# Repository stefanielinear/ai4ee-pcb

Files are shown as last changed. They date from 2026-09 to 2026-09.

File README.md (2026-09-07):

# ai4ee-pcb

[简体中文](README.zh-CN.md)

A collection of PCB projects that are automatically designed and generated by AI.

All projects are designed in **KiCad**. This repository hosts PCB projects produced by an AI agent (LLM toolchain) end to end — from requirements specification and part selection, through schematic entry, layout and routing, design review, to fabrication file export. Each sub-project lives in its own directory and can be opened directly in KiCad; it ships with the design sources, design documentation, and a fabrication package.

## Sub-projects

| Sub-project | Description | Status | Model / tokens |
| --- | --- | --- | --- |
| [ECG12_Portable](ECG12_Portable/README.md) | Portable 12-lead ECG acquisition board (engineering sample): KiCad 10, 45 × 45 mm 4-layer board, 110 purchased components, 14 test points, 6 double-sided fiducials, Rev B | Routed (native ERC / DRC: 0 violations, 0 unconnected), prototype validation pending | GPT-6 High, ~580k tokens |

## License

[Apache License 2.0](LICENSE)

> ⚠️ Each sub-project is an engineering sample and does **not** represent medical-device certification. For projects that interface with the human body (e.g., ECG), safety and compliance must be assessed separately per the documentation in the sub-project.

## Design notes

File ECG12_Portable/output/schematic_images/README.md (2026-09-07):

# 原理图图片

01_System 至 05_Power 为 300 dpi 阅读版 PNG，保留全部电路和页内说明，裁去空白和图框。full_pages/ 为含完整图框和标题栏的原图。index.html 可逐页浏览；schematic_full.pdf 为此次从当前 KiCad 源文件重新导出的完整 PDF。

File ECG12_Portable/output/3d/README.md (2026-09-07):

# Rev B 3D previews

Generated from the saved Rev B PCB using the native KiCad renderer. 110 package models: 107 standard KiCad models and three visual approximations (U2 module, J2 USB-C, U3 generic QFN). Fourteen test pads and six fiducials have no physical package. Model coverage and source hash are in model_coverage.json. Use manufacturer drawings for mechanical approval.

ECG12_Portable2.kicad_pcb in this directory is a render copy; edit the project-root PCB for design work. Models resolve locally through the models directory.

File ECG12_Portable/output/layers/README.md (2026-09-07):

# PCB 各图层截图

打开 index.html 按层浏览。全部启用层均单独导出，包括空的辅助层；网页默认隐藏空层，勾选开关即可显示。所有图片从顶面观察，底层未镜像，便于各层对齐比较。板框是唯一公共叠加层。F.Mask/B.Mask 显示阻焊开窗；F.Paste/B.Paste 显示焊膏开口。未改变设计源文件。

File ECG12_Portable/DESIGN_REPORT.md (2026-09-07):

# ECG12 Portable2 Rev B 设计报告

## 交付状态与边界

工程、完整布线及生产输出均已生成。板框 45 × 45 mm，4 层，130 个封装，其中 110 个是采购器件、14 个是板上测试触点、6 个是双面光学定位点。原生 ERC 为 0 错误、6 警告；原生 DRC 为 0 项、0 未连接、0 原理图/PCB 差异。没有通过关闭规则或排除真实短路来取得这些结果。

该结论表示设计文件通过所执行的电气/几何检查，**不表示医疗认证、临床适用性或样机性能已经验证**。固件、机壳和临床验证不在本次硬件文件交付内。

## Product Specification / Architecture

| 项目 | 实现 |
|---|---|
| 电极 | RA、LA、LL、V1–V6、RL，共 10 电极 |
| 同步通道 | ADS1298，8 通道、24 bit、500 SPS |
| 导联 | CH1=LA−RA；CH2=LL−RA；CH3–8=V1–V6−WCT |
| 推导导联 | III=II−I；aVR=−(I+II)/2；aVL=I−II/2；aVF=II−I/2 |
| 参考 | 内部 2.4 V；PGA=6，标称差分满量程 ±400 mV |
| 输入范围 | 设计包络 ±300 mV 电极差分直流偏置叠加 ±5 mV ECG；还受共模余量约束 |
| 显示带宽 | 0.5–40 Hz 监护视图；保留原始数据。500 SPS 下 sinc 滤波约在 131 Hz 衰减 3 dB，不声称平坦 150 Hz 诊断带宽 |
| 输入阻抗目标 | ≥10 MΩ @10 Hz，须包含保护元件、PCB 污染及线缆实测 |
| CMRR 目标 | RLD 工作时系统 ≥80 dB @50/60 Hz；不是把芯片指标当作系统保证 |
| 蓝牙 | Raytac MDBT42Q-512KV2，nRF52832，集成晶振、匹配和芯片天线 |
| 缓存 | SoC 64 KiB RAM 中分配 32 KiB 采集环形缓冲；无需外部存储器 |
| 供电 | 带保护的 1S 500 mAh 电池；USB-C 5 V 充电；独立模拟/数字 3.0 V LDO |
| 使用模式 | 患者/电极连接时仅允许电池供电；充电和接地调试时断开电极 |

WCT 三个内部缓冲器分别取 CH1N、CH1P、CH2P；对应 WCT1=0x09、WCT2=0xC2。WCT 输出接六个胸导联负输入，C25 为 100 pF C0G。该值按 TI 数据手册第 40–41 页附近的 WCT 说明及 [TI 的澄清](https://e2e.ti.com/support/data-converters-group/data-converters/f/data-converters-forum/841268/ads1298r-wct-capacitor-100pf-or-1000pf)选择。

## Component Selection / 供应与成本

| 位号 | 实际型号 | 选择依据 |
|---|---|---|
| U1 | ADS1298IPAG | 成熟的同步 ECG AFE，内部参考、WCT、RLD 和导联脱落检测；TQFP 便于检验与返修 |
| U2 | MDBT42Q-512KV2 | nRF52832 模块，将晶振、RF 匹配和天线纳入厂家验证的模块结构 |
| U3 | BQ24074RGTR | 线性充电、电源路径、温度检测、输入限流和安全计时 |
| U4/U5 | TPS7A2030PDBVR | 独立 3.0 V 低噪声 LDO，避免外置开关电源干扰 |
| D1–D10、D21–D23 | TPD1E10B06DYAR | 电极连接器与 USB 侧 ESD 保护 |
| D11–D19 | BAV199,215 | 低漏电输入钳位；明确核对 SOT-23 的 1=A1、2=K2、3=公共端 |
| D24 | BAT54H,115 | USB PGOOD 拉低时抑制 AFE 采集；不是隔离器件 |
| J1/J3 | JST BM10B / BM04B-SRSS-TB | 1 mm 有键连接器，明确电极与电池/NTC 引脚顺序 |
| J2 | HRO TYPE-C-31-M-12 | 仅供电的 USB-C 连接；CC1/CC2 独立 Rd，数据与 SBU 不连接 |

采购字段来自原理图，完整清单见 `production/BOM.csv`。2026-09-06 查询的公开页面显示：[ADS1298IPAG](https://www.digikey.com/en/products/detail/texas-instruments/ADS1298IPAG/2360825) 为 Active，页面库存 435，单件参考价 US$58.94；[MDBT42Q-512KV2](https://www.digikey.com/en/products/detail/raytac/MDBT42Q-512KV2/13677592) 页面库存 18、单件 US$4.95，属于厂家 Marketplace 发货。库存和交期是网页快照，订单前需重新确认。

[TPS7A2030PDBVR](https://www.ti.com/product/TPS7A20/part-details/TPS7A2030PDBVR) 为 Active；TI 直销库存显示不可用，但 [授权渠道页面](https://www.digikey.jp/en/products/detail/texas-instruments/TPS7A2030PDBVR/13566871)列有库存。没有为所有被动器件执行实时逐行库存/API 生命周期审计；此项作为采购阶段限制保留。

单板小批量器件预算暂按 US$75–100 规划，不含电池、线束、PCB、填孔盖铜、贴装、运输和税费。这是预算区间，不是完整供应商报价。AFE 是主要成本；本版优先成熟 ECG 性能和制造可复核性，没有采用未经验证的廉价替代 AFE。填孔盖铜会增加制造费用，须由工厂按实际清单报价。

## Power Budget / 八小时续航

| 项目 | 估算平均电池侧电流 |
|---|---:|
| AFE，包括参考/WCT/RLD 预留 | 4.0 mA |
| MCU 处理 | 3.0 mA |
| BLE 收发折算平均值 | 4.0 mA |
| 稳压器、充电器待机预留 | 0.1 mA |
| 状态灯、分压、其他 | 1.0 mA |
| 合计估算 | 12.1 mA |
| 用于续航设计的保守包络 | **20 mA** |

两路 LDO 的电池电流基本等于负载电流加静态电流，不能再用输出电流直接乘电压比重复折算效率。3.7 V 电池到 3.0 V 的理想功率效率约 81%；以上电池侧预算已经包含其线性损耗的电流特征。

八小时所需有效容量为 20×8=160 mAh。以低压停止、老化、温度和容量离散合计只使用额定 70% 计算，最低额定需求为 160/0.70≈229 mAh；选择 500 mAh，估算 500×0.70/20=17.5 h。相对 8 h 约有 2.19 倍时长裕量。**这是计算，不是续航实测**；固件需在约 3.3 V 低电压时停止采集并进入低功耗状态。

外部原型电池可选 [Adafruit 1578](https://www.adafruit.com/product/1578)（500 mAh，29×36×4.75 mm，自带保护），增加贴附于电芯的 Semitec 103AT-2 10 kΩ NTC 和适配线束。量产电池必须保持 1S 4.2 V 充电、保护板、容量和 NTC 特性，重新验证后才能替换。

USB 使用 100 mA 总输入限流模式。R38 改为 8.66 kΩ、1%，其最大值 8.7466 kΩ 低于推荐上限 8.9 kΩ；标称 ISET 编程值为 102.77 mA，实际充电电流受 100 mA 输入限流、系统负载和电源路径调节限制。R39=68.1 kΩ，按 KTMR=48 s/kΩ 得到标称快充安全计时 9.08 h；电阻与计时系数的静态范围约 6.742–11.464 h，动态降流可能改变实际到期时间。ITERM 未连接时，USB100 模式的标称终止比例为 3.3%，即约 3.39 mA。

自动热分析没有识别出可量化耗散的器件，不能据此称为通过。Rev B 另提供可复算的 `analysis/revB/thermal_engineering_model.json`：USB 5.25 V、电芯 3.0 V、100 mA 包络对应 0.225 W，计入通路和静态电流余量后按 U3=0.25 W；U4/U5 在 VSYS=4.5 V、负载分别 6/14 mA 时约 9.045/21.045 mW。U3 的 θJA=44.5 °C/W 来自数据手册测试板，120 °C/W 是未校准的外壳敏感性场景；40 °C 环境对应估算结温 51.1–70.0 °C。U3 暴露焊盘内已布置四颗 0.60/0.30 mm 接地热过孔，全部填孔盖铜。真实温升、NTC 耦合和外壳散热必须实测；不得据此提高充电限流。

## ECG Data Budget / BLE 与缓存

8×500×24=96 kbit/s 原始 ECG。加每帧 3 字节状态，共 13,500 byte/s；建议再加入时间戳/标志，按 32 byte/frame 即 16,000 byte/s 预算。再预留 10% 序号、CRC 和应用协议开销，需求约 140.8 kbit/s。

要求实测应用层有效吞吐 ≥200 kbit/s。250 ms 聚合 4,000 byte，额外预留 10% 应用协议开销后约 4,400 byte；在 25,000 byte/s 下发送约 176 ms，正常连接时最老样本基础等待加发送约 426 ms。与 1 s 目标相差约 574 ms，供连接事件、重传和调度使用。32 KiB RAM 可容纳约 2.048 s 的 32 字节帧；无线失联不能保证 1 s 延迟。

需要在最终 BLE 栈内存配置下检查链接映射、RAM 水位、MTU/DLE 协商及中央设备兼容性。本次交付完成了容量和带宽可行性计算，没有伪称已经运行过整机 BLE 吞吐测试。

## Analog Layout / 输入、参考和 RLD

电极连接器在左侧，AFE 居中偏左，BLE 天线在右上板边，USB/充电在右下。每个感测电极经过连接器侧 TVS、两个 100 kΩ 0.1% 电阻、低漏电钳位与 C0G 电容。保护/滤波不会把主滤波极点压到 ECG 通带内：按总输入电容约 240 pF、总串联电阻 200 kΩ，极点约 3.32 kHz。两个输入路径的电阻热噪声按 150 Hz 理想砖墙积分约 1.0 µVrms，不包含 AFE、线缆和实际数字滤波响应。

RA 同时接两个 ADC 输入，C1=200 pF；其他输入 C2–C9=220 pF，用于名义补偿输入电容差异。器件内部电容、WCT 取样、线缆和寄生有离散，不能据名义 RC 匹配保证 CMRR；必须实测并确定是否需要匹配/调整电容。 Rev B 将 C1–C9 换为同系列 1% C0G：C1 为 KEMET C0402C201F5GACTU，C2–C9 为 C0402C221F5GACTU。仅含理想 RC 与典型 20 pF 输入电容的 50 Hz 容差例子从 57.40 dB 改善到 70.63 dB；该例子排除了电极、线缆及闭环 RLD/WCT，不能当作系统 CMRR 结果。

钳位器件在背面靠近对应输入，关键电阻串联连接在正面锁定布线。RLD 采用 100 kΩ/100 kΩ、100 nF 外部半电源参考，1 MΩ∥1.5 nF 反馈，以及两个 499 kΩ 串联到 RL。RLD_IN 未使用时接 AVDD；导联脱落检测和 RLD 选路要避免重复计入共享 RA。 R24/C27 已靠近 U1 引脚 61/63：RLD_INV 共 4.188 mm、0 过孔。R28–R30 靠近模块输出脚，其中 R29 前 MCU_SCK 仅 2.090 mm、0 过孔。

## PCB / RF Layout / 可制造性

板框 45×45 mm；名义厚度 1.0 mm；外层铜 35 µm，内层铜 18 µm；F.Cu 信号/器件、In1.Cu 完整接地参考、In2.Cu 信号、电源与 B.Cu 信号/器件。具体介质厚度已经写入工程，工厂可提出等厚标准叠层供复核，不能自行改变铜层顺序。

最小线宽/间距 0.15/0.15 mm；普通过孔焊盘/钻孔 0.60/0.30 mm；铜到板边 ≥0.25 mm。电源主路径在可用位置使用较宽走线；模拟/数字 LDO 输出各有连接到真实焊盘的局部电源铜区。In1 不布信号线，实际接地铜为一个连通区域，面积约 1,837.6 mm²，约占板面积 90.7%；顶/底层地铜通过接地过孔连通。

天线外露部分及模块内部规定的凹形禁布区域在所有铜层都有显式规则区，禁止走线、过孔、焊盘和铺铜。模块自带 RF 匹配和天线，主板没有需单独控制 50 Ω 的 RF 馈线。电池、金属机壳和线束不得进入天线净空范围。BLE SoC 使用 LDO 模式、内部校准 LFRC；高频晶振在模块内部。

填孔盖铜要求逐孔记录于 `production/filled_capped_vias.csv`。该表按钻孔与 SMT 焊盘相交的保守几何条件生成，并在 KiCad 过孔属性中标记 filled/capped；部分位置不位于焊盘中心，但仍有吸锡风险。其余过孔双面盖油。所有贴片器件的方向使用 KiCad 原生坐标导出；底层坐标为从顶面观察的装配坐标，工厂按自身设备规则转换角度。针脚 1、USB 外壳、J1/J3 键位、BAV199 极性以及 QFN 暴露焊盘均按网表、封装和数据手册交叉核对。

85 个位号放在丝印，其余保留在完整装配图。新增正反面各三个非共线定位点；USB-C 定位孔中心到下板边按厂家图修正为 5.79 mm。电池与线束通过外部固定结构定位；板上没有安装孔。

## ERC / DRC 与检查依据

| 检查 | 结果/依据 |
|---|---|
| KiCad 原生 ERC | 0 错误，6 警告；最终 JSON 随生产包提供 |
| KiCad 原生 DRC | 0 违规，0 未连接；重新铺铜后运行 |
| 原理图/PCB 一致性 | 原生 schematic parity 0 项 |
| 原理图/PCB 原生端点核对 | 124 个原理图器件（含 14 个测试点）、390 个网表端点，端点网络差异 0；另有 6 个 board-only 定位点 |
| 原理图新增节点 | 六个测试点使用原生符号、导线和全局网络标签，ERC 与原生网表校验通过 |
| SPICE | 已执行自动子电路仿真；输入小电容被误判为去耦的警告在下文处理 |
| KiCad/PCB/跨域/EMC/热分析器 | 均实际运行，原始结果保留；热工具无耗散数据而跳过数值估算 |
| Gerber/Drill | 已实际导出并解析检查；文件非空、铜层/孔数据存在 |
| 原始数据手册检查 | 逐脚核对主 IC 的供电、保留脚、时钟、参考、充电设定和模块外部元件要求 |

6 项 ERC 警告全部保留：U1 引脚 17、18 按 [ADS1298 数据手册](https://www.ti.com/lit/ds/symlink/ads1298.pdf)“未用引脚接 AVDD”的脚注处理，固件必须关闭 PACE 输出；引脚 42、44、45、46 接地，GPIO 必须保持输入。没有把这些双向引脚类型改成被动脚来隐藏提示。

## EMC / 分析器结果的工程复核

EMC 分析器不是医疗 EMC 认证工具，其数值评分不作为放行证据。未删除原始 finding，也未把所有启发式提示当作真实阻断项：

- GP-001 / RP-001 将 USB_PGOOD 按名称当成高速 USB 信号；实际为 10 kΩ 上拉的开漏插拔状态线。这两项的高速风险分类不适用。
- GP-004 的低铺铜比主要来自正面地铜被器件和信号分割；原始 PCB 中 In1 地平面约 90% 覆盖、单一连通区域。不能用正面约 56% 的铺铜比例代替内层参考面。
- In2 与 B.Cu 为相邻信号层是实际叠层折中。主参考面为 In1，顶/底有地铜；SPI 应限制在约 1 MHz 并保留源端 33 Ω。这项残余串扰/辐射风险留待实测。
- AFE_SCK、MCU_SCK 等个别换层点在 1 mm 内放不下接地过孔；已补可放置的回流过孔，其余位置、最近地过孔距离保留在 `return_stitching.json`。部分为同一 In1 参考面的两侧换层，不能等同于跨分割地，但仍应测试 BLE 发射期间的干扰和 EMC。
- J1 没有把系统 GND 作为患者接口引出；RL 是受限流的患者偏置，这是有意的接口定义。
- SPICE 把 220 pF 的 C4–C9 当作电源去耦，故给出高阻抗警告；这些实际是输入 RF 滤波电容，该去耦判据不适用。RLD 的芯片内部放大器没有完整厂商宏模型，因此不能用被动子电路仿真声称 RLD 稳定性已通过。
- 自动热过孔规则按通用高功耗封装建议更多过孔。本版是 100 mA 线性充电，采用实际 EP 接地过孔和局部地铜，并以保守温升计算与样机温升测试控制风险。

## Manufacturing Output / 样机验证

`production/gerber/` 包含 4 个铜层、双面阻焊/丝印/钢网层、板框及 Gerber job；`production/drill/` 包含分离的 PTH/NPTH 钻孔和孔位图；另有 BOM、贴片坐标、裸板电测网表、原理图与装配 PDF、填孔盖铜表和工厂说明。

样机必须验证：短路输入噪声、CMRR、输入阻抗、直流偏置/共模极限、lead-off、RLD 稳定性、50/60 Hz 抑制、天线与外壳/电池耦合、BLE TX 对 ECG 的影响、ESD/EMI、实际吞吐和最大样本年龄、RAM 溢出处理、≥8 h 续航、充电终止/计时与温升。USB 充电期间的信号/干扰测试只用 ECG 模拟器，不能接人体。该板不具备 USB 医疗隔离、除颤或电外科保护，不声称满足任何医疗法规。

## Rev B 电源电容与剩余审查风险

C31/C34–C37 改为 TDK 4.7 µF/16 V/X5R/0603；C32/C33 改为 TDK 22 µF/25 V/X5R/0805。逐料号偏压曲线、工程折算条件和验收下限见整改报告。RLD、CMRR、有效电容及充电温升必须按样机计划验收。最新 EMC 启发式结果及其原生几何交叉检查也在整改报告中，不能沿用旧版数值评分代替本版结论。

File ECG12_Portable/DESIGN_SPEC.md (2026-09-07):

# ECG12 Portable2 — Revision B design specification

Status: routed engineering prototype; native ERC has 0 errors/6 reviewed warnings, DRC has 0 violations/0 unconnected/0 parity differences. System acceptance requires bench verification. Not medically certified.

## Requirements and decisions

- Ten electrodes: RA, LA, LL, V1–V6 and RL. ADS1298IPAG measures I=LA−RA, II=LL−RA and six chest leads relative to its internal Wilson central terminal. Firmware derives III=II−I, aVR=−(I+II)/2, aVL=I−II/2, aVF=II−I/2.
- 500 samples/s/channel, simultaneous 24-bit acquisition; low-power converter mode, internal oscillator. Nominal 0.5–40 Hz monitoring display, with raw samples retained. The converter sinc response is about -3 dB at 131 Hz at 500 SPS; a flat 150 Hz diagnostic bandwidth is not claimed. A 1 kSPS mode requires a revised data/power budget.
- 3.0 V analog supply, 2.4 V internal reference, nominal PGA gain 6: differential ADC full-scale ±400 mV, subject to input common-mode headroom. Electrode DC offset and saturation recovery require prototype verification.
- Input impedance target ≥10 MΩ at 10 Hz; CMRR target ≥80 dB at 50/60 Hz with RLD (system targets, not proven results). Matched input RC filtering, low-leakage clamps, current limiting and internal lead-off detection. Internal RLD amplifier, compensated feedback, two series patient-bias resistors. Component/parasitic capacitance matching must be characterized on prototypes.
- RF module with nRF52832, 64 KiB RAM, 512 KiB flash, integrated high-frequency crystal, matching and chip antenna. Internal low-frequency RC clock with calibration. No external data flash.
- 8×500×24=96 kbit/s raw ECG; including 24-bit status each frame gives 13,500 byte/s. Allocate 32 KiB circular acquisition buffer. Packetize every 250 ms, require ≥200 kbit/s measured application payload throughput. A 32-byte application record plus 10% overhead gives 4,400 bytes per 250 ms batch, draining in 176 ms at that service rate; nominal oldest-sample delivery is 426 ms plus connection/retry delays. ≤1 s is an acceptance target under a specified compatible BLE central; outage cannot guarantee latency.
- 1S protected rechargeable Li-polymer battery, minimum 500 mAh, 10 kΩ NTC coupled to cell. USB-C is 5 V charging only, two independent 5.1 kΩ Rd resistors, data pins unconnected. Charger with power-path and cell temperature monitoring; conservative default USB current limit.
- Independent low-noise analog 3.0 V and digital 3.0 V LDOs. Battery low-voltage stop target 3.3 V; usable-capacity derating accounts for cutoff, temperature and aging.
- Preliminary battery-current budget: AFE 4 mA, MCU 3 mA, BLE 4 mA average, regulators 0.1 mA, miscellaneous 1 mA =12.1 mA. Use 20 mA engineering design envelope; 500 mAh×0.70/20 mA=17.5 h estimated runtime, over 2× eight-hour requirement. Must be measured with final firmware, cell and RF link.
- Board 45×45 mm maximum, four copper layers: front components/signals, continuous inner GND, inner power/slow signals, back signals/GND. 1.0 mm nominal stack, 35 μm outer copper; fabricator must confirm final dielectric stack.
- Initial routing limits: 0.15 mm trace/clearance, 0.6/0.3 mm through vias; power wider where space permits. Inner GND reserved for return continuity. No copper, vias or traces in antenna keepout on any layer.
- Interfaces: keyed ten-electrode connector, keyed battery/NTC connector, USB-C, SWD programming/test pads, status LED and battery voltage measurement.
- Charging is a non-patient-connected mode: no galvanic USB isolation is included. Enclosure/workflow must prevent patient connection while USB or a grounded programmer is attached. Hardware is not defibrillator protected or suitable for electrosurgery. Simulator-only testing precedes any patient use.

## Acceptance evidence required

Editable local KiCad symbols/footprints; native schematic-to-board net correspondence; complete routing; filled planes; native ERC and DRC reports; BOM/positions/Gerber/drill exports; schematic and fabrication/assembly PDFs; explicit remaining prototype tests for noise, CMRR, lead-off, RLD stability, antenna, ESD/EMC, charging thermal behavior and runtime.

## Revision B implementation

Three fiducials per side; 14 test contacts including six new analog/power nodes; USB locating-hole-to-edge datum 5.79 mm; 8.66 kΩ RISET; 9.08 h nominal timer; 3.3% USB100 termination; 1% C0G input capacitors; upgraded MLCCs with documented bias margins; local RLD and source-SPI routing; four filled/capped charger EP vias. See REV_B_OPTIMIZATION_REPORT.md for measurements and remaining acceptance work.

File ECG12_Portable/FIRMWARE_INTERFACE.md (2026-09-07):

# Firmware integration contract — ECG12 Portable2 Rev B

This is a hardware interface/acceptance specification, not tested firmware.

| Function | nRF52832 GPIO / module pin |
|---|---|
| AFE CS, SCK, MOSI | P0.11/25, P0.12/26, P0.13/27 via 33 ohm series resistors |
| AFE MISO, DRDY | P0.14/28, P0.15/29 |
| AFE RESET, PWDN | P0.16/30, P0.17/31 |
| USB PGOOD, charge status | P0.25/2, P0.26/3; active low, external 10k pull-ups |
| Battery ADC | P0.31/8; 1M/1M divider, 10nF filter; Vbat=2×Vadc |
| Status LED | P0.22/38, active-low sink through fitted resistor/LED |
| Reset, SWDCLK, SWDIO | P0.21/35, dedicated pins 36 and 37 |
| UART TX/RX | P0.06/19, P0.07/20 |

TP1..TP8: DVDD, GND, SWDCLK, SWDIO, MCU_RESET, UART_TX, UART_RX, AFE_CLK.

TP9..TP14 (back side): VBAT, VSYS, AVDD, VREF, RLD_REF, RLD_OUT. Use high-impedance, low-capacitance probes on analog nodes.

Rev B charging: USB100 is a 100 mA total input limit. RISET=8.66 kΩ programs 102.77 mA nominal; USB100 default termination is about 3.39 mA (3.3%). RTMR=68.1 kΩ gives a nominal 9.08 h fast-charge safety timer; static factor/resistor range 6.742–11.464 h, with dynamic timer behavior to be verified.

1. Use the module in LDO mode. External DCC network is absent. Configure the calibrated internal low-frequency RC oscillator; the module's shipped factory test firmware must be replaced. Its internal 32 MHz oscillator and DEC4 bypass are already fitted.
2. Configure ADS1298 for low-power 500 SPS, internal clock, 2.4 V internal reference, gain 6 and eight active normal-input channels. Verify readback of all registers. START pin is low: issue SPI START/STOP commands. Read the complete 27-byte status+sample frame per DRDY. Use approximately 1 MHz SPI initially.
3. WCT1=0x09 and WCT2=0xC2 enable RA=CH1N, LA=CH1P, LL=CH2P. CH3–8 negative inputs are physically tied to WCT. Internal augmented-lead switches remain disabled. Derive III/aVR/aVL/aVF digitally.
4. RLD uses external half-supply reference and external compensation. Select limb electrodes without repeatedly counting shared RA. Start with lead-off disabled for noise/CMRR characterization; enable only after verifying currents and thresholds on the simulator.
5. U1 PACE/test pins 17/18 are tied to AVDD; keep their output drivers disabled. GPIO1–4 are tied to GND and must remain inputs. DAISY_IN and RESV1 are grounded.
6. Stop acquisition whenever USB_PGOOD is low. D24 provides a hardware pull-down path to AFE_PWDN; it does not provide galvanic isolation. Use high-impedance MCU behavior compatible with this clamp rather than actively driving PWDN high against it. Disconnect electrodes for USB/debug operations.
7. Reserve 32 KiB for a bounded ring buffer. Budget a 32-byte application record (24 sample bytes, 3 status bytes, timestamp/flags). Flush every 250 ms. Verify BLE stack RAM, stack/heap headroom and linker placement on the actual 64 KiB device.
8. Negotiate suitable MTU/data length; require measured application throughput >=200 kbit/s. Timestamp and sequence every batch, account for CRC/protocol overhead, reject stale data, report sequence gaps. Under the validated connected-link test condition, maximum delivered sample age must stay <=1 s. No such guarantee is possible during disconnection.
9. Observe battery voltage, stop around 3.3 V under load with hysteresis, and enter low power. Test cell recovery, reconnect, brownout and interrupted-transfer behavior.
10. Verify at least 8 hours runtime with full-rate ECG, worst intended BLE use, chosen cell, representative aging/temperature and final enclosure.

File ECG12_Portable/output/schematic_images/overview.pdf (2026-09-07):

# ECG12 Portable2 - Schematic pages

# Five pages | Individual PNG files at 300 dpi | Full drawing sheets also included

# 01 System

# Inputs

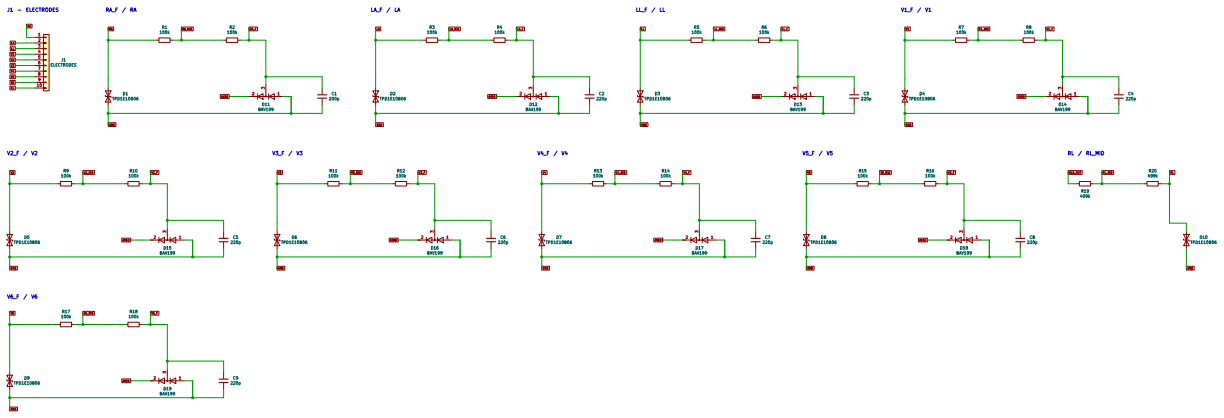
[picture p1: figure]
TPD1E10B06; TPD1E10B06 D7; 3 D13 BAV199; 3 D14 BAV199 D4; J1 ELECTRODES; 3 D11 BAV199 C8; 3 D18 BAV199; 3 D17 BAV199 R16; TPD1E10B06 R9; 3 D15 BAV199 R18; 3 D19 BAV199 R11; 3 D12 BAV199 D6; 3 D16 BAV199 C6; GND; V1_MID; RL_MID; LL_MID; AVDD; RA_MID; RLD_OUT RA_F; LA_MID; V5_MID; V2_MID; V3_MID; RL V6GND; V6_MID; V6_F GND; V4_MID; GND J1 - ELECTRODES; RL / RL_MID

# File: Inputs.kicad_sch

# AFE

# File: AFE.kicad_sch Digital File: Digital.kicad_sch

Power File: Power.kicad_sch 12-lead portable ECG — 10 electrodes, 8 simultaneous 24-bit channels

# 45 x 45 mm, 4 layers; protected 1S cell; USB-C charging; BLE batches <=1 s target

Read DESIGN_SPEC.md and DESIGN_REPORT.md before prototype assembly.

Only connect electrodes when running from battery; USB/programming requires electrode removal.

02 Inputs | D3

ELECTRODE PROTECTION / MATCHED RF FILTERS

RA/LA/LL and V1-V6: TVS -> 2x100k -> low-leakage clamp -> C0G -> AFE. V2_F / V2

All C0G capacitors 50 V. Match total input capacitance during CMRR verification. RL: 2x499k series output limit. No defibrillator or electrosurgical protection. RA_F / RA

03 AFE | C18

22u C25

100p

## #FLG6 PWR_FLAG

R22
100k | C26

100n C15

100n | C17 1u

## IN8N 1

## IN8P 2

## IN7N 3

## IN7P 4

## IN6N 5

## IN6P 6

## IN5N 7

## IN5P 8

## IN4N 9

## IN4P 10

## IN3N 11 IN3P 12

## IN2N 13 IN2P 14

## IN1N 15 IN1P 16

## TESTP_PACE_OUT1 17

# TESTP_PACE_OUT2 18 AVDD 19 AVSS 20

## VREFP 24 VREFN 25

## VCAP4 26

## VCAP1 28

VCAP2 30 | RESV1 31 DGND 33 | DIN 34 PWDN 35 RESET 36 CLK 37

## START 38 CS 39

SCLK 40 DAISY_IN 41 GPIO1 42 DOUT 43 GPIO2 44 GPIO3 45 GPIO4 46 DRDY 47 DVDD 48 | CLKSEL 52 AVSS1 53 AVDD1 54
VCAP3 55 | RLDREF 60 RLDINV 61 RLDIN 62 RLDOUT 63 WCT 64 U1

## ADS1298IPAG

C13
100n R27

10k C11
100n C22

100n

TP11 | TP12 | C24 1u
TP13 | C19 1u
TP14 | R24
1M C21

10u C10
100n | C27

1.5n R23

100k | C20

1u C12
100n R26

10k R21

100 | C14
1u R25
10k | C16
100n C23

100n

RA_F

V5_F

AFE_PWDN

LA_F

AFE_MOSI V3_F

VCAP1

VCAP2

VCAP3

V1_F

AFE_SCK

LL_F | RLD_INV

AVDD

AFE_CLK

# V6_F GND

AFE_DRDY

VCAP1 GND

DVDD

V2_F

V4_F | RLD_OUT | GND

VREF

VCAP4

AVDD

# AFE_MISO AVDD_CP

DVDD

RLD_REF

AFE_RESET | VCAP2 | VCAP3 GND
GND | WCT GND

VREF

AFE_CS

AVDD

RLD_REF DVDD

GND

VCAP4

AFE_CS WCT | AFE_PWDN

RLD_INV

AVDD | VREF
AVDD | AVDD_CP | RLD_OUT RLD_REF
AFE_RESET | RLD_OUT

GND

# Internal bypass nodes

Charge pump supply filter | RLD compensated feedback
WCT1=0x09, WCT2=0xC2: RA=CH1N, LA=CH1P, LL=CH2P. | AFE control defaults

# Patient bias reference

Internal VREF=2.4 V, GAIN=6; 500 SPS monitoring (sinc response is not flat to 150 Hz). CH1=LA-RA, CH2=LL-RA; CH3-8=V1-V6 minus WCT. | Internal 2.4V reference
START pin low: use SPI START/STOP commands. Keep unused GPIO inputs. | Analog supply bypass bank | Digital supply bypass bank
8-CHANNEL SYNCHRONOUS AFE / RLD / WILSON TERMINAL | Wilson central terminal
Synchronous ECG converter | 04 Digital | TP5 MCU_RESET R32

1M

## TP7 UART_RX R28

33 | R34
1k R31

10k

TP3

## SWDCLK GND

## 1 P0.25 2 P0.26 3 P0.27 4

## AIN4/P0.28 5 AIN5/P0.29 6 AIN6/P0.30 7

# AIN7/P0.31 8 DEC4

## 9 DCC 10 VDD 11

## P0.00/XL1 13 P0.01/XL2 14

## AIN0/P0.02 15 AIN1/P0.03 16 AIN2/P0.04 17

AIN3/P0.05 18 P0.06 19 P0.07 20 P0.08 21 NFC1/P0.09 22 NFC2/P0.10 23 P0.11 25 P0.12 26 P0.13 27

## TRACEDATA3/P0.14 28 TRACEDATA2/P0.15 29 TRACEDATA1/P0.16 30 P0.17 31

## TRACEDATA0/P0.18 32 P0.19 33

## TRACECLK/P0.20 34 P0.21/RESET 35

## SWDCLK 36

SWDIO 37 | P0.22 38 P0.24 40 P0.23 41 U2 MDBT42Q-512KV2 | C29

100n R30

33 R29
33 | C30

10n R33
1M

## TP2 GND

## TP1 DVDD

C28
10u

TP8

## AFE_CLK

## D20 GREEN

TP4

## SWDIO

## TP6 UART_TX

## UART_RX

## AFE_SCK

## GND UART_TX

AFE_MOSI MCU_RESET | AFE_CS

## LED_K USB_PGOOD

DVDD | VBAT DVDD

## SWDCLK

## DVDD

## BAT_SENSE GND

## SWDIO

# BAT_SENSE MCU_SCK

# AFE_RESET AFE_DRDY CHG_STAT AFE_MISO

LED_K MCU_RESET | SWDIO
AFE_CLK MCU_MOSI | LED_A GND UART_TX MCU_CS

# SWDCLK UART_RX

# AFE_PWDN BLE module and SPI termination

Maximum 1 s data-age target requires compatible central and bounded radio retries. 32 KiB RAM ring, batch every 250 ms; measured payload target >=200 kbit/s. | Battery voltage monitor | Status LED

# Programming and test contacts

Firmware: LDO mode, calibrated LFRC; no external DCC/DEC4 network. BLE OPEN-CPU MODULE / BUFFERING / TEST

05 Power | R37
CC1 | PowerPath charger and cell temperature

## USB-C CHARGING / POWER PATH / DUAL LOW-NOISE LDO

100 mA USB input limit; 102.77mA nominal ISET programming, limited by input/load. Protected 500 mAh 1S pack with thermally coupled 10k NTC is mandatory. USB PGOOD diode forces AFE power-down. This is an acquisition interlock, not isolation. USB-C 5V input and CC protection | 3V analog low-noise supply

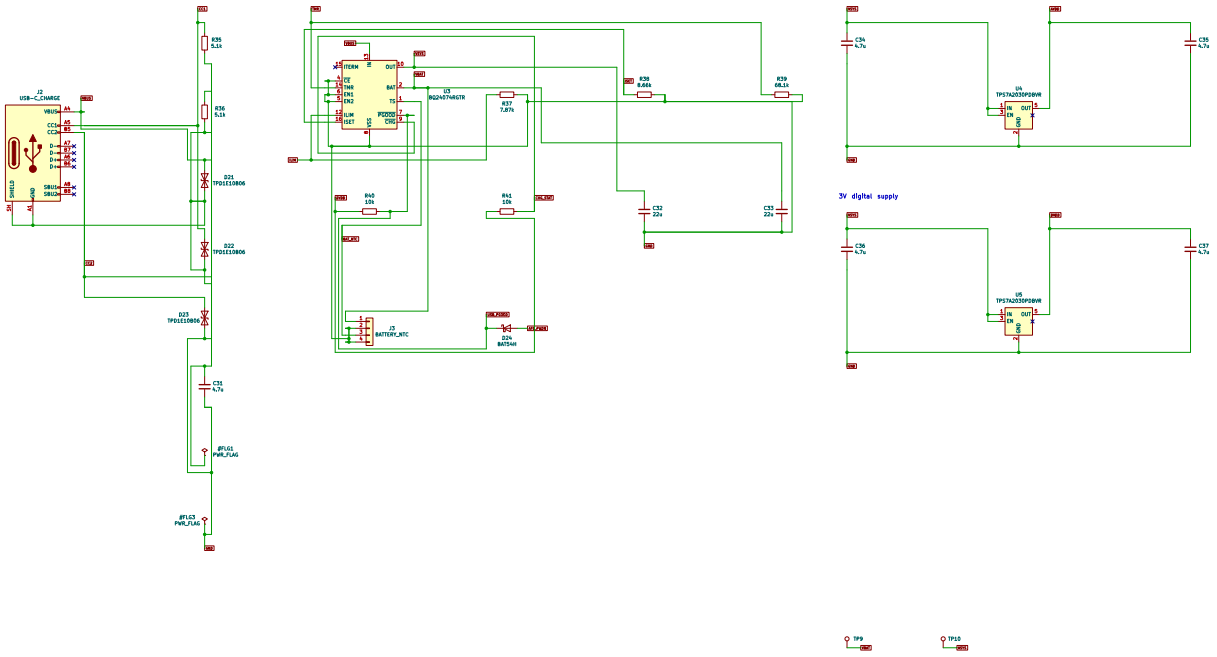
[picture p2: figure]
GND; OUT 5 U4; TPS7A2030PDBVR; TS 1 BAT 2 CE 4; PGOOD 7 VSS; 8 CHG 9 OUT 10; ILIM 12; TMR 14; ITERM 15; ISET 16; U3 BQ24074RGTR; TPD1E10B06; 4.7u GND A1; VBUS; SBU1; SBU2 B8 SHIELD SH; J2 USB-C_CHARGE; OUT 5 U5; J3 BATTERY_NTC; D24 BAT54H; C32 22u #FLG3 PWR_FLAG; C35 4.7u #FLG1 PWR_FLAG; AVDD; DVDD; VBUS DVDD; BAT_NTC; ISET; VSYS; VSYS USB_PGOOD; VSYS CC2; VBAT; TMR; VBAT VBUS; ILIM; CHG_STAT GND; AFE_PWDN; 3V digital supply

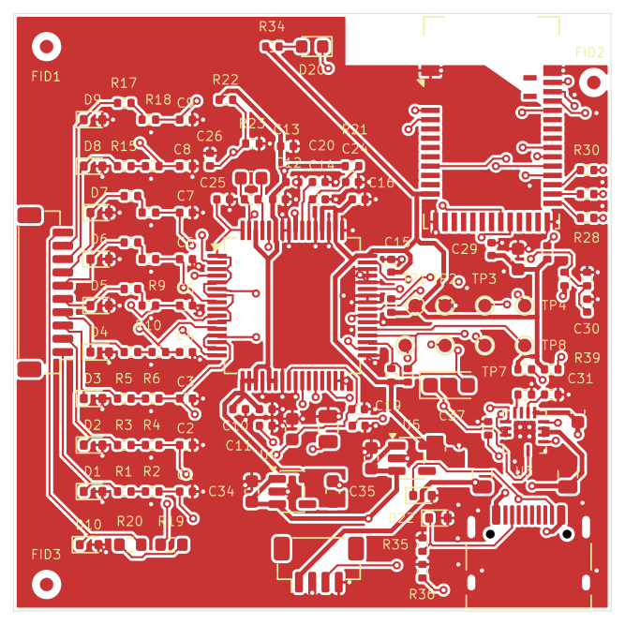
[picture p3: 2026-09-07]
ECG12_Portable/production/drawings/pcb_front.png

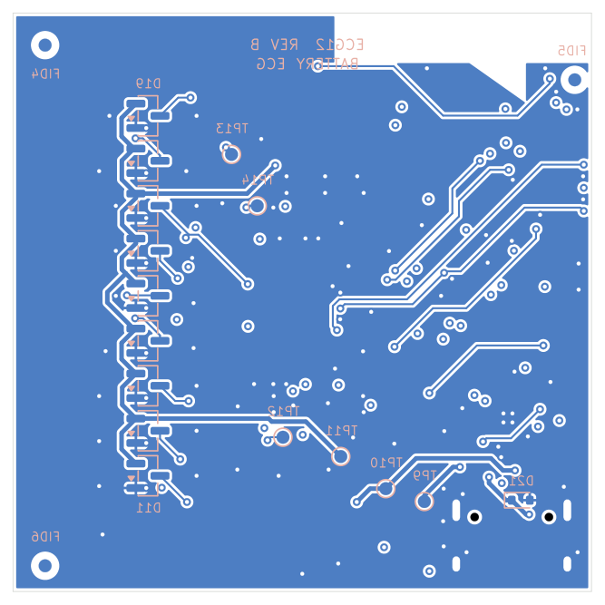
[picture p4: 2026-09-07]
ECG12_Portable/production/drawings/pcb_back.png

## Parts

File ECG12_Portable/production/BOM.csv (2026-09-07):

References | Quantity | Value | Footprint | MPN | Manufacturer | Datasheet | Notes
C1 | 1 | 200p | ECG12:Capacitor_SMD_C_0402_1005Metric | C0402C201F5GACTU | KEMET | https://search.kemet.com/component-documentation/download/specsheet/C0402C201F5GACTU | Rev B: C0G, 1%, 50V; same KEMET family. Nominal RA loading compensation retained; system CMRR requires measurement.
C2-C9 | 8 | 220p | ECG12:Capacitor_SMD_C_0402_1005Metric | C0402C221F5GACTU | KEMET | https://search.kemet.com/component-documentation/download/specsheet/C0402C221F5GACTU | Rev B: C0G, 1%, 50V; same KEMET family. Nominal RA loading compensation retained; system CMRR requires measurement.
C10-C13,C15,C16,C22,C23,C26,C29 | 10 | 100n | ECG12:Capacitor_SMD_C_0402_1005Metric | GRM155R71C104KA88D | Murata | https://www.murata.com/en-us/products/capacitor/ceramiccapacitor
C14,C17,C19,C24 | 4 | 1u | ECG12:Capacitor_SMD_C_0402_1005Metric | GRM155R61A105KE15D | Murata | https://www.murata.com/en-us/products/capacitor/ceramiccapacitor
C18 | 1 | 22u | ECG12:Capacitor_SMD_C_0805_2012Metric | GRM21BR60J226ME39L | Murata | https://www.murata.com/en-us/products/capacitor/ceramiccapacitor
C20 | 1 | 1u | ECG12:Capacitor_SMD_C_0402_1005Metric | GRM155R61A105KE15D | Murata | https://www.murata.com/en-us/products/capacitor/ceramiccapacitor | Local AFE bypass; VCAP3 rated 10 V for boosted internal node.
C21,C28 | 2 | 10u | ECG12:Capacitor_SMD_C_0603_1608Metric | GRM188R60J106ME47D | Murata | https://www.murata.com/en-us/products/capacitor/ceramiccapacitor
C25 | 1 | 100p | ECG12:Capacitor_SMD_C_0402_1005Metric | GRM1555C1H101JA01D | Murata | https://www.murata.com/en-us/products/capacitor/ceramiccapacitor
C27 | 1 | 1.5n | ECG12:Capacitor_SMD_C_0603_1608Metric | GRM1885C1H152JA01D | Murata | https://www.murata.com/en-us/products/capacitor/ceramiccapacitor | Rev B local RLD compensation parallel to R24. Validate cable/electrode loop stability.
C30 | 1 | 10n | ECG12:Capacitor_SMD_C_0402_1005Metric | GRM155R71C103KA01D | Murata | https://www.murata.com/en-us/products/capacitor/ceramiccapacitor
C31,C34-C37 | 5 | 4.7u | ECG12:Capacitor_SMD_C_0603_1608Metric | C1608X5R1C475K080AC | TDK | https://product.tdk.com/system/files/dam/doc/product/capacitor/ceramic/mlcc/charasheet/c1608x5r1c475k080ac.pdf | Rev B: 4.7uF16V X5R0603; effective-capacitance characterization included in datasheets/revB; verify lot/DC bias margin.
C32,C33 | 2 | 22u | ECG12:Capacitor_SMD_C_0805_2012Metric | C2012X5R1E226M125AC | TDK | https://product.tdk.cn/system/files/dam/doc/product/capacitor/ceramic/mlcc/charasheet/c2012x5r1e226m125ac_20190710.pdf | Rev B: 22uF25V X5R0805; 50% bias retention x80% tolerance x85% temperature x80% aging gives 5.984uF. Typical curve only; lot acceptance >=4.7uF effective at operating bias required.
D1-D9 | 9 | TPD1E10B06 | ECG12:Diode_SMD_D_SOD-523 | TPD1E10B06DYAR | Texas Instruments | https://www.ti.com/lit/ds/symlink/tpd1e10b06.pdf | Connector-side ESD. No defibrillator protection.
D10,D21-D23 | 4 | TPD1E10B06 | ECG12:Diode_SMD_D_SOD-523 | TPD1E10B06DYAR | Texas Instruments | https://www.ti.com/lit/ds/symlink/tpd1e10b06.pdf
D11-D19 | 9 | BAV199 | ECG12:Package_TO_SOT_SMD_SOT-23 | BAV199,215 | Nexperia | https://assets.nexperia.com/documents/data-sheet/BAV199.pdf | Pin 1 A1=GND; pin 2 K2=AVDD; pin 3 junction=input.
D20 | 1 | GREEN | ECG12:LED_SMD_LED_0603_1608Metric | LTST-C190KGKT | Lite-On | https://optoelectronics.liteon.com/upload/download/DS22-2000-221/LTST-C190KGKT.pdf
D24 | 1 | BAT54H | ECG12:Diode_SMD_D_SOD-123F | BAT54H,115 | Nexperia | https://assets.nexperia.com/documents/data-sheet/BAT54H.pdf | USB PGOOD low inhibits acquisition. This is NOT galvanic isolation.
J1 | 1 | ELECTRODES | ECG12:Connector_JST_JST_SH_BM10B-SRSS-TB_1x10-1MP_P1.00mm_Vertical | BM10B-SRSS-TB(LF)(SN) | JST | https://www.jst-mfg.com/product/pdf/eng/eSH.pdf | 1 RA; 2 LA; 3 LL; 4-9 V1-V6; 10 RL. Keyed external patient cable.
J2 | 1 | USB-C_CHARGE | ECG12:Connector_USB_USB_C_Receptacle_HRO_TYPE-C-31-M-12 | TYPE-C-31-M-12 | HRO | https://datasheet.lcsc.com/datasheet/pdf/9e56b777c022540fcce7c7f67825f55e.pdf?productCode=C165948 | Rev B: locating-hole center to bottom PCB edge=5.79mm per manufacturer drawing. Charge only; independent CC Rd. Verify cable/enclosure mating on prototype.
J3 | 1 | BATTERY_NTC | ECG12:Connector_JST_JST_SH_BM04B-SRSS-TB_1x04-1MP_P1.00mm_Vertical | BM04B-SRSS-TB(LF)(SN) | JST | https://www.jst-mfg.com/product/pdf/eng/eSH.pdf | Protected 1S 500mAh cell; 10k 103AT NTC cell coupled. Pin1 +, pin2 -, pin3 NTC, pin4 NTC return.
R1,R3,R5,R7,R9,R11,R13,R15,R17 | 9 | 100k | ECG12:Resistor_SMD_R_0402_1005Metric | RT0402BRD07100KL | Yageo | https://www.yageo.com/upload/media/product/productsearch/datasheet/rchip/pyu-rc-group-51.pdf | 0.1%, 25 ppm/K; electrode current limit stage 1
R2,R4,R6,R8,R10,R12,R14,R16,R18 | 9 | 100k | ECG12:Resistor_SMD_R_0402_1005Metric | RT0402BRD07100KL | Yageo | https://www.yageo.com/upload/media/product/productsearch/datasheet/rchip/pyu-rc-group-51.pdf | 0.1%, 25 ppm/K; electrode current limit stage 2
R19 | 1 | 499k | ECG12:Resistor_SMD_R_0603_1608Metric | RC0603FR-07499KL | Yageo | https://www.yageo.com/upload/media/product/productsearch/datasheet/rchip/pyu-rc-group-51.pdf | Patient bias current limiting; two independent series resistors.
R20 | 1 | 499k | ECG12:Resistor_SMD_R_0603_1608Metric | RC0603FR-07499KL | Yageo | https://www.yageo.com/upload/media/product/productsearch/datasheet/rchip/pyu-rc-group-51.pdf
R21 | 1 | 100 | ECG12:Resistor_SMD_R_0402_1005Metric | RC0402FR-07100RL | Yageo | https://www.yageo.com/upload/media/product/productsearch/datasheet/rchip/pyu-rc-group-51.pdf
R22,R23 | 2 | 100k | ECG12:Resistor_SMD_R_0402_1005Metric | RC0402FR-07100KL | Yageo | https://www.yageo.com/upload/media/product/productsearch/datasheet/rchip/pyu-rc-group-51.pdf
R24 | 1 | 1M | ECG12:Resistor_SMD_R_0402_1005Metric | RC0402FR-071ML | Yageo | https://www.yageo.com/upload/media/product/productsearch/datasheet/rchip/pyu-rc-group-51.pdf | Rev B local RLD feedback adjacent to U1 pins61/63; keep summing node short.
R25-R27,R31,R40,R41 | 6 | 10k | ECG12:Resistor_SMD_R_0402_1005Metric | RC0402FR-0710KL | Yageo | https://www.yageo.com/upload/media/product/productsearch/datasheet/rchip/pyu-rc-group-51.pdf
R28-R30 | 3 | 33 | ECG12:Resistor_SMD_R_0402_1005Metric | RC0402FR-0733RL | Yageo | https://www.yageo.com/upload/media/product/productsearch/datasheet/rchip/pyu-rc-group-51.pdf | Source termination adjacent to MCU; 1-2 MHz SPI.
R32,R33 | 2 | 1M | ECG12:Resistor_SMD_R_0402_1005Metric | RC0402FR-071ML | Yageo | https://www.yageo.com/upload/media/product/productsearch/datasheet/rchip/pyu-rc-group-51.pdf
R34 | 1 | 1k | ECG12:Resistor_SMD_R_0402_1005Metric | RC0402FR-071KL | Yageo | https://www.yageo.com/upload/media/product/productsearch/datasheet/rchip/pyu-rc-group-51.pdf
R35,R36 | 2 | 5.1k | ECG12:Resistor_SMD_R_0402_1005Metric | RC0402FR-075K1L | Yageo | https://www.yageo.com/upload/media/product/productsearch/datasheet/rchip/pyu-rc-group-51.pdf
R37 | 1 | 7.87k | ECG12:Resistor_SMD_R_0402_1005Metric | RC0402FR-077K87L | Yageo | https://www.yageo.com/upload/media/product/productsearch/datasheet/rchip/pyu-rc-group-51.pdf
R38 | 1 | 8.66k | ECG12:Resistor_SMD_R_0402_1005Metric | RC0402FR-078K66L | Yageo | https://www.yageo.com/upload/media/product/productsearch/datasheet/rchip/pyu-rc-group-51.pdf | Rev B: 8.66k 1%; max 8.7466k below 8.9k. Programmed ICHG typ 102.77mA; USB100 input still limits total current.
R39 | 1 | 68.1k | ECG12:Resistor_SMD_R_0402_1005Metric | RC0402FR-0768K1L | Yageo | https://www.yageo.com/upload/media/product/productsearch/datasheet/rchip/pyu-rc-group-51.pdf | Rev B: 68.1k; nominal fast-charge safety timer 9.08h (KTMR=48s/kohm); static tolerance range 6.742-11.464h.
U1 | 1 | ADS1298IPAG | ECG12:Package_QFP_TQFP-64_10x10mm_P0.5mm | ADS1298IPAG | Texas Instruments | http://www.ti.com/lit/ds/symlink/ads1298.pdf | Gain 6, LP 500 SPS; internal oscillator. START commands via SPI. WCT1=0x09; WCT2=0xC2. Unused GPIO remain inputs.
U2 | 1 | MDBT42Q-512KV2 | ECG12:RF_Module_Raytac_MDBT42Q | MDBT42Q-512KV2 | Raytac | https://www.raytac.com/upload/download_files/38a8a4a0aff945d8484507d60058109b.pdf | LDO mode only; internal LFRC calibrated by BLE stack; DEC4 capacitor internal. Leave DCC/DEC4 externally open. Antenna keepout all copper layers.
U3 | 1 | BQ24074RGTR | ECG12:Package_DFN_QFN_VQFN-16-1EP_3x3mm_P0.5mm_EP1.6x1.6mm | BQ24074RGTR | Texas Instruments | http://www.ti.com/lit/ds/symlink/bq24074.pdf | USB100 mode: 100mA total input limit. ISET typ 102.77mA; ITERM NC in USB100 =3.3% typ, about3.39mA. External10k NTC required. Four EP thermal vias.
U4,U5 | 2 | TPS7A2030PDBVR | ECG12:Package_TO_SOT_SMD_SOT-23-5 | TPS7A2030PDBVR | Texas Instruments | https://www.ti.com/lit/ds/symlink/tps7a20.pdf | 3.0 V fixed low-noise LDO. Pin4 NC.

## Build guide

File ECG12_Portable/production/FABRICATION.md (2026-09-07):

# ECG12 Portable2 Rev B - Fabrication and assembly

Engineering prototype. Native DRC: 0 violations, 0 unconnected, 0 schematic parity differences. Perform bare-board opens/shorts testing with bare_board_test.d356.

- Outline 45.00 × 45.00 mm; nominal finished thickness 1.0 mm; ENIG. Four layers: F.Cu / In1.Cu / In2.Cu / B.Cu. Outer Cu 35 µm, inner Cu 18 µm.
- Nominal stack in mm: mask 0.010 / Cu 0.035 / prepreg 0.110 / Cu 0.018 / core 0.654 / Cu 0.018 / prepreg 0.110 / Cu 0.035 / mask 0.010. Review any factory equivalent before fabrication.
- Minimum track/clearance 0.15/0.15 mm; via land/drill 0.60/0.30 mm; copper-to-edge ≥0.25 mm. No blind or buried vias.
- **28 vias require resin filling, planarization and copper capping.** Use filled_capped_vias.csv and native flags; do not substitute open holes. This includes all four GND thermal vias inside U3's 1.6 × 1.6 mm exposed pad. Other vias are tented on both sides.
- Datum: lower-left board corner, X right/Y up in top view. Gerber, drill, position and fiducial CSV share this datum. Bottom positions remain top-view coordinates; translate rotation to machine convention. Assembly_back.pdf is mirrored for bottom-side viewing.
- BOM.csv has 110 purchased/placed parts: 100 front, 10 back. BOM_ALL.csv additionally contains 14 PCB test contacts. Six board-only optical fiducials and all test contacts are excluded from placement purchase operations. See fiducial_coordinates.csv: three non-collinear marks per side, 1 mm copper, 2 mm mask opening. No solder paste on fiducials or test pads.
- J2 TYPE-C-31-M-12 locating-hole centerline is 5.79 mm from the lower PCB edge. Preserve the manufacturer's hole/slot geometry. Verify the actual connector, plug and enclosure mating before production release. The 3D J2 envelope is illustrative.
- U1 TQFP-64 has no exposed pad. U3 QFN has segmented paste and four filled/capped ground vias. Use supplied front/back paste Gerbers and qualify stencil/reflow for the module, 0402, TQFP, QFN and SOT-23 packages.
- D11–D19 BAV199: pin1 anode/GND, pin2 cathode/AVDD, pin3 junction/signal. D21 is on the back in Rev B. Check USB/JST orientation and all pin1/polarity indicators against fabrication and assembly drawings.
- Retain 0.1% input resistors and **1% C0G C1–C9**. C32/C33 are **22 µF/25 V TDK C2012X5R1E226M125AC**, not the examined 16 V candidate. C31/C34–C37 are 4.7 µF/16 V TDK C1608X5R1C475K080AC. Alternative MLCCs require effective-capacitance validation at bias/temperature.
- R38=8.66 kΩ 1%; R39=68.1 kΩ. USB100 limits total input nominally to 100 mA; 102.77 mA is the nominal current programming value, not a guarantee of actual charging current. Default USB100 termination is about 3.39 mA; nominal timer is 9.08 h.
- No additional copper or metal in the RF keepout on any layer. Keep enclosure, cell and harness clear of the module antenna. Main board has no external RF feedline.
- J3: pin1 VBAT, pin2 GND, pin3 NTC, pin4 NTC return. The protected cell, cell-bonded 10k NTC, patient harness and insulating carrier are external assemblies listed separately. Verify every harness polarity and continuity.
- Never reflow an attached battery or electrode harness. Initial test uses a current-limited supply and ECG simulator. Disconnect electrodes before USB or grounded programming. This board includes no medical USB isolation or defibrillator protection.

Read REV_B_OPTIMIZATION_REPORT.md and DESIGN_REPORT.md for the remaining prototype tests. KiCad 3D package approximations are not controlling mechanical drawings.

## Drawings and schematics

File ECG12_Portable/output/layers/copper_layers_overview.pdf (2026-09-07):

# ECG12 Portable2 - Copper layers

F.Cu | In1.Cu

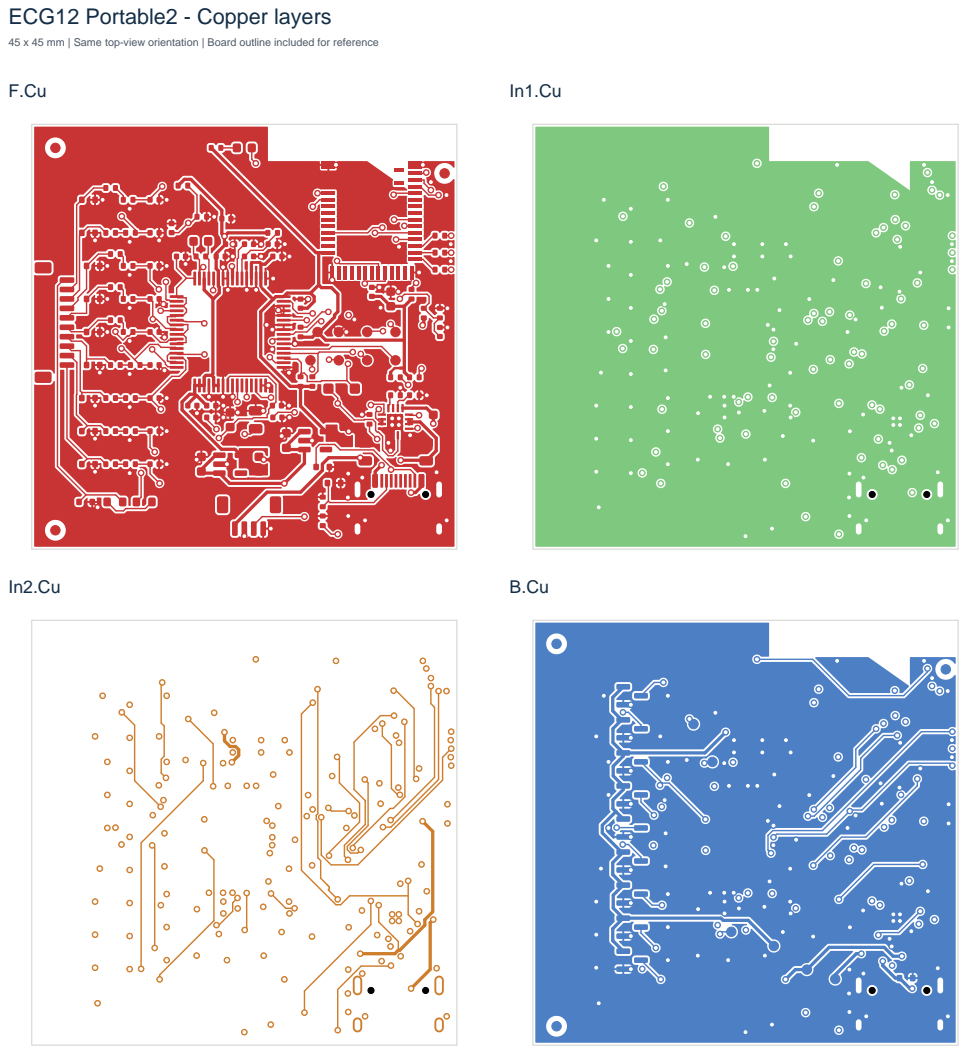
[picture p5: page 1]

45 x 45 mm | Same top-view orientation | Board outline included for reference

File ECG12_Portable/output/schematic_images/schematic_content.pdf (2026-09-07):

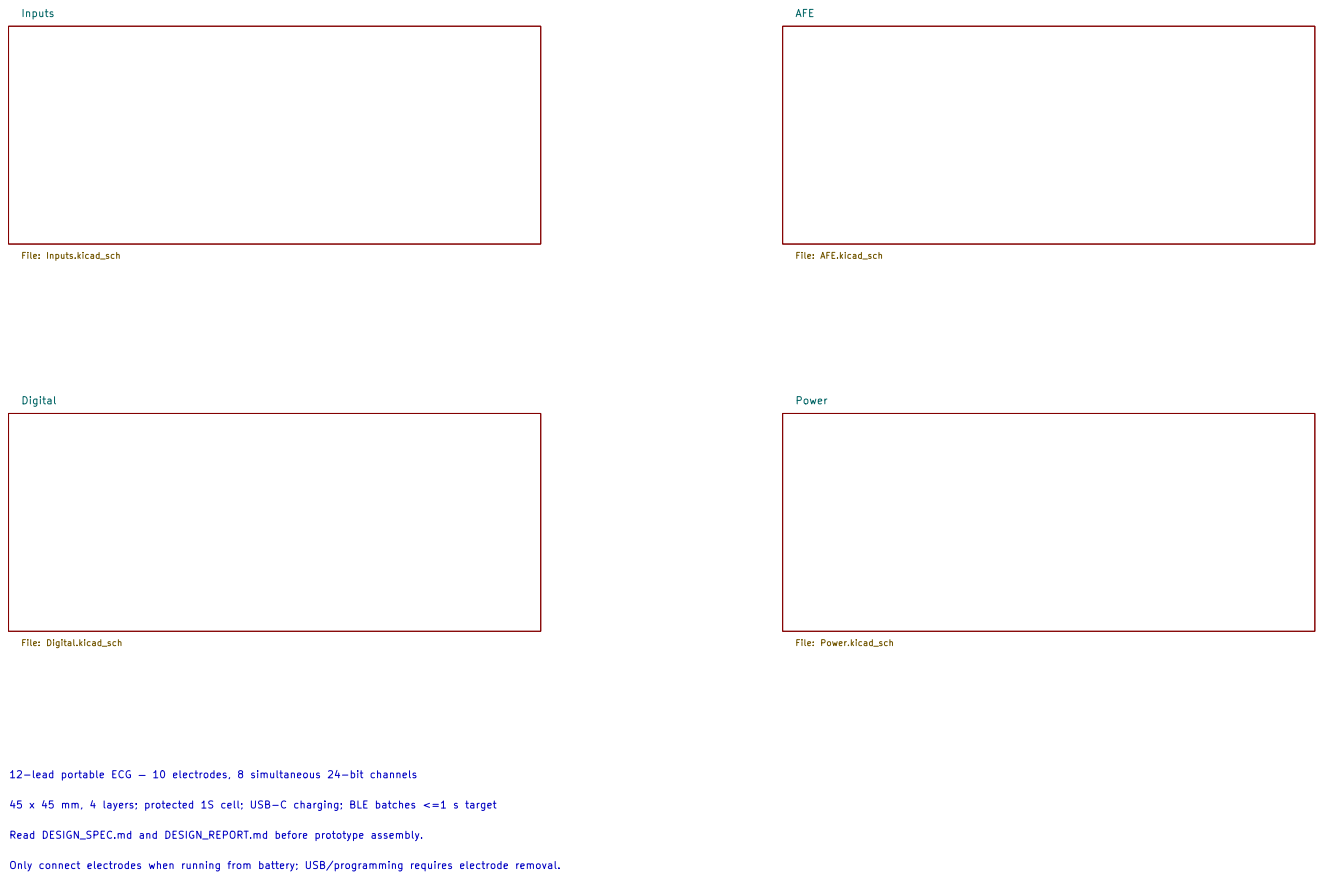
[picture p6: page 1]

File: AFE.kicad_sch Digital File: Digital.kicad_sch

Power File: Power.kicad_sch 12-lead portable ECG — 10 electrodes, 8 simultaneous 24-bit channels

45 x 45 mm, 4 layers; protected 1S cell; USB-C charging; BLE batches <=1 s target

Read DESIGN_SPEC.md and DESIGN_REPORT.md before prototype assembly.

Only connect electrodes when running from battery; USB/programming requires electrode removal.

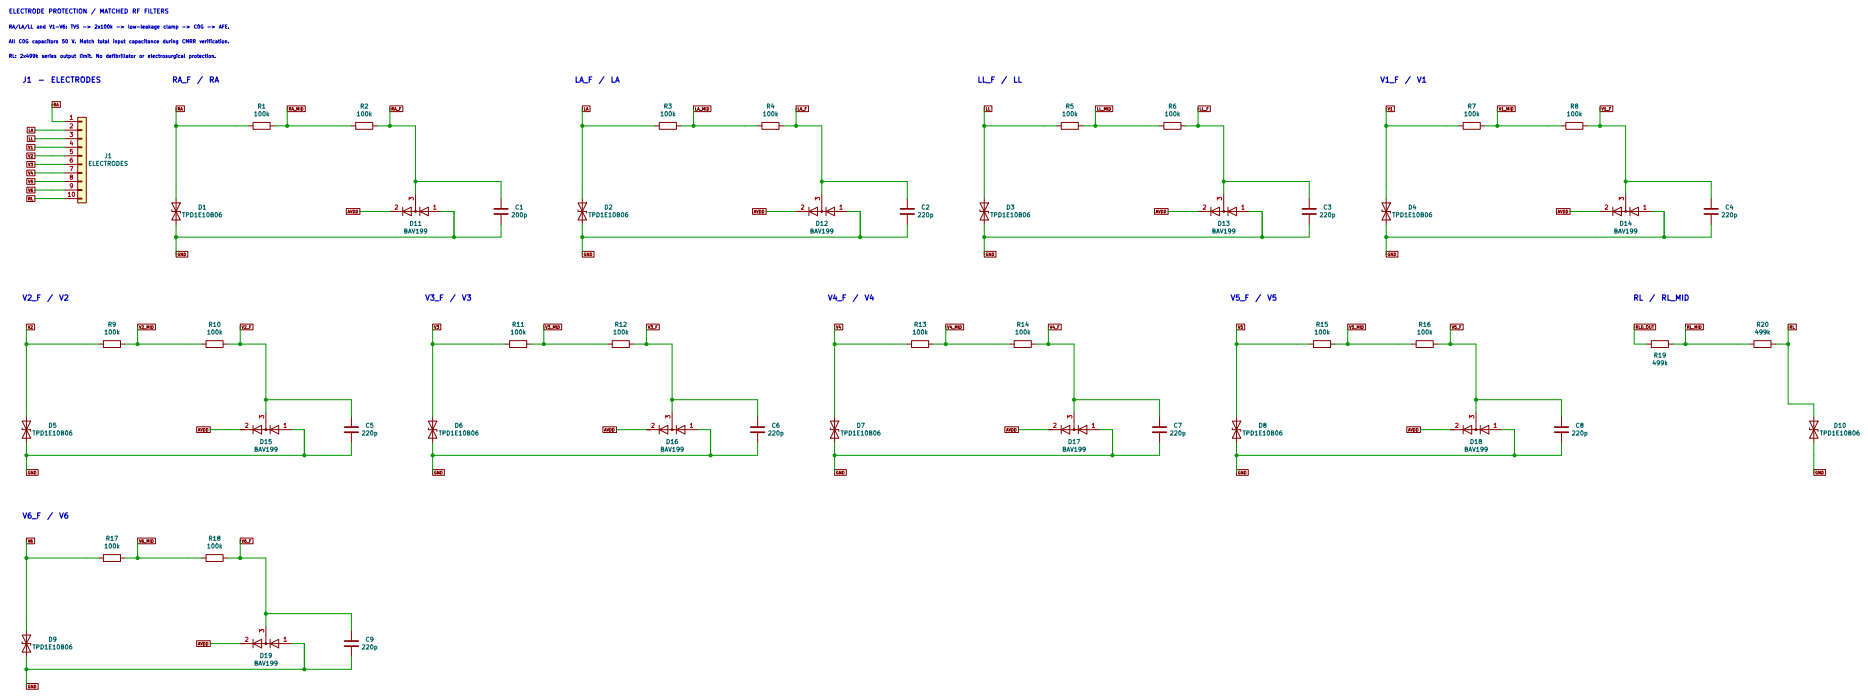
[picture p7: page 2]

ELECTRODE PROTECTION / MATCHED RF FILTERS

RA/LA/LL and V1-V6: TVS -> 2x100k -> low-leakage clamp -> C0G -> AFE. V2_F / V2

All C0G capacitors 50 V. Match total input capacitance during CMRR verification. RL: 2x499k series output limit. No defibrillator or electrosurgical protection. RA_F / RA

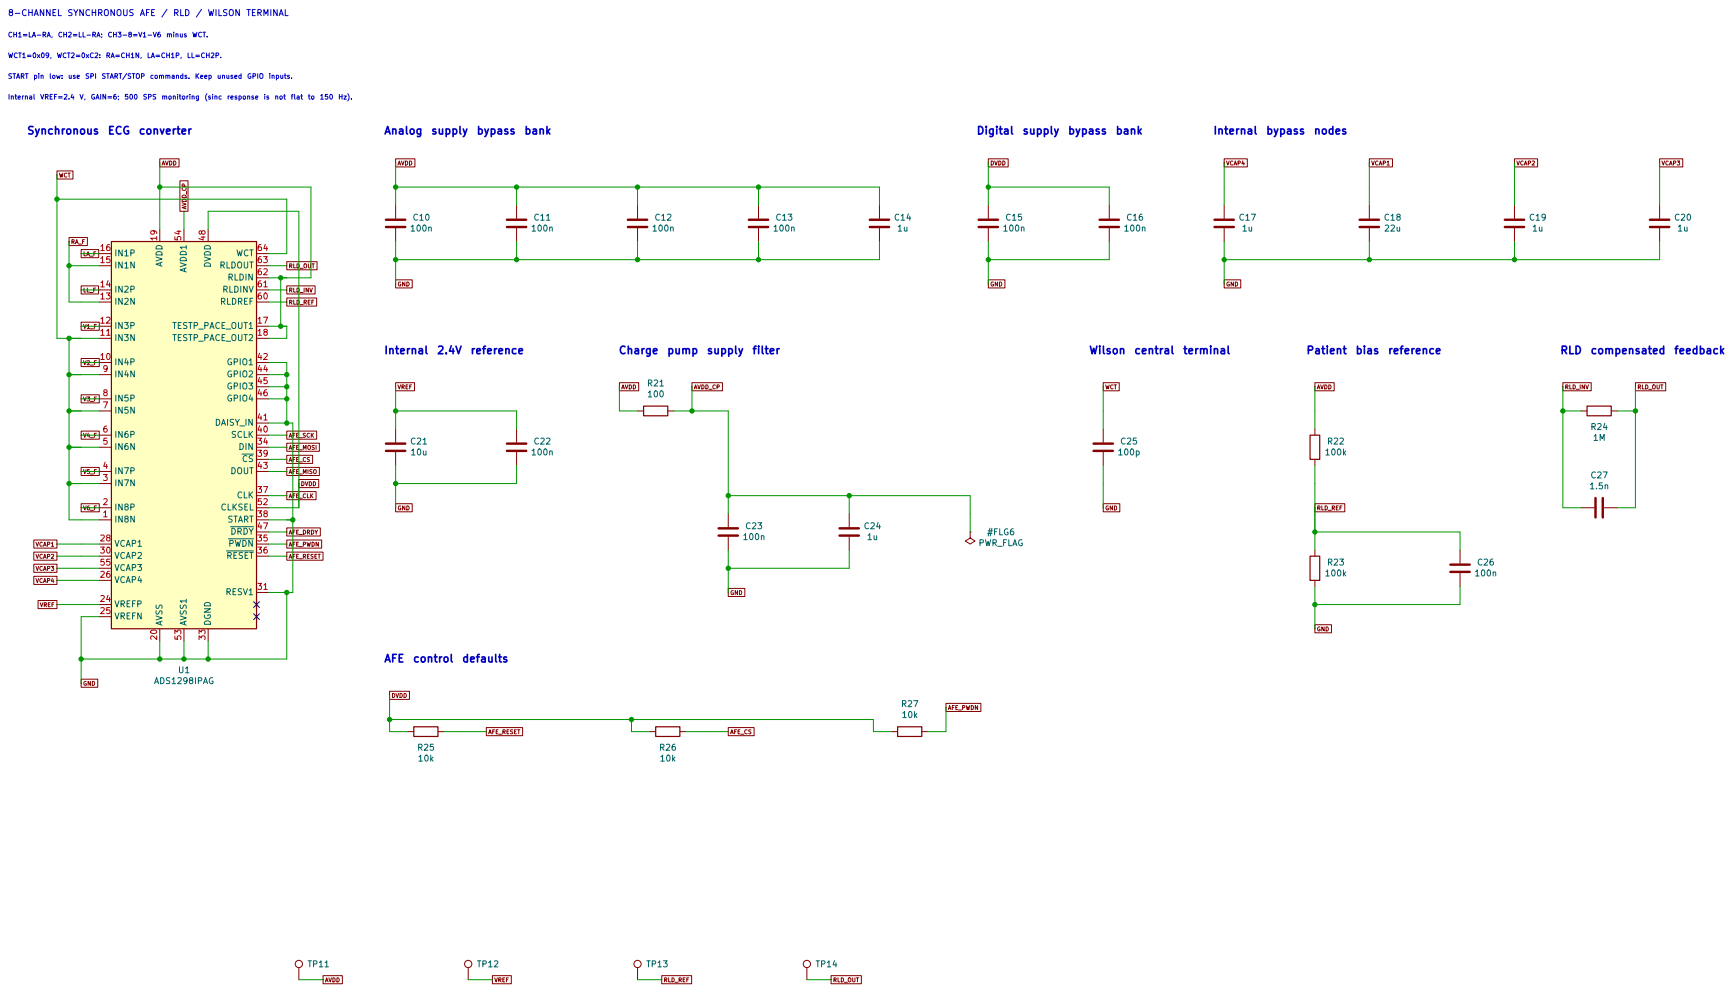
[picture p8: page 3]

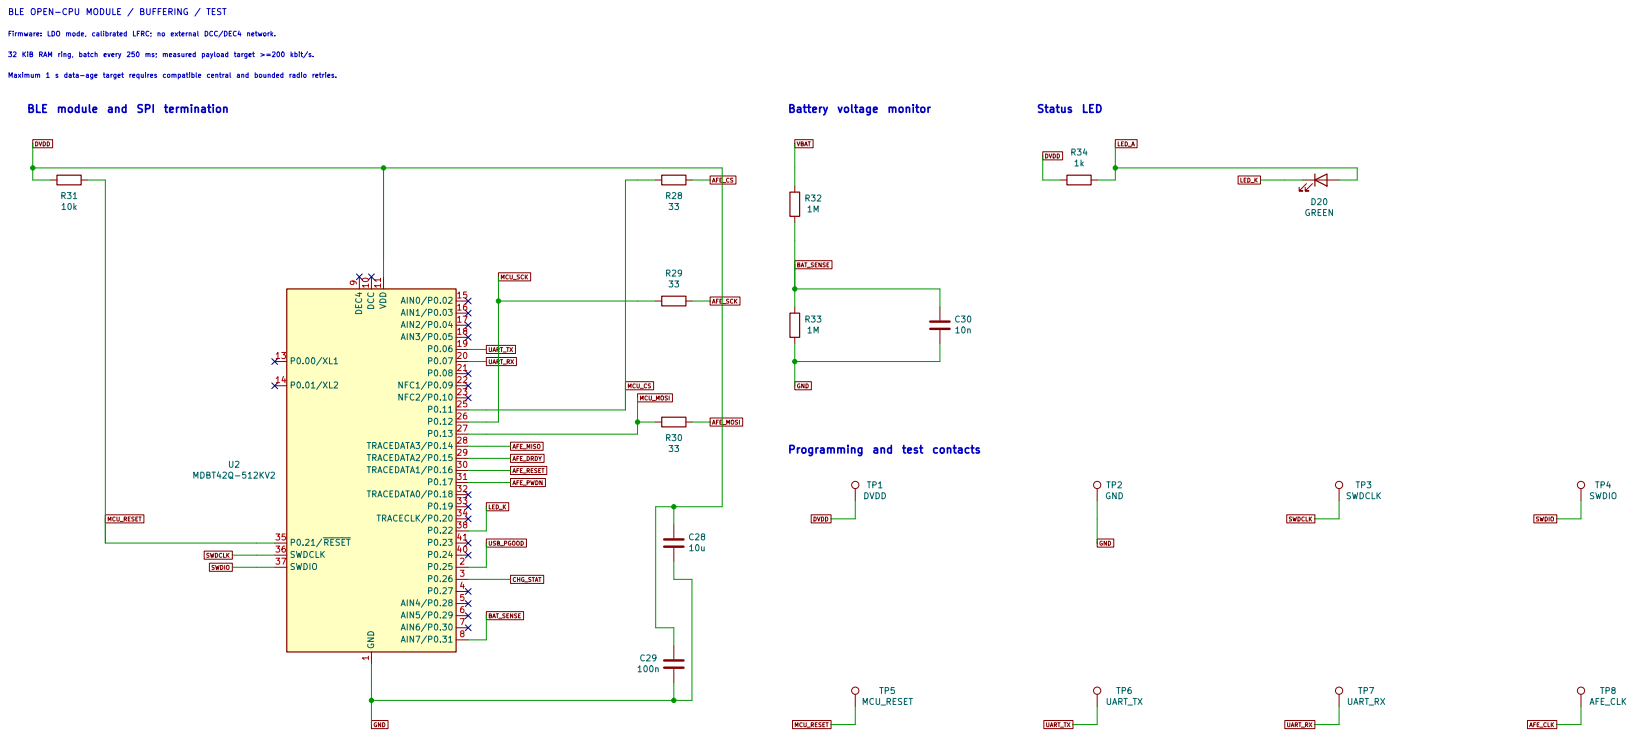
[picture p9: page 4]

Firmware: LDO mode, calibrated LFRC; no external DCC/DEC4 network. BLE OPEN-CPU MODULE / BUFFERING / TEST

AFE_PWDN BLE module and SPI termination

Programming and test contacts

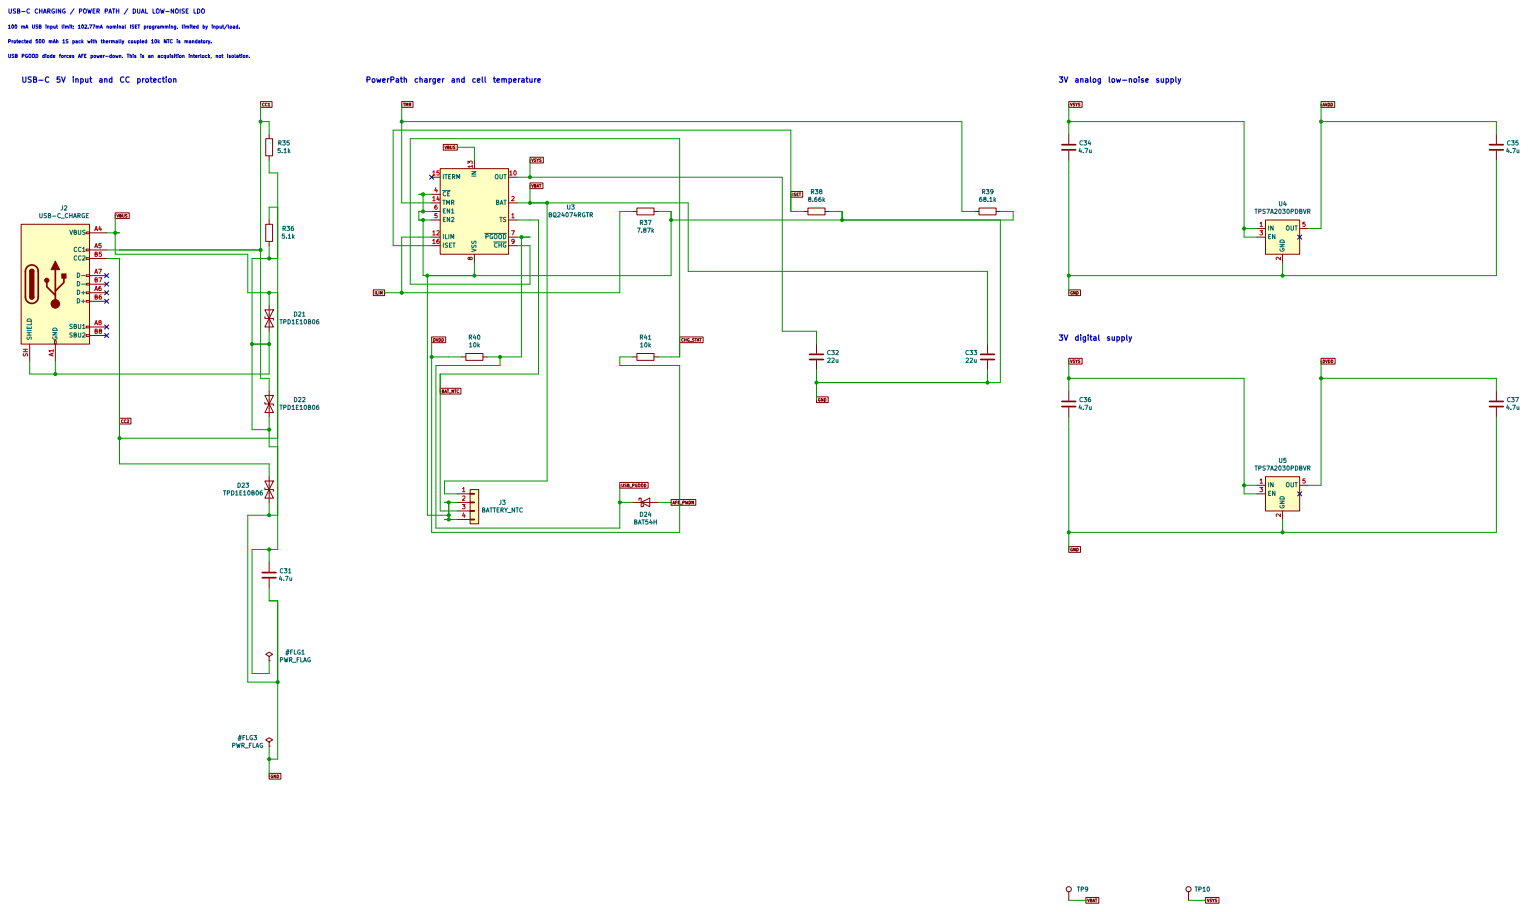
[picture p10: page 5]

USB-C CHARGING / POWER PATH / DUAL LOW-NOISE LDO

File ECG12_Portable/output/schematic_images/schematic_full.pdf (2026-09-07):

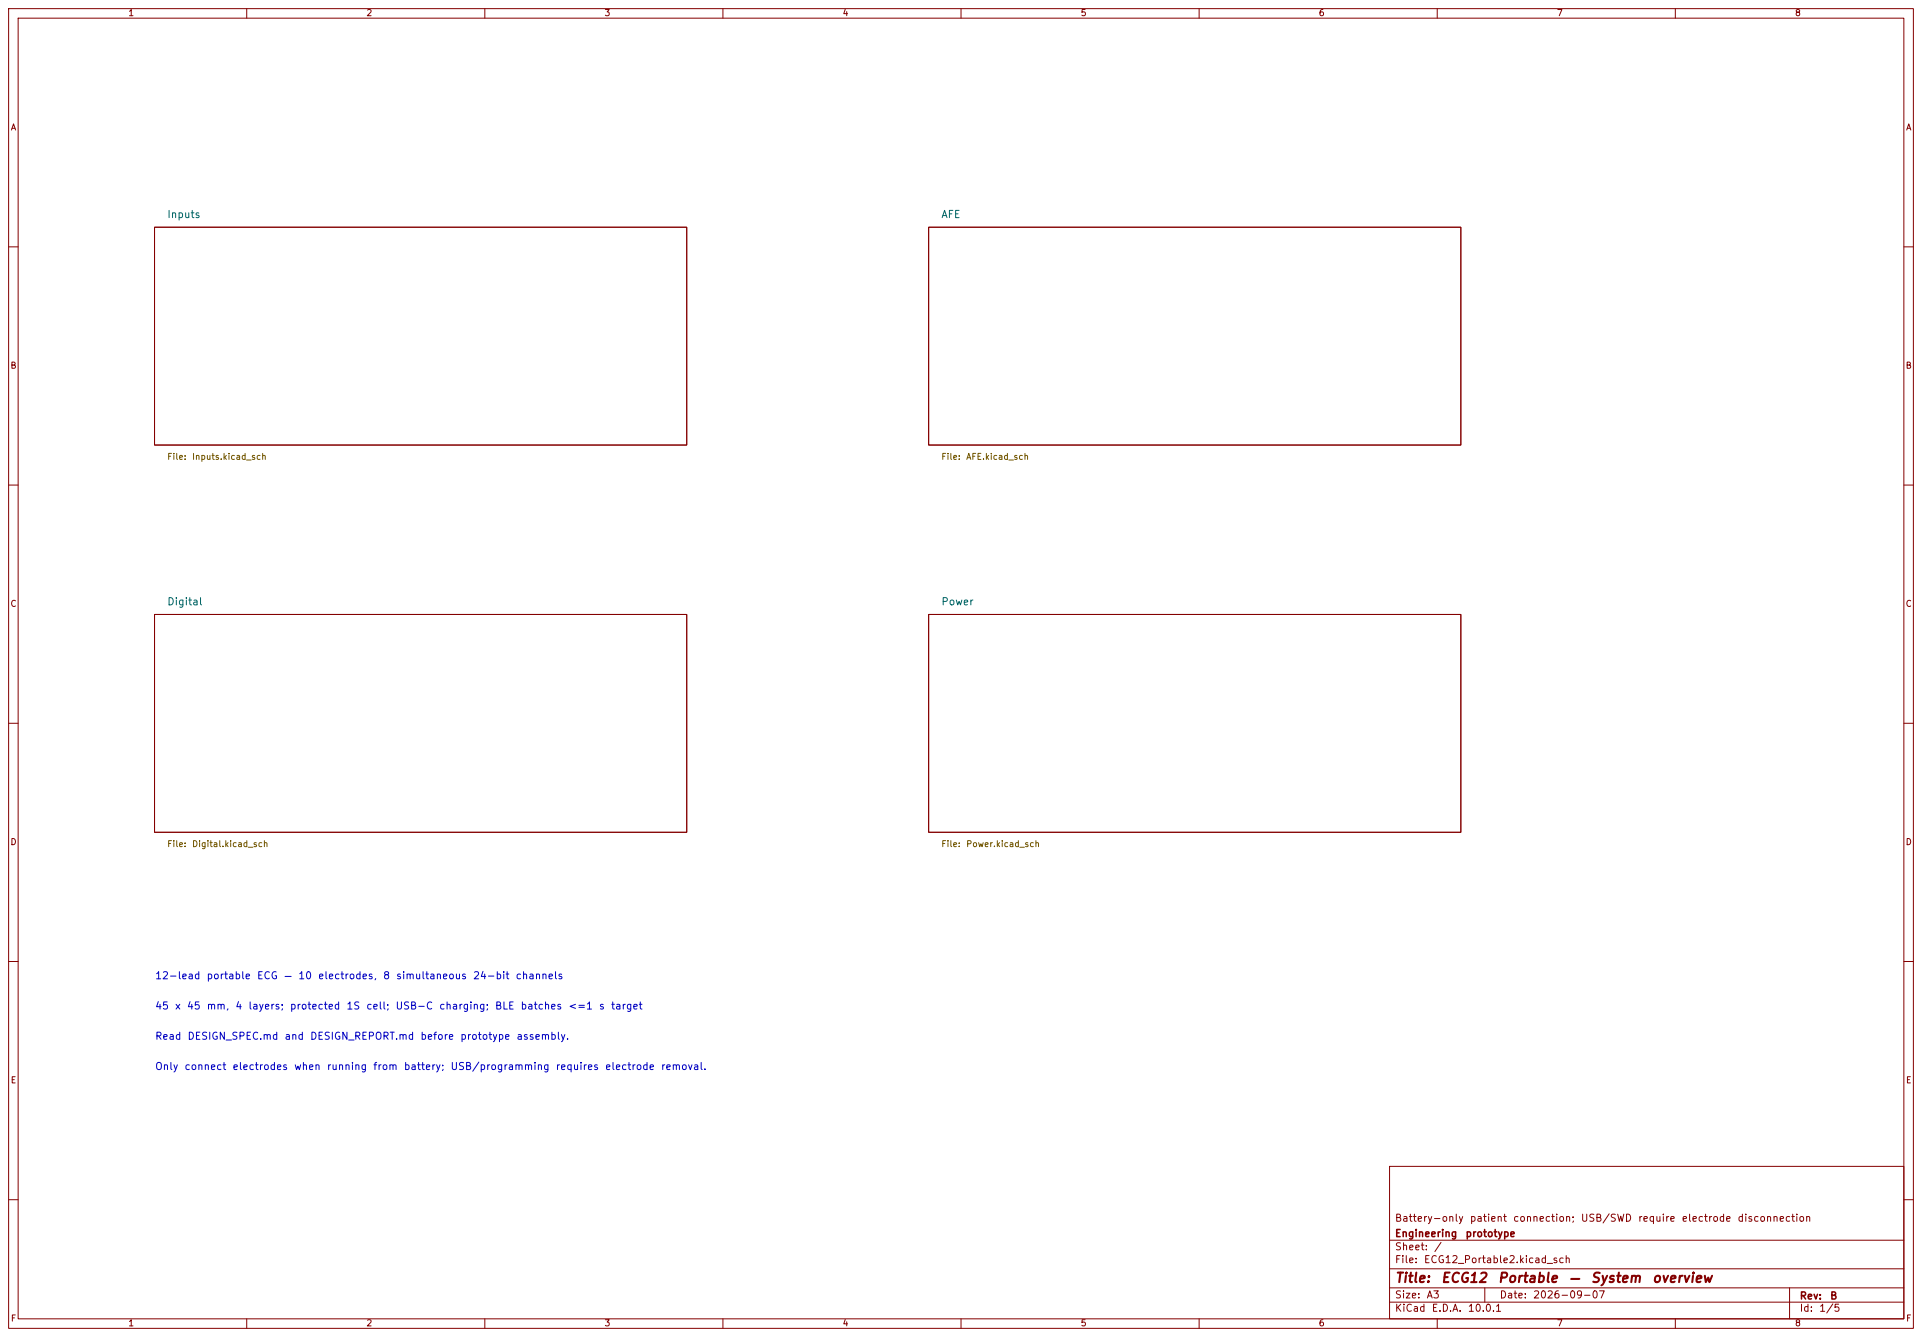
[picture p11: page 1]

File: AFE.kicad_sch Digital File: Digital.kicad_sch

Power File: Power.kicad_sch 12-lead portable ECG — 10 electrodes, 8 simultaneous 24-bit channels

45 x 45 mm, 4 layers; protected 1S cell; USB-C charging; BLE batches <=1 s target

Read DESIGN_SPEC.md and DESIGN_REPORT.md before prototype assembly.

Only connect electrodes when running from battery; USB/programming requires electrode removal.

Battery-only patient connection; USB/SWD require electrode disconnection
Engineering prototype
Sheet: /
File: ECG12_Portable2.kicad_sch
Title: ECG12 Portable — System overview

Size: A3 | Rev: B | F Date: 2026-09-07
KiCad E.D.A. 10.0.1 | Id: 1/5

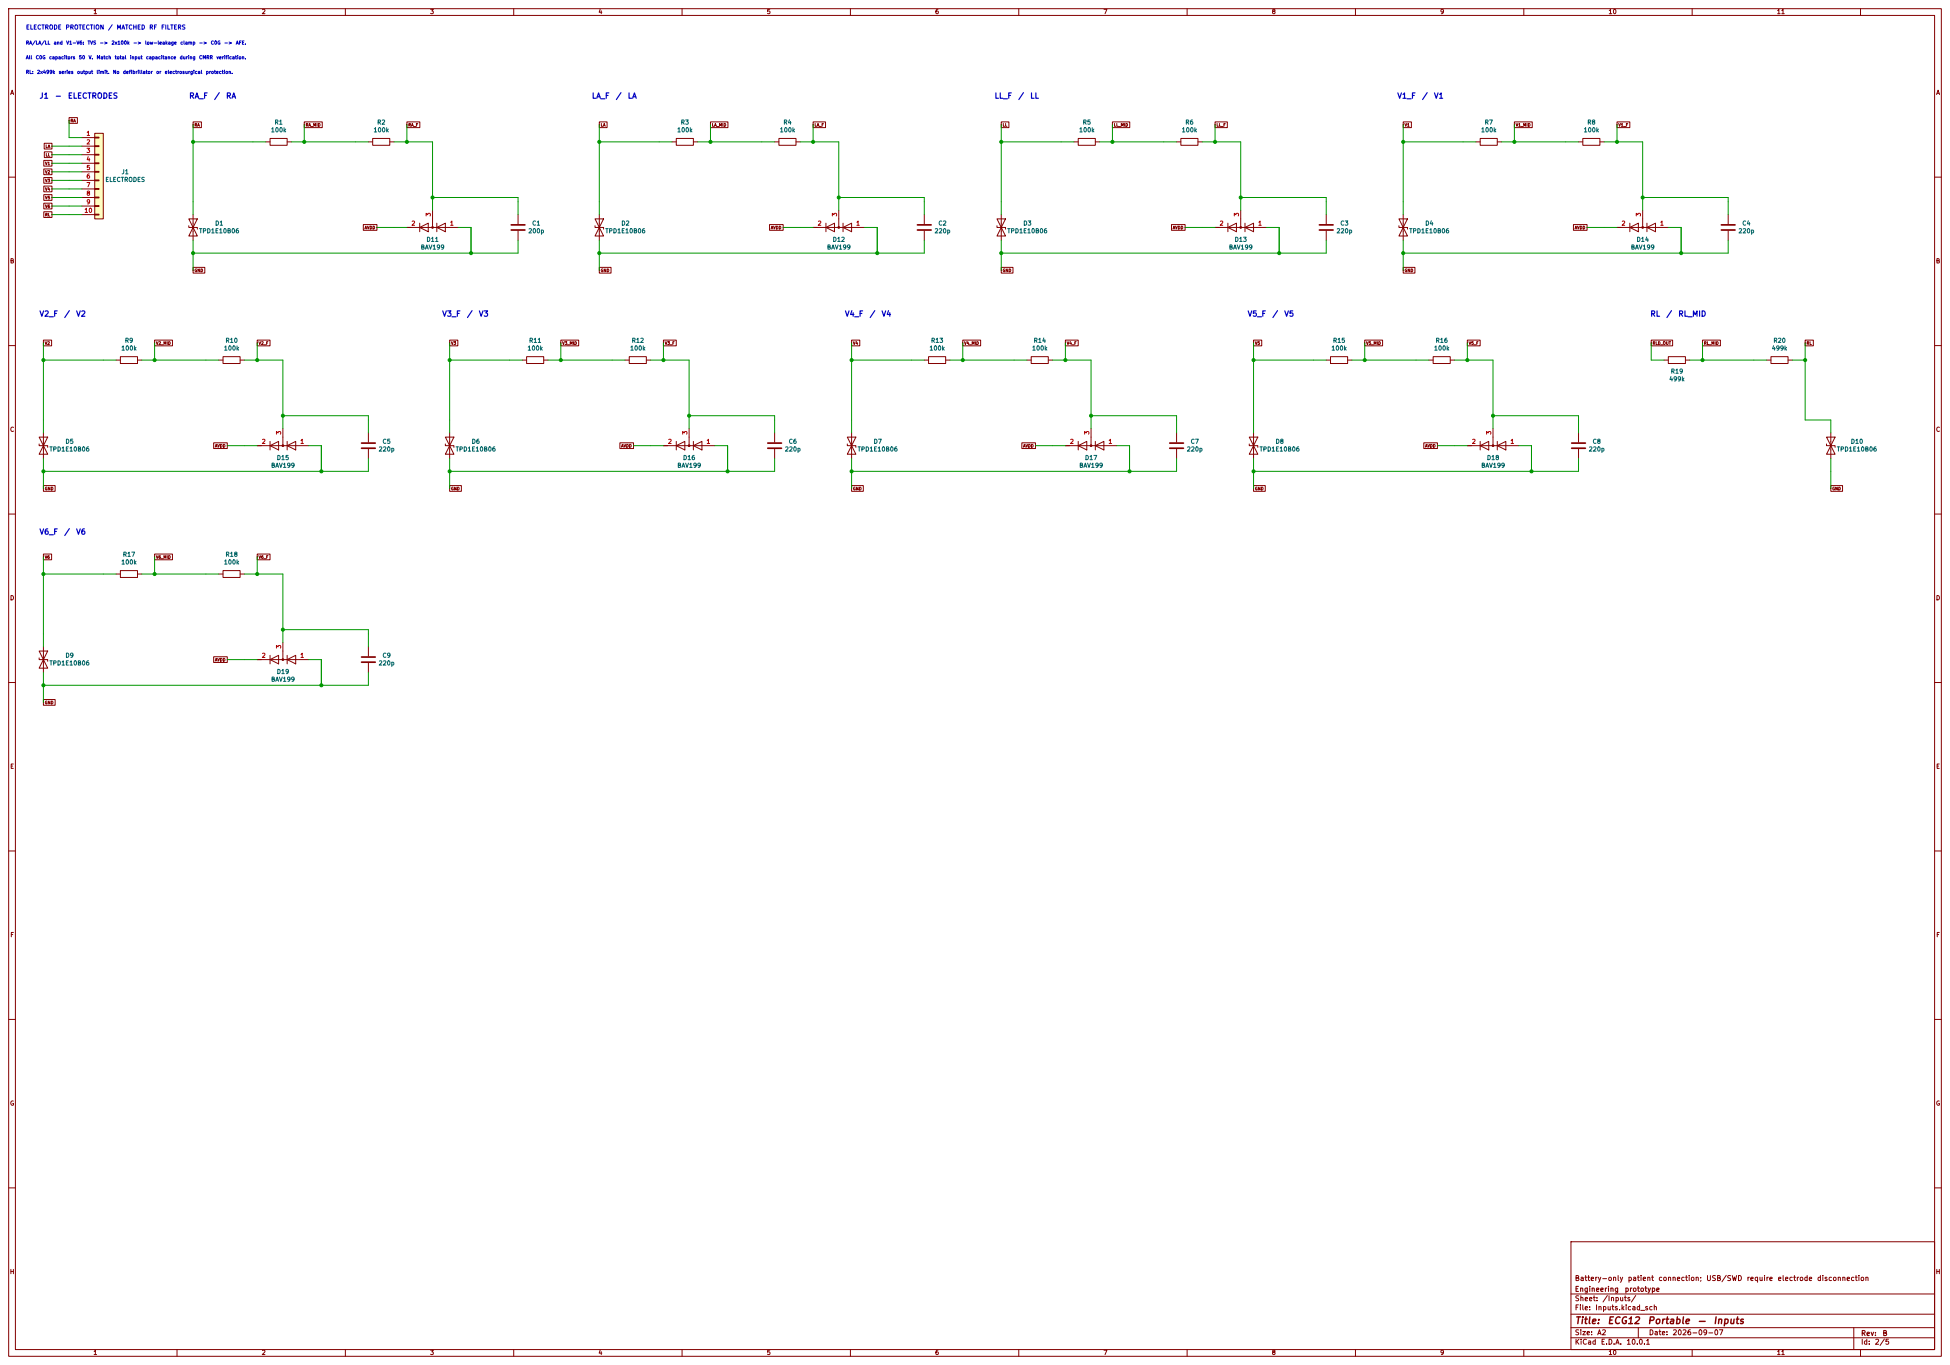
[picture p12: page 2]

ELECTRODE PROTECTION / MATCHED RF FILTERS

RA/LA/LL and V1-V6: TVS -> 2x100k -> low-leakage clamp -> C0G -> AFE. V2_F / V2

All C0G capacitors 50 V. Match total input capacitance during CMRR verification. RL: 2x499k series output limit. No defibrillator or electrosurgical protection. RA_F / RA

Battery-only patient connection; USB/SWD require electrode disconnection
Engineering prototype
Sheet: /Inputs/
File: Inputs.kicad_sch
Title: ECG12 Portable — Inputs

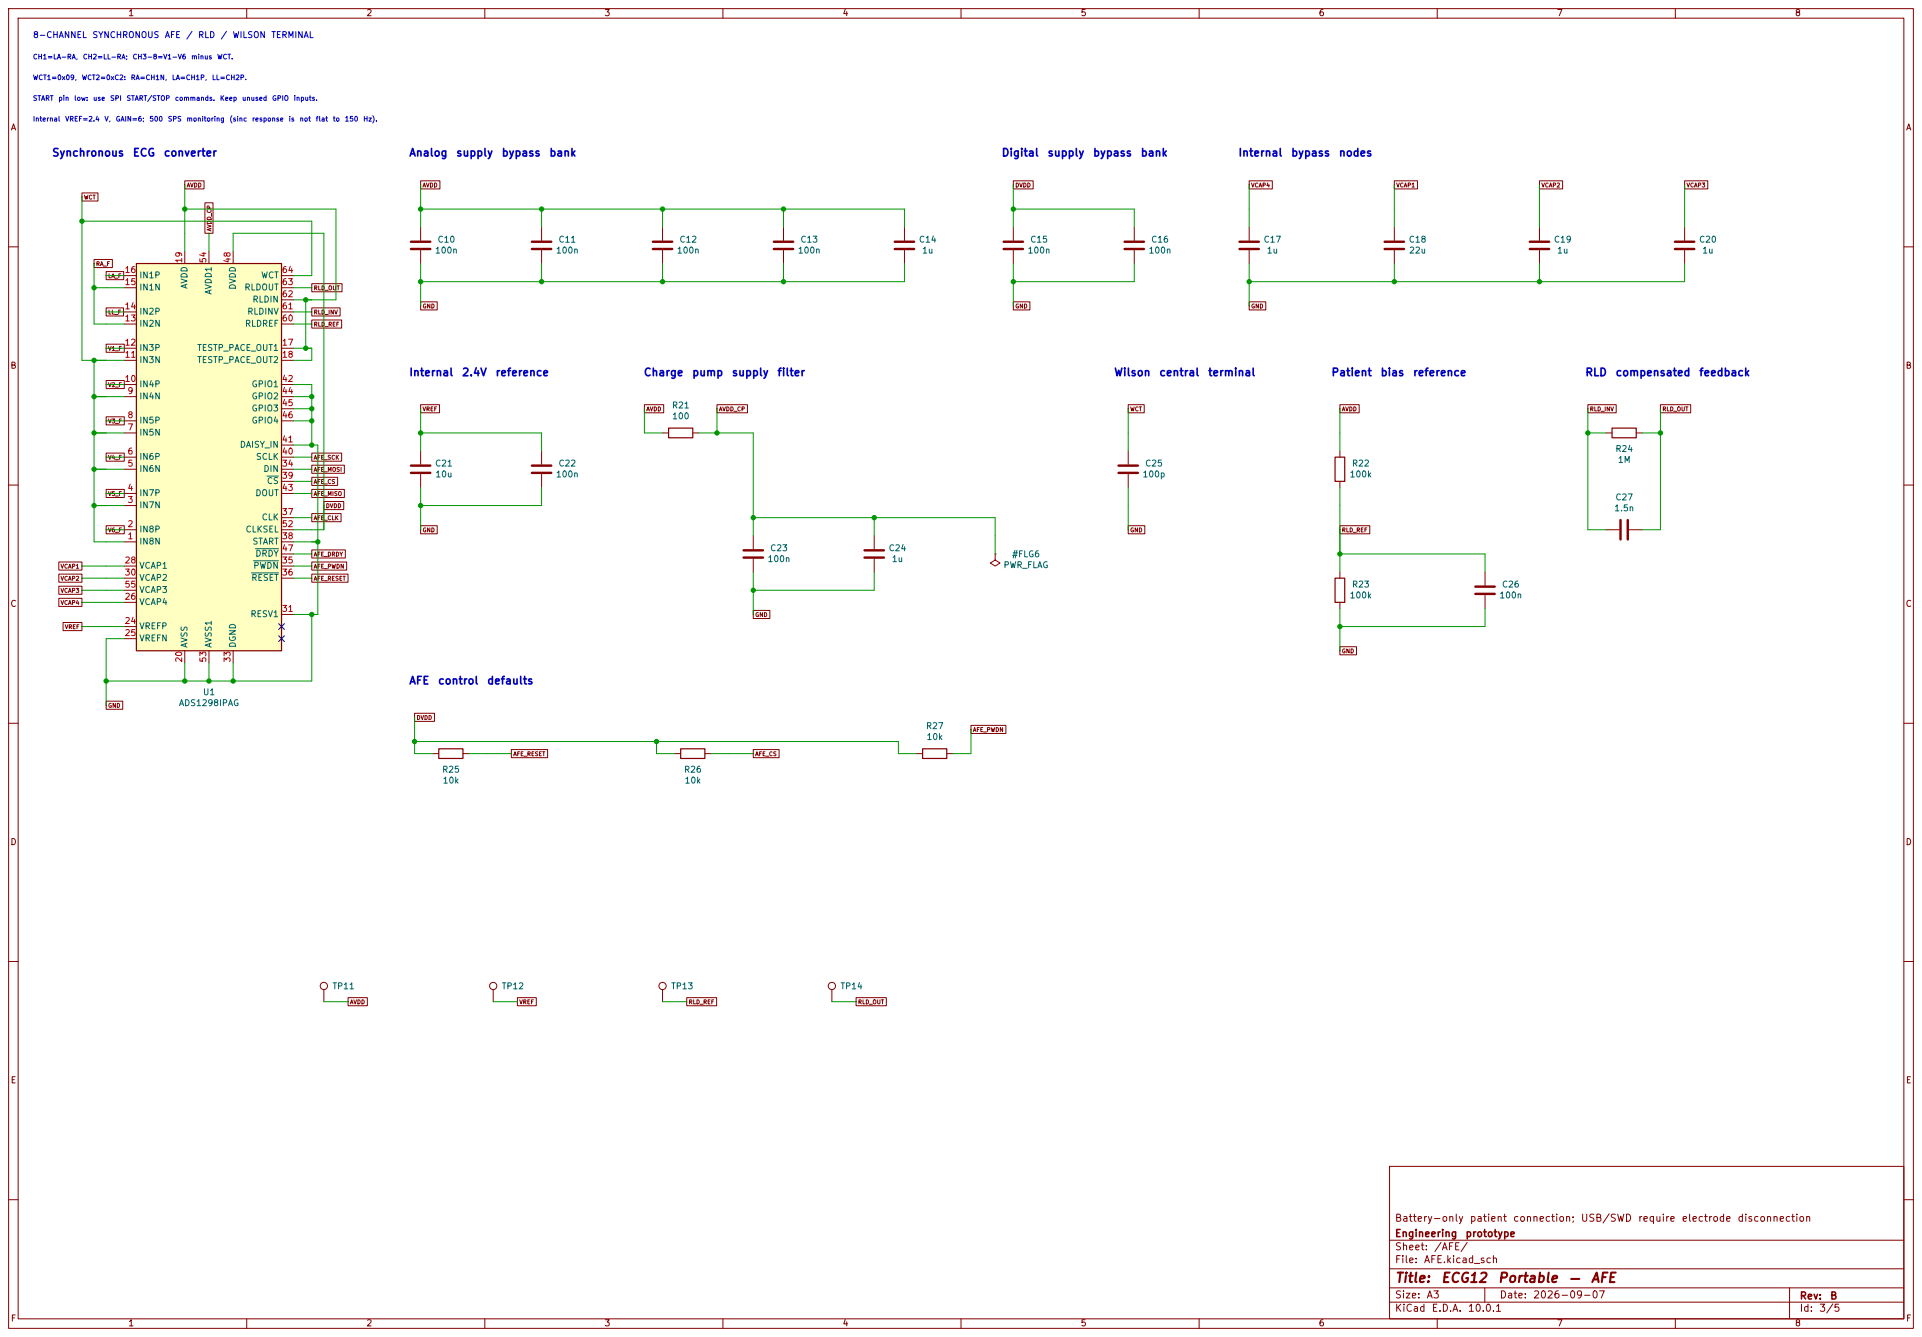
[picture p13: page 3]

Battery-only patient connection; USB/SWD require electrode disconnection
Engineering prototype
Sheet: /AFE/
File: AFE.kicad_sch
Title: ECG12 Portable — AFE

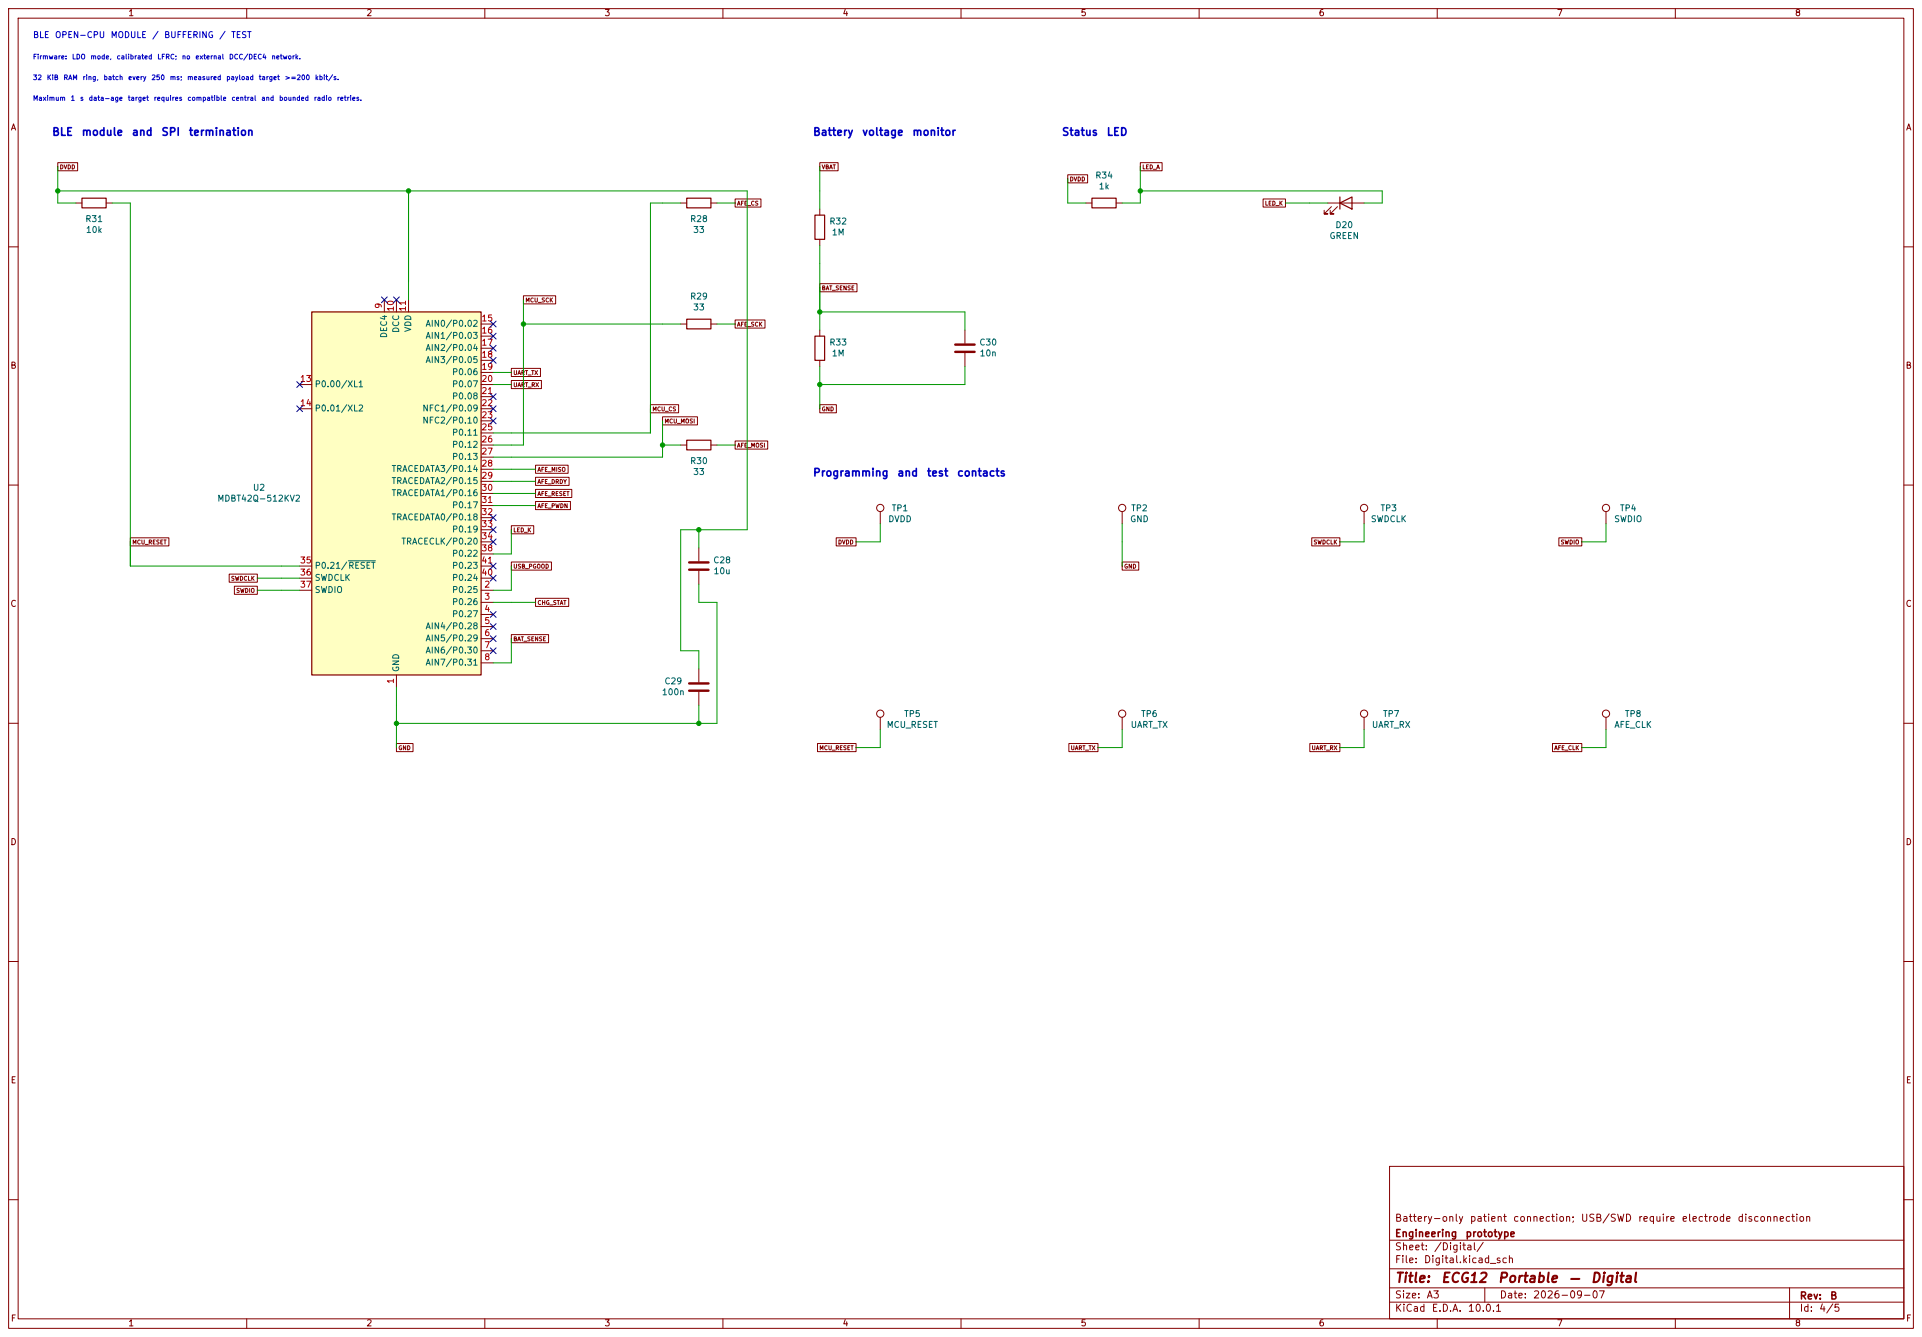
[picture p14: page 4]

Firmware: LDO mode, calibrated LFRC; no external DCC/DEC4 network. BLE OPEN-CPU MODULE / BUFFERING / TEST

AFE_PWDN BLE module and SPI termination

Programming and test contacts

Battery-only patient connection; USB/SWD require electrode disconnection
Engineering prototype
Sheet: /Digital/
File: Digital.kicad_sch
Title: ECG12 Portable — Digital

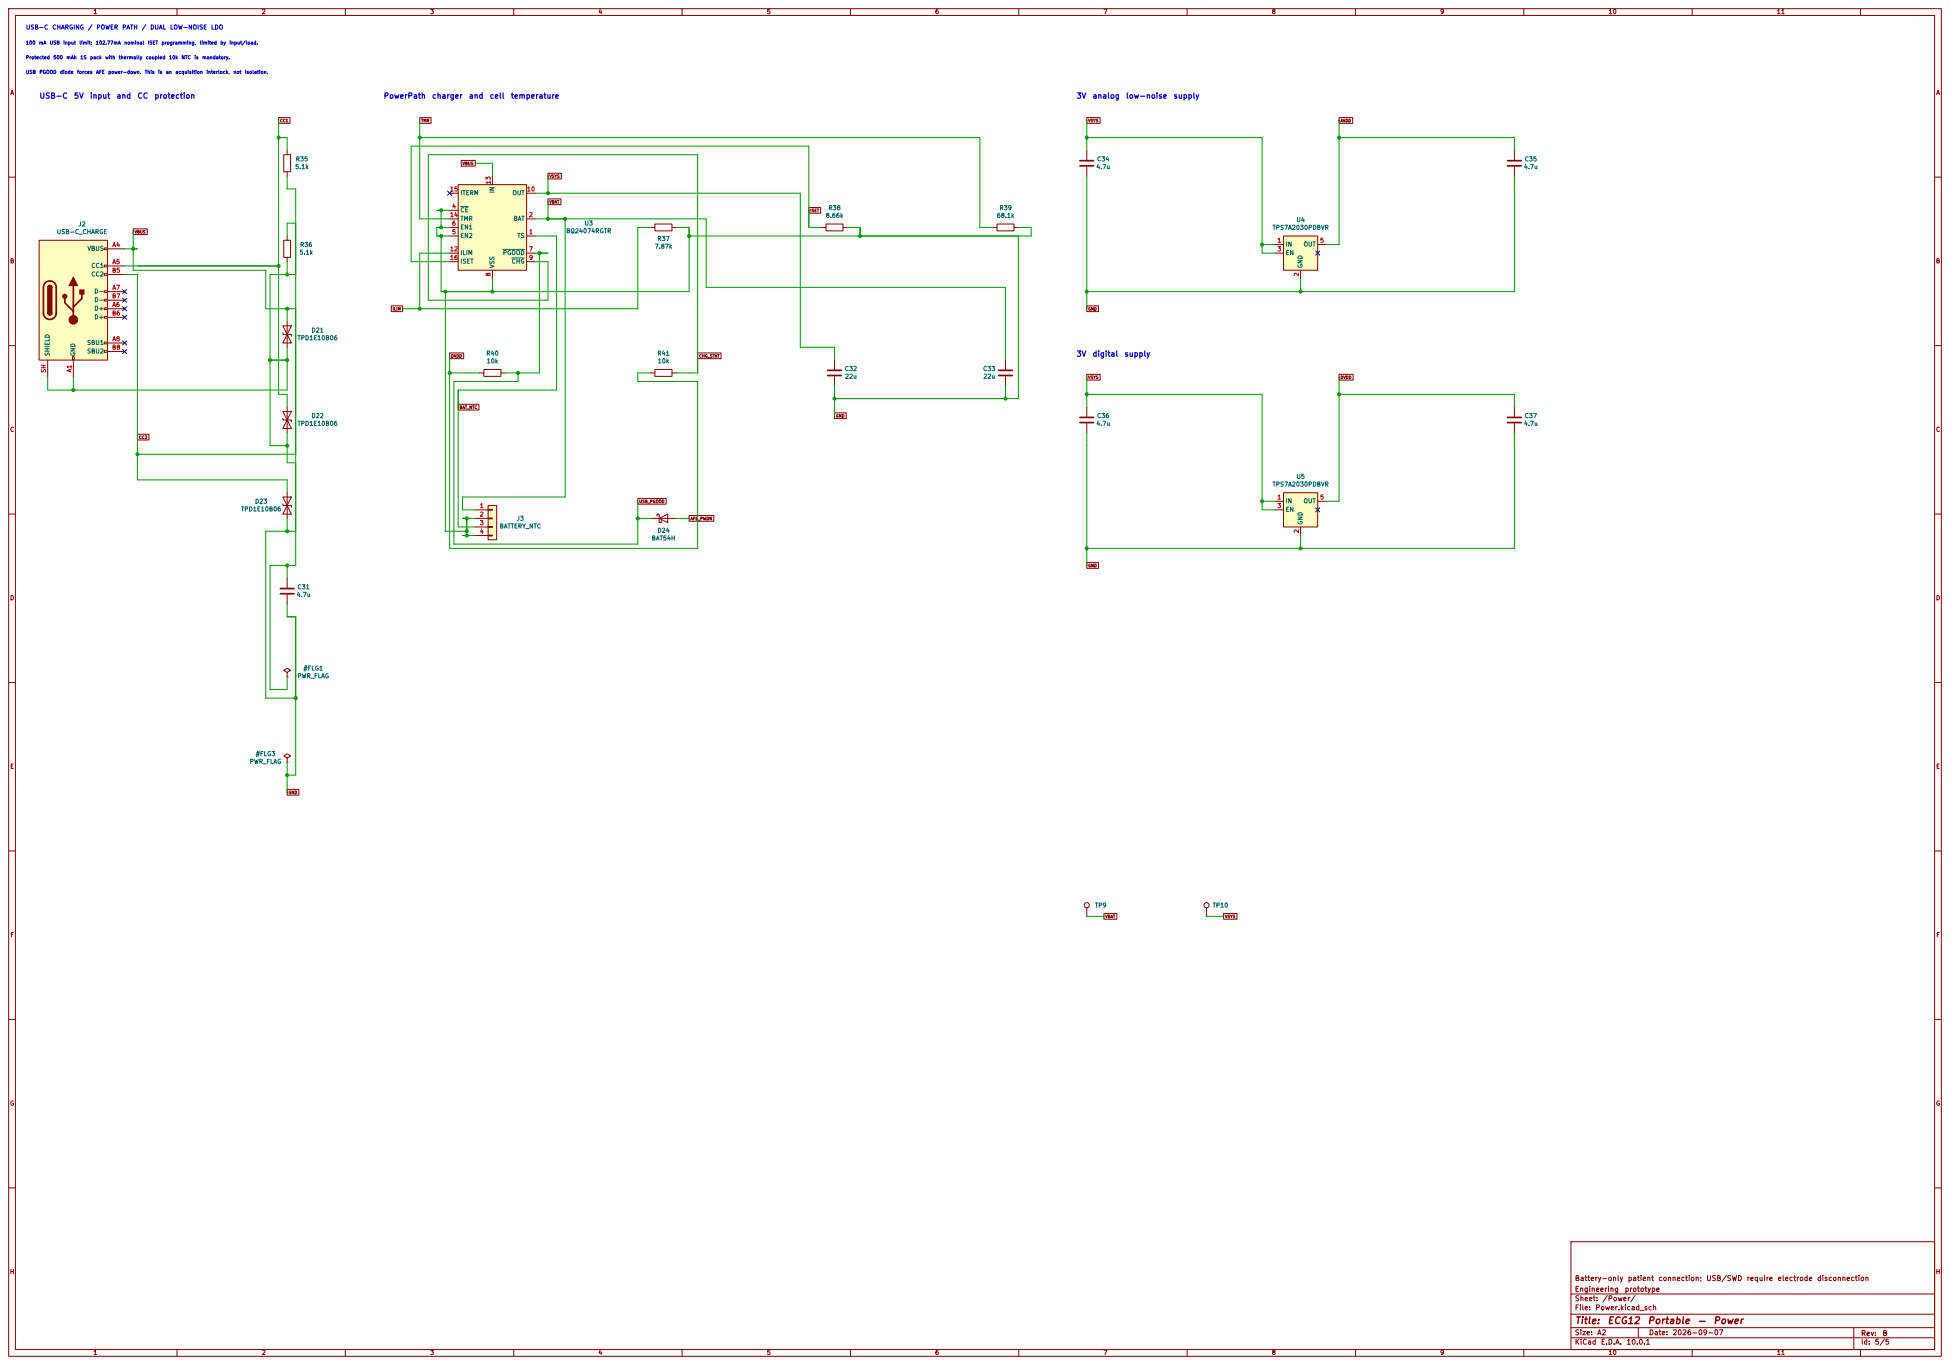
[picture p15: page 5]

USB-C CHARGING / POWER PATH / DUAL LOW-NOISE LDO

Battery-only patient connection; USB/SWD require electrode disconnection
Engineering prototype
Sheet: /Power/
File: Power.kicad_sch
Title: ECG12 Portable — Power

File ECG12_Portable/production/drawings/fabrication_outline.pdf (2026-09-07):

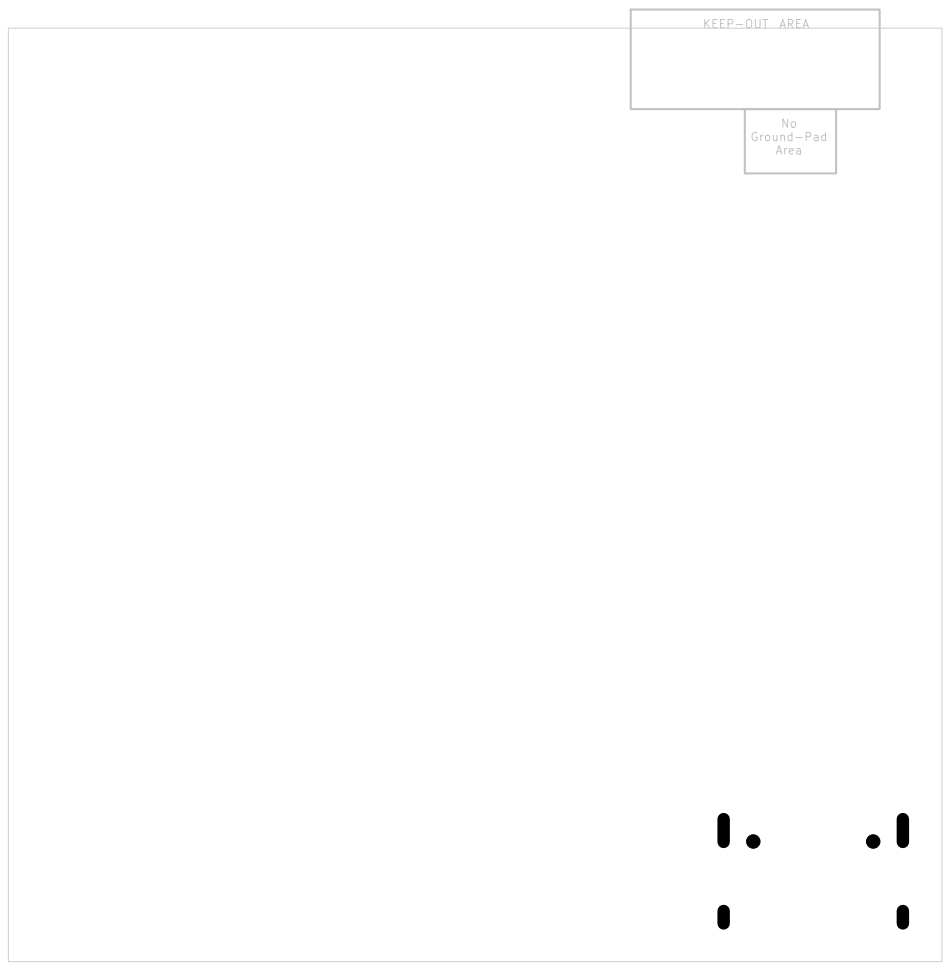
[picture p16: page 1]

Area KEEP-OUT AREA

Size: A4 | Rev: B
KiCad E.D.A. 10.0.1 | Id: 1/1

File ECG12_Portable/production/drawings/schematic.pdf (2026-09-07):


File: AFE.kicad_sch Digital File: Digital.kicad_sch

Power File: Power.kicad_sch 12-lead portable ECG — 10 electrodes, 8 simultaneous 24-bit channels

45 x 45 mm, 4 layers; protected 1S cell; USB-C charging; BLE batches <=1 s target

Read DESIGN_SPEC.md and DESIGN_REPORT.md before prototype assembly.

Only connect electrodes when running from battery; USB/programming requires electrode removal.

Battery-only patient connection; USB/SWD require electrode disconnection
Engineering prototype
Sheet: /
File: ECG12_Portable2.kicad_sch
Title: ECG12 Portable — System overview

Size: A3 | Rev: B | F Date: 2026-09-07
KiCad E.D.A. 10.0.1 | Id: 1/5


ELECTRODE PROTECTION / MATCHED RF FILTERS

RA/LA/LL and V1-V6: TVS -> 2x100k -> low-leakage clamp -> C0G -> AFE. V2_F / V2

All C0G capacitors 50 V. Match total input capacitance during CMRR verification. RL: 2x499k series output limit. No defibrillator or electrosurgical protection. RA_F / RA

Battery-only patient connection; USB/SWD require electrode disconnection
Engineering prototype
Sheet: /Inputs/
File: Inputs.kicad_sch
Title: ECG12 Portable — Inputs


Battery-only patient connection; USB/SWD require electrode disconnection
Engineering prototype
Sheet: /AFE/
File: AFE.kicad_sch
Title: ECG12 Portable — AFE


Firmware: LDO mode, calibrated LFRC; no external DCC/DEC4 network. BLE OPEN-CPU MODULE / BUFFERING / TEST

AFE_PWDN BLE module and SPI termination

Programming and test contacts

Battery-only patient connection; USB/SWD require electrode disconnection
Engineering prototype
Sheet: /Digital/
File: Digital.kicad_sch
Title: ECG12 Portable — Digital


USB-C CHARGING / POWER PATH / DUAL LOW-NOISE LDO

Battery-only patient connection; USB/SWD require electrode disconnection
Engineering prototype
Sheet: /Power/
File: Power.kicad_sch
Title: ECG12 Portable — Power

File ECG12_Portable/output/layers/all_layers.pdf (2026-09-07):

# 01 F.Cu


Top view, unmirrored. Shared Edge.Cuts outline included.

ECG12 Portable2 | 45 x 45 mm | KiCad native layer plot

# 02 In1.Cu


# 03 In2.Cu


# 04 B.Cu


# 05 F.Mask


# 06 B.Mask


# 07 F.Paste


# 08 B.Paste


# 09 F.Silkscreen

## D9D8D3D2D1


Top view, unmirrored. Shared Edge.Cuts outline included. FID1

# 10 B.Silkscreen


Top view, unmirrored. Shared Edge.Cuts outline included. FID4

# 11 F.Fab

## FID1 FIDUCIAL


# 12 B.Fab

FID4 FIDUCIAL FID4 TP14 TP14; FID5 FIDUCIAL FID5; FID6 FIDUCIAL FID6

# 13 F.Courtyard


# 14 B.Courtyard


# 15 Edge.Cuts

# 16 F.Adhesive

Empty layer; only the shared board outline is shown.

# 17 B.Adhesive

Empty layer; only the shared board outline is shown.

# 18 User.Drawings

Top view, unmirrored. Shared Edge.Cuts outline included. | No Ground-Pad

Area KEEP-OUT AREA

# 19 User.Comments

Empty layer; only the shared board outline is shown.

# 20 User.Eco1

Empty layer; only the shared board outline is shown.

# 21 User.Eco2

Empty layer; only the shared board outline is shown.

# 22 Margin

Empty layer; only the shared board outline is shown.

# 23 User.1

Empty layer; only the shared board outline is shown.

# 24 User.2

Empty layer; only the shared board outline is shown.

# 25 User.3

Empty layer; only the shared board outline is shown.

# 26 User.4

Empty layer; only the shared board outline is shown.





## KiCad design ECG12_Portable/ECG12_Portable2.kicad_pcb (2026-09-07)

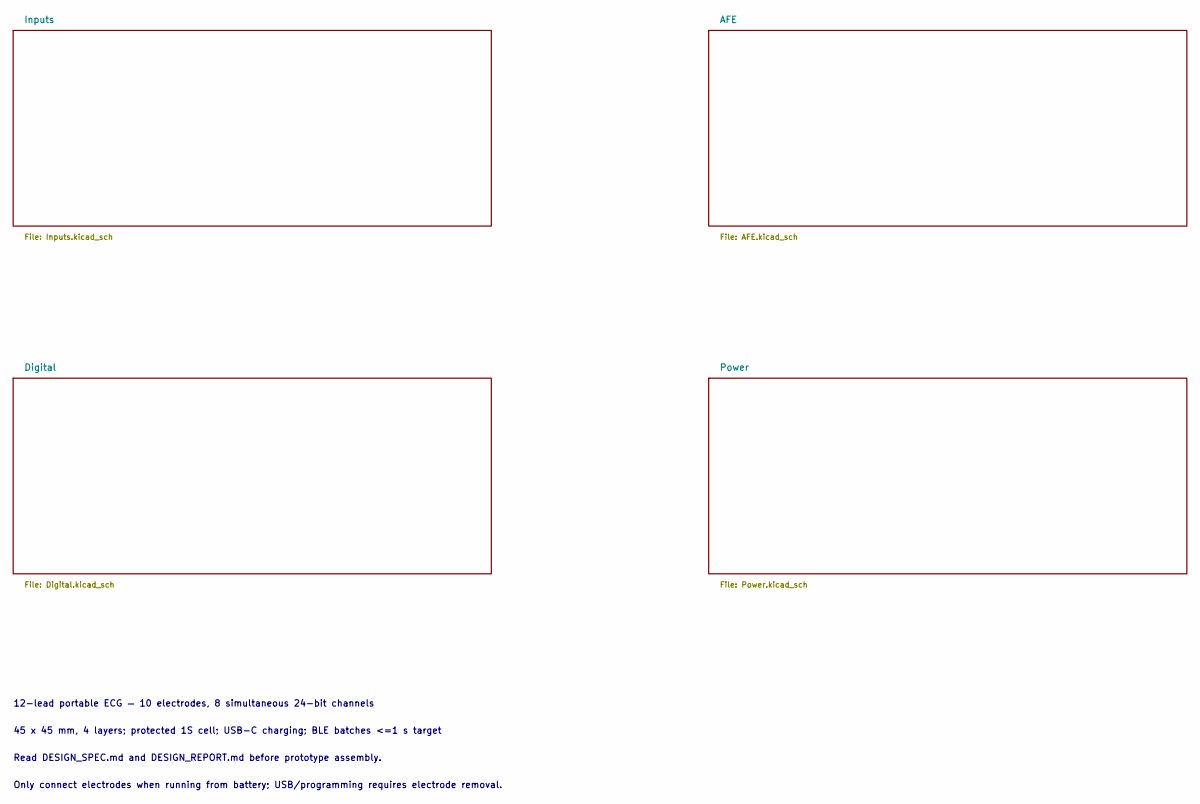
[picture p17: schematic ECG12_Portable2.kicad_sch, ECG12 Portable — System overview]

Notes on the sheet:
12-lead portable ECG — 10 electrodes, 8 simultaneous 24-bit channels
45 x 45 mm, 4 layers; protected 1S cell; USB-C charging; BLE batches <=1 s target
Read DESIGN_SPEC.md and DESIGN_REPORT.md before prototype assembly.
Only connect electrodes when running from battery; USB/programming requires electrode removal.

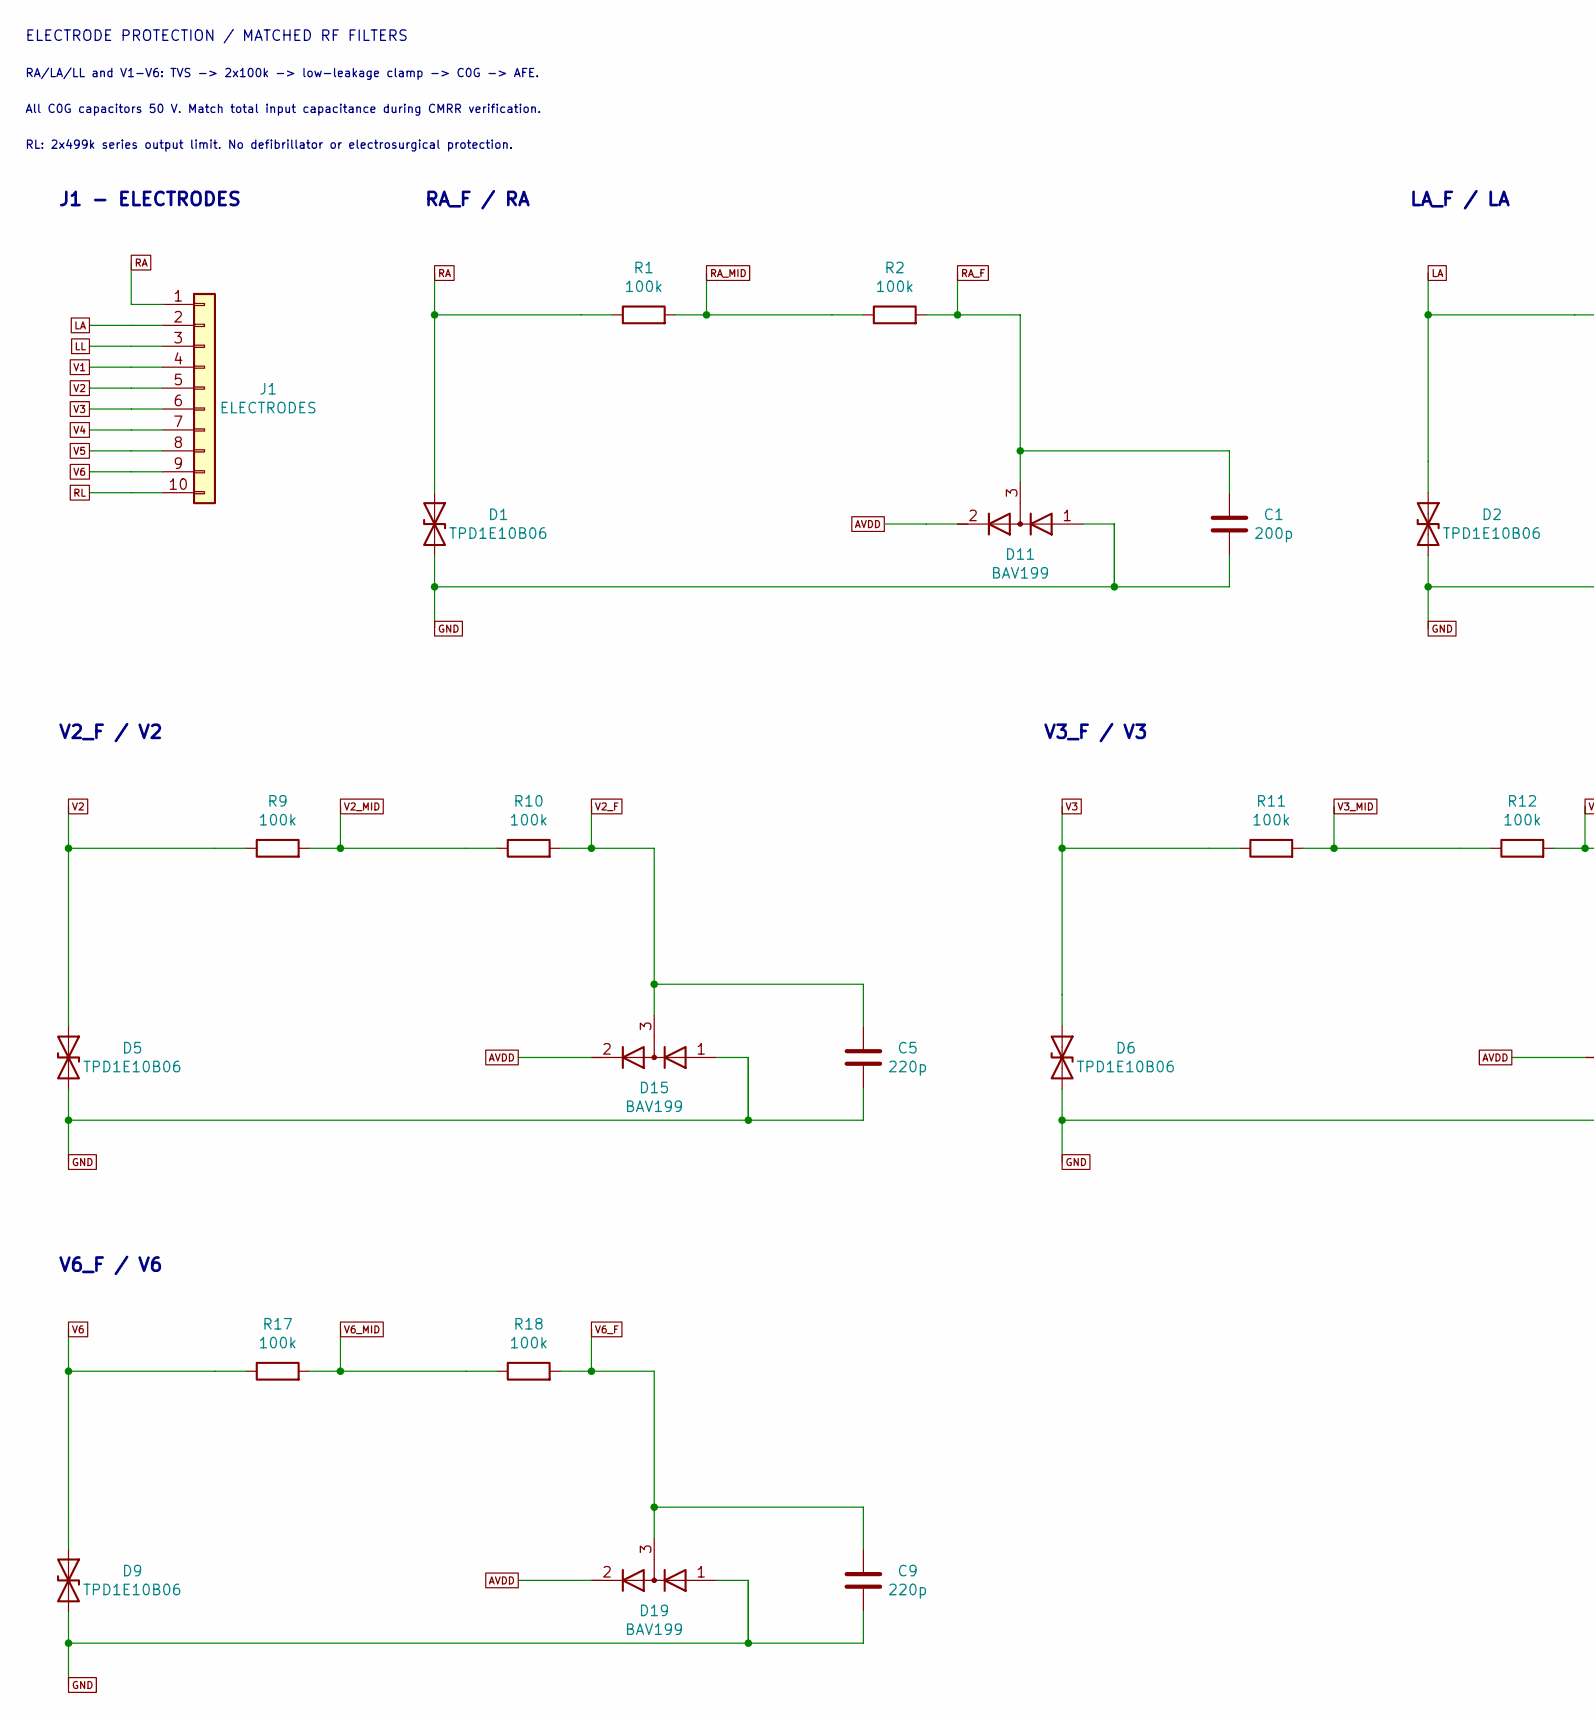
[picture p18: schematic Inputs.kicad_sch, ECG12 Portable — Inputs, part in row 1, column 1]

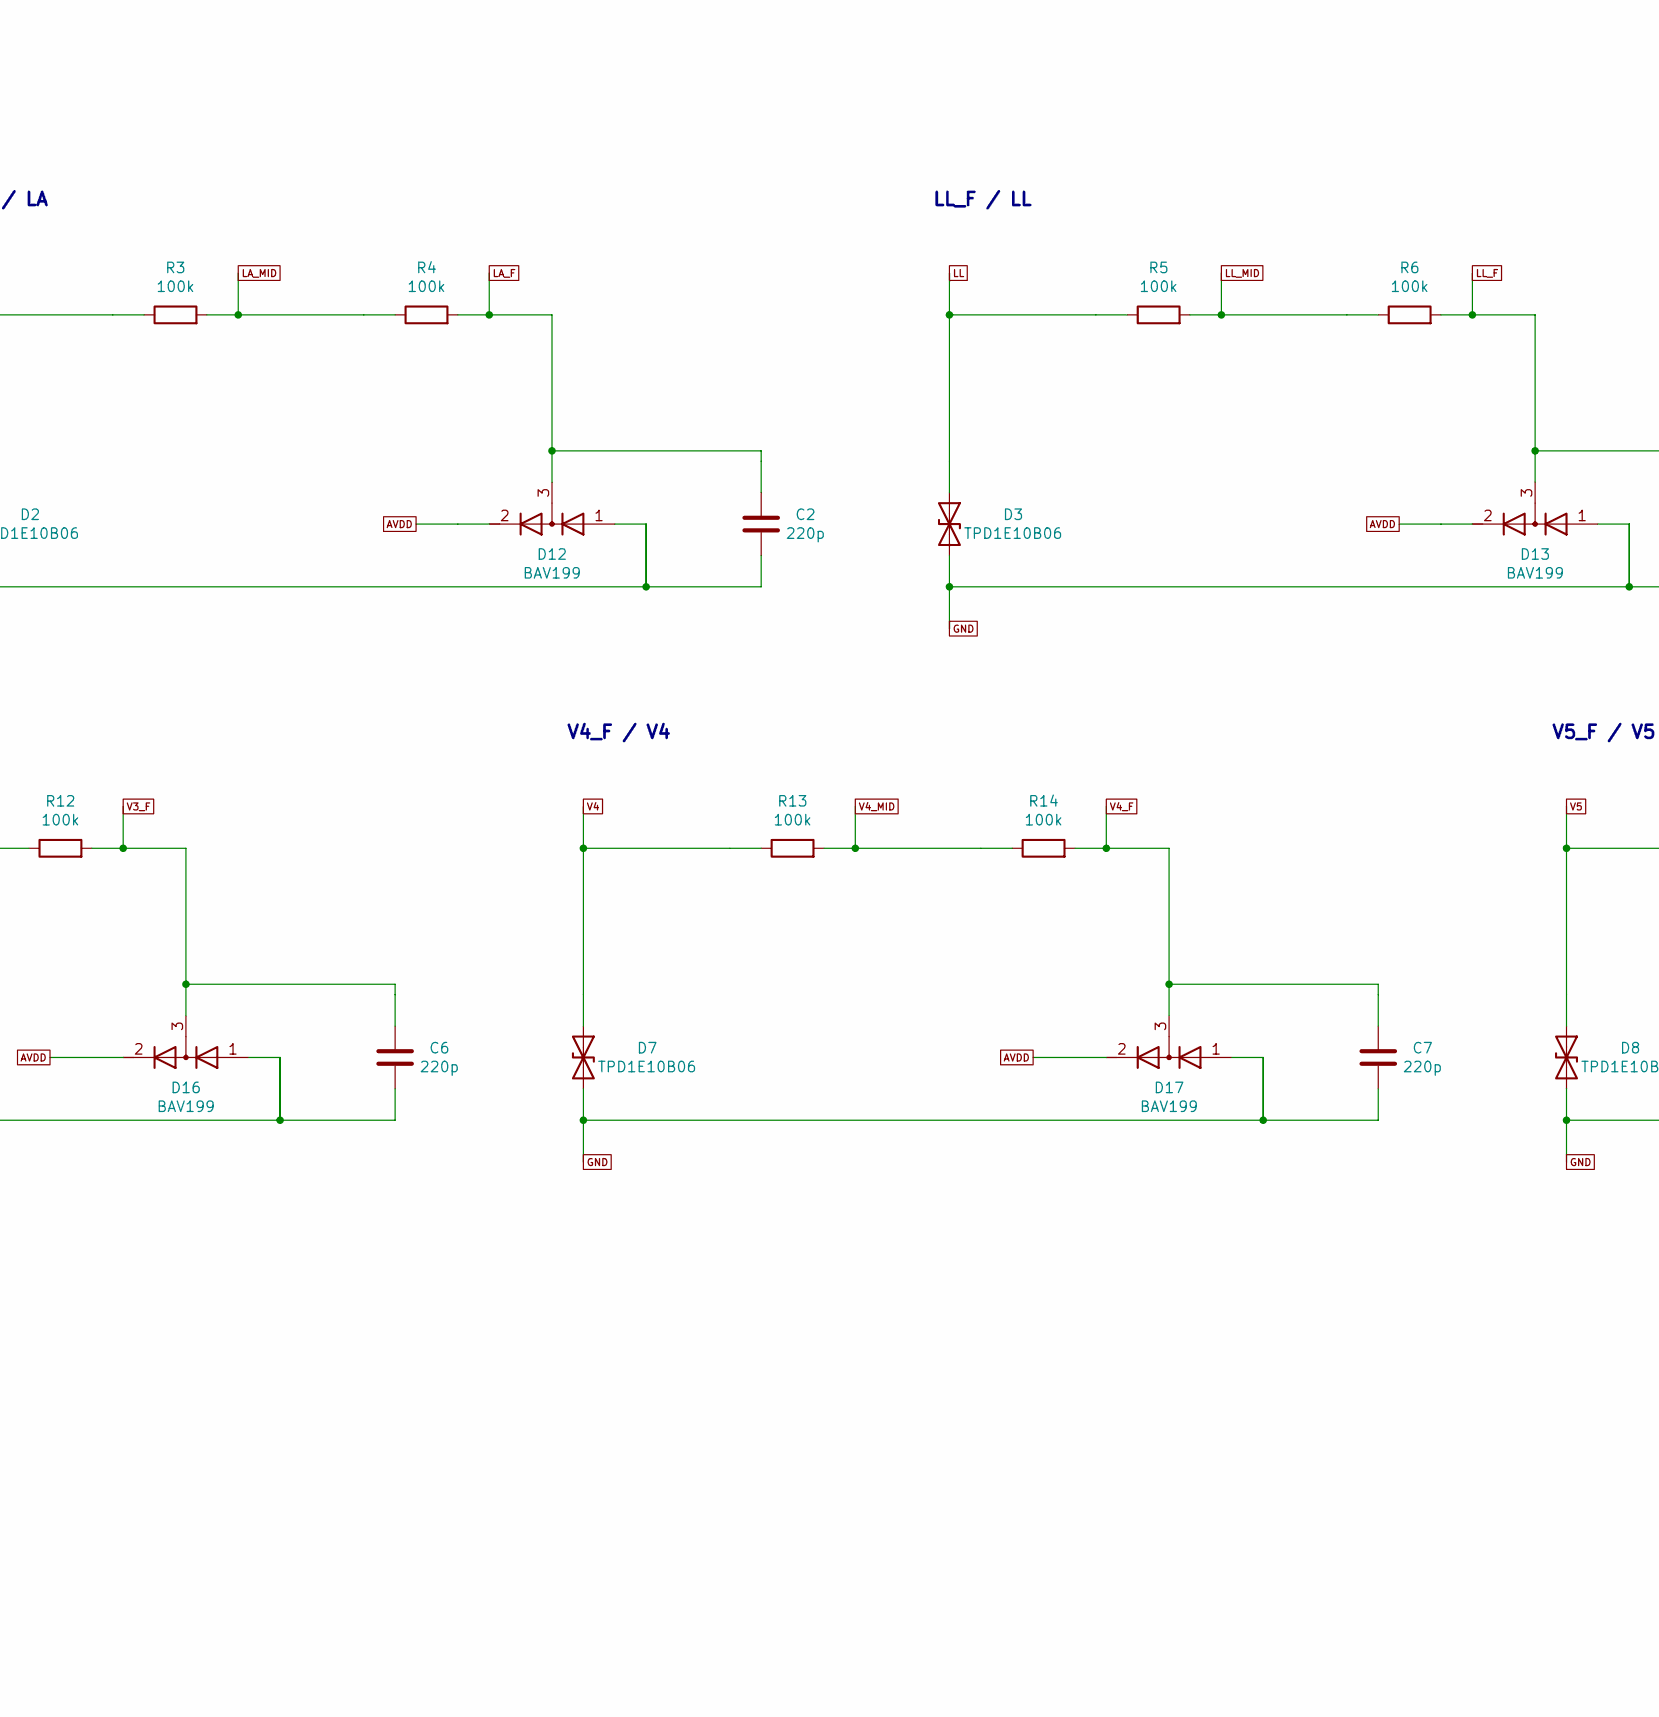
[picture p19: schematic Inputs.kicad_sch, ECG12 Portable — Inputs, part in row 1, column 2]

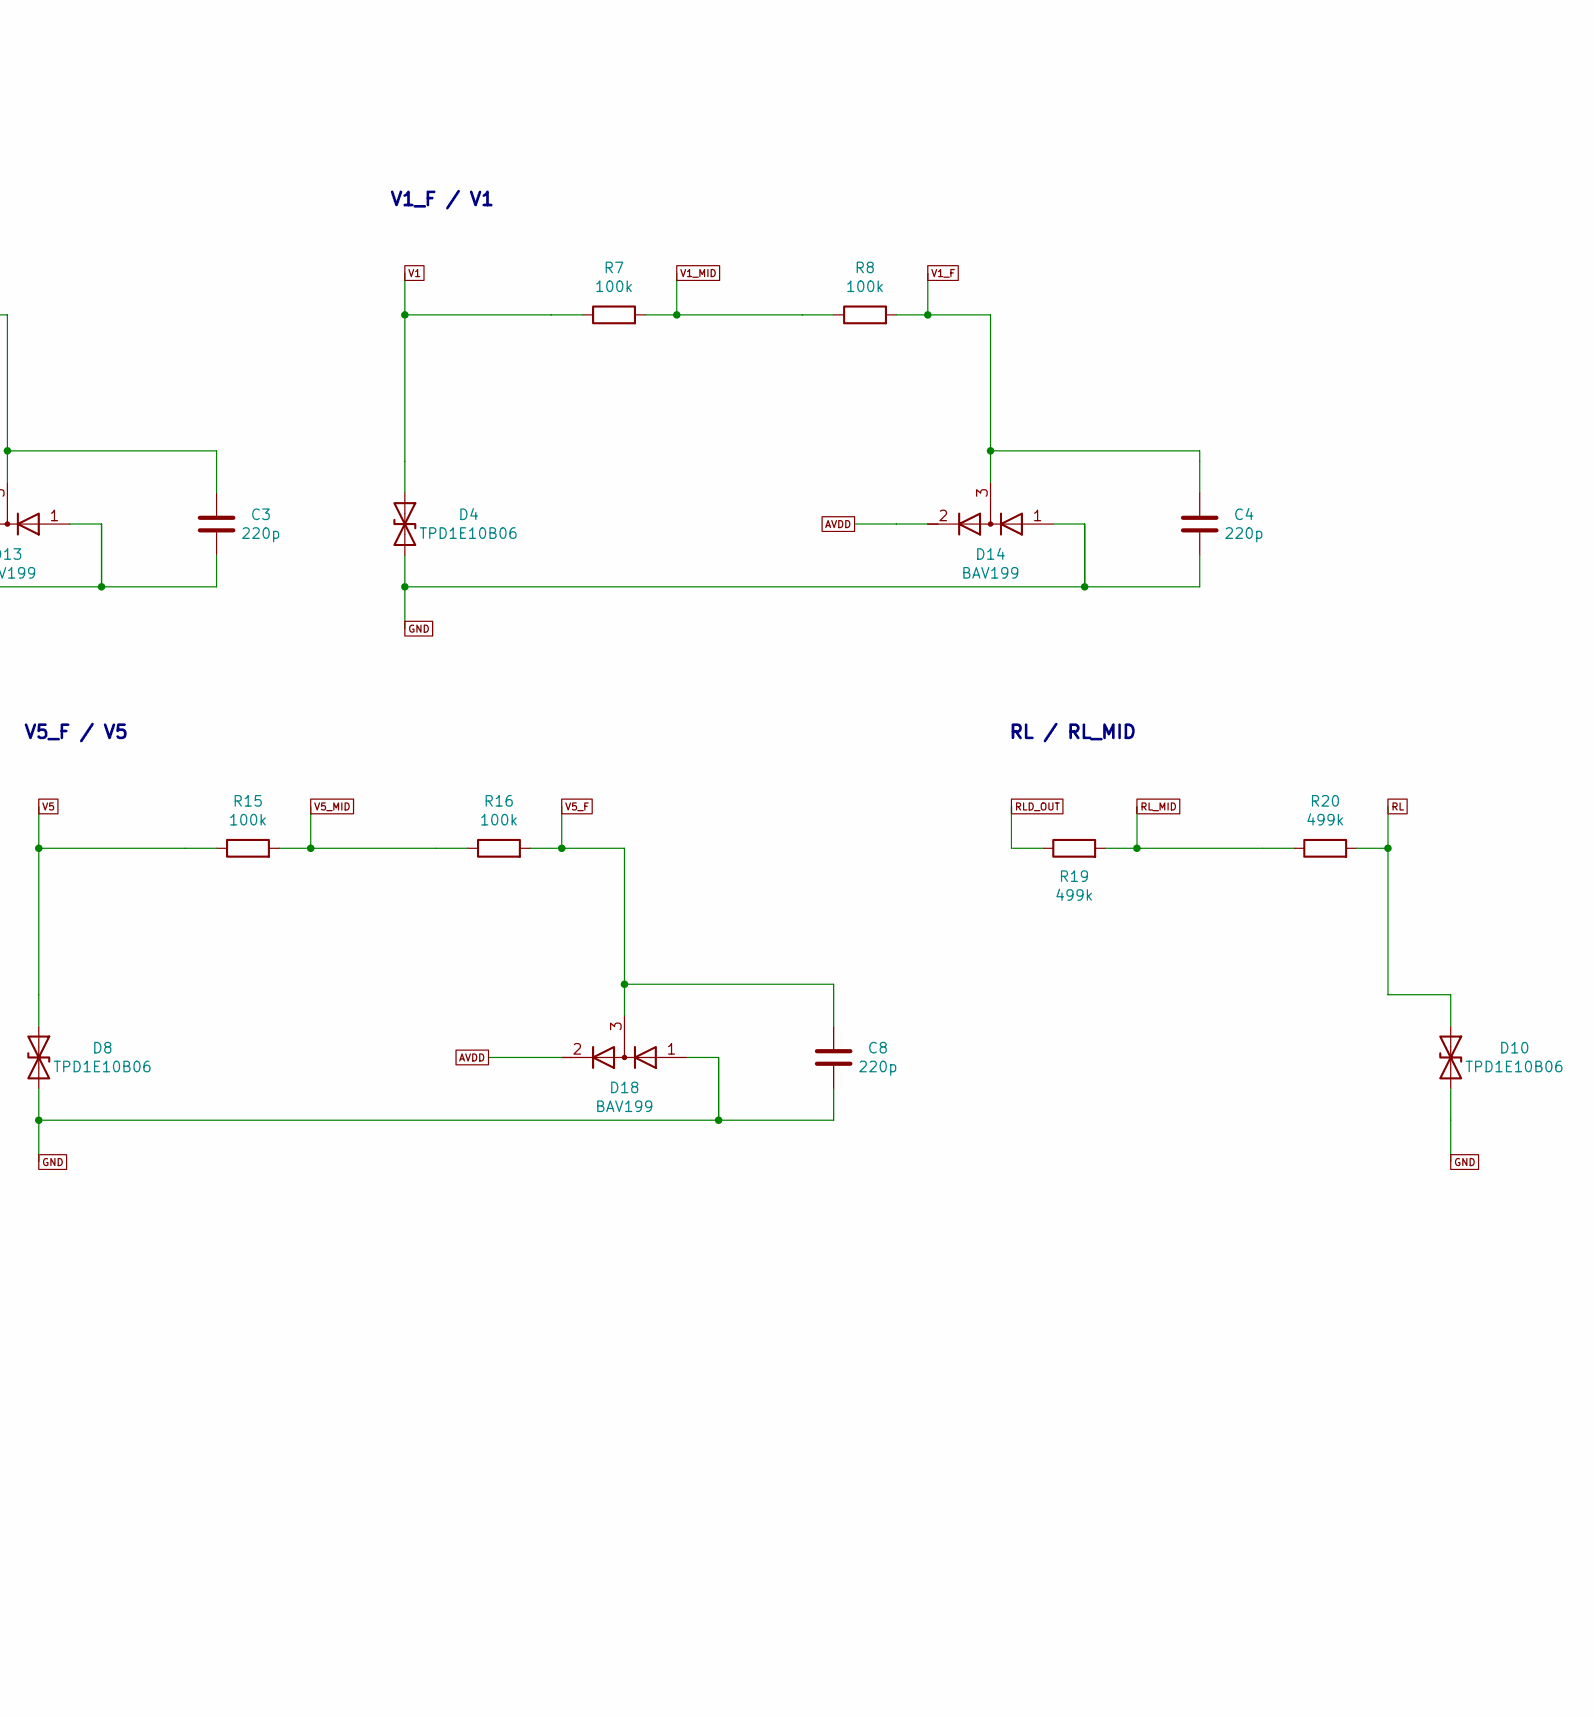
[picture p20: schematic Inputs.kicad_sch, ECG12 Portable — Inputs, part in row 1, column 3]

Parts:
C1: 200p; Capacitor_SMD_C_0402_1005Metric; Tolerance 1%; Voltage 50V; MPN C0402C201F5GACTU
C2, C3, C4, C5, C6, C7, C8, C9: 220p; Capacitor_SMD_C_0402_1005Metric; Tolerance 1%; Voltage 50V; MPN C0402C221F5GACTU
D1, D2, D3, D4, D5, D6, D7, D8, D9, D10: TPD1E10B06; Diode_SMD_D_SOD-523; MPN TPD1E10B06DYAR
D11, D12, D13, D14, D15, D16, D17, D18, D19: BAV199; Package_TO_SOT_SMD_SOT-23; MPN BAV199,215
J1: ELECTRODES; Connector_JST_JST_SH_BM10B-SRSS-TB_1x10-1MP_P1.00mm_Vertical; MPN BM10B-SRSS-TB(LF)(SN)
R1, R2, R3, R4, R5, R6, R7, R8, R9, R10, R11, R12, R13, R14, R15, R16, R17, R18: 100k; Resistor_SMD_R_0402_1005Metric; MPN RT0402BRD07100KL
R19, R20: 499k; Resistor_SMD_R_0603_1608Metric; MPN RC0603FR-07499KL

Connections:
AVDD: D11.2 (K), D12.2 (K), D13.2 (K), D14.2 (K), D15.2 (K), D16.2 (K), D17.2 (K), D18.2 (K), D19.2 (K); also elsewhere on the board
GND: C1.2, C2.2, C3.2, C4.2, C5.2, C6.2, C7.2, C8.2, C9.2, D1.2 (A2), D2.2 (A2), D3.2 (A2), D4.2 (A2), D5.2 (A2), D6.2 (A2), D7.2 (A2), D8.2 (A2), D9.2 (A2), D10.2 (A2), D11.1 (A), D12.1 (A), D13.1 (A), D14.1 (A), D15.1 (A), D16.1 (A), D17.1 (A), D18.1 (A), D19.1 (A); also elsewhere on the board
LA: D2.1 (A1), J1.2, R3.1
LA_F: C2.1, D12.3 (common), R4.2; also elsewhere on the board
LA_MID: R3.2, R4.1
LL: D3.1 (A1), J1.3, R5.1
LL_F: C3.1, D13.3 (common), R6.2; also elsewhere on the board
LL_MID: R5.2, R6.1
RA: D1.1 (A1), J1.1, R1.1
RA_F: C1.1, D11.3 (common), R2.2; also elsewhere on the board
RA_MID: R1.2, R2.1
RL: D10.1 (A1), J1.10, R20.2
RLD_OUT: R19.1; also elsewhere on the board
RL_MID: R19.2, R20.1
V1: D4.1 (A1), J1.4, R7.1
V1_F: C4.1, D14.3 (common), R8.2; also elsewhere on the board
V1_MID: R7.2, R8.1
V2: D5.1 (A1), J1.5, R9.1
V2_F: C5.1, D15.3 (common), R10.2; also elsewhere on the board
V2_MID: R9.2, R10.1
V3: D6.1 (A1), J1.6, R11.1
V3_F: C6.1, D16.3 (common), R12.2; also elsewhere on the board
V3_MID: R11.2, R12.1
V4: D7.1 (A1), J1.7, R13.1
V4_F: C7.1, D17.3 (common), R14.2; also elsewhere on the board
V4_MID: R13.2, R14.1
V5: D8.1 (A1), J1.8, R15.1
V5_F: C8.1, D18.3 (common), R16.2; also elsewhere on the board
V5_MID: R15.2, R16.1
V6: D9.1 (A1), J1.9, R17.1
V6_F: C9.1, D19.3 (common), R18.2; also elsewhere on the board
V6_MID: R17.2, R18.1

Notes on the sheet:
ELECTRODE PROTECTION / MATCHED RF FILTERS
RA/LA/LL and V1-V6: TVS -> 2x100k -> low-leakage clamp -> C0G -> AFE.
All C0G capacitors 50 V. Match total input capacitance during CMRR verification.
RL: 2x499k series output limit. No defibrillator or electrosurgical protection.
J1 - ELECTRODES
RA_F / RA
LA_F / LA
LL_F / LL
V1_F / V1
V2_F / V2
V3_F / V3
V4_F / V4
V5_F / V5
V6_F / V6
RL / RL_MID

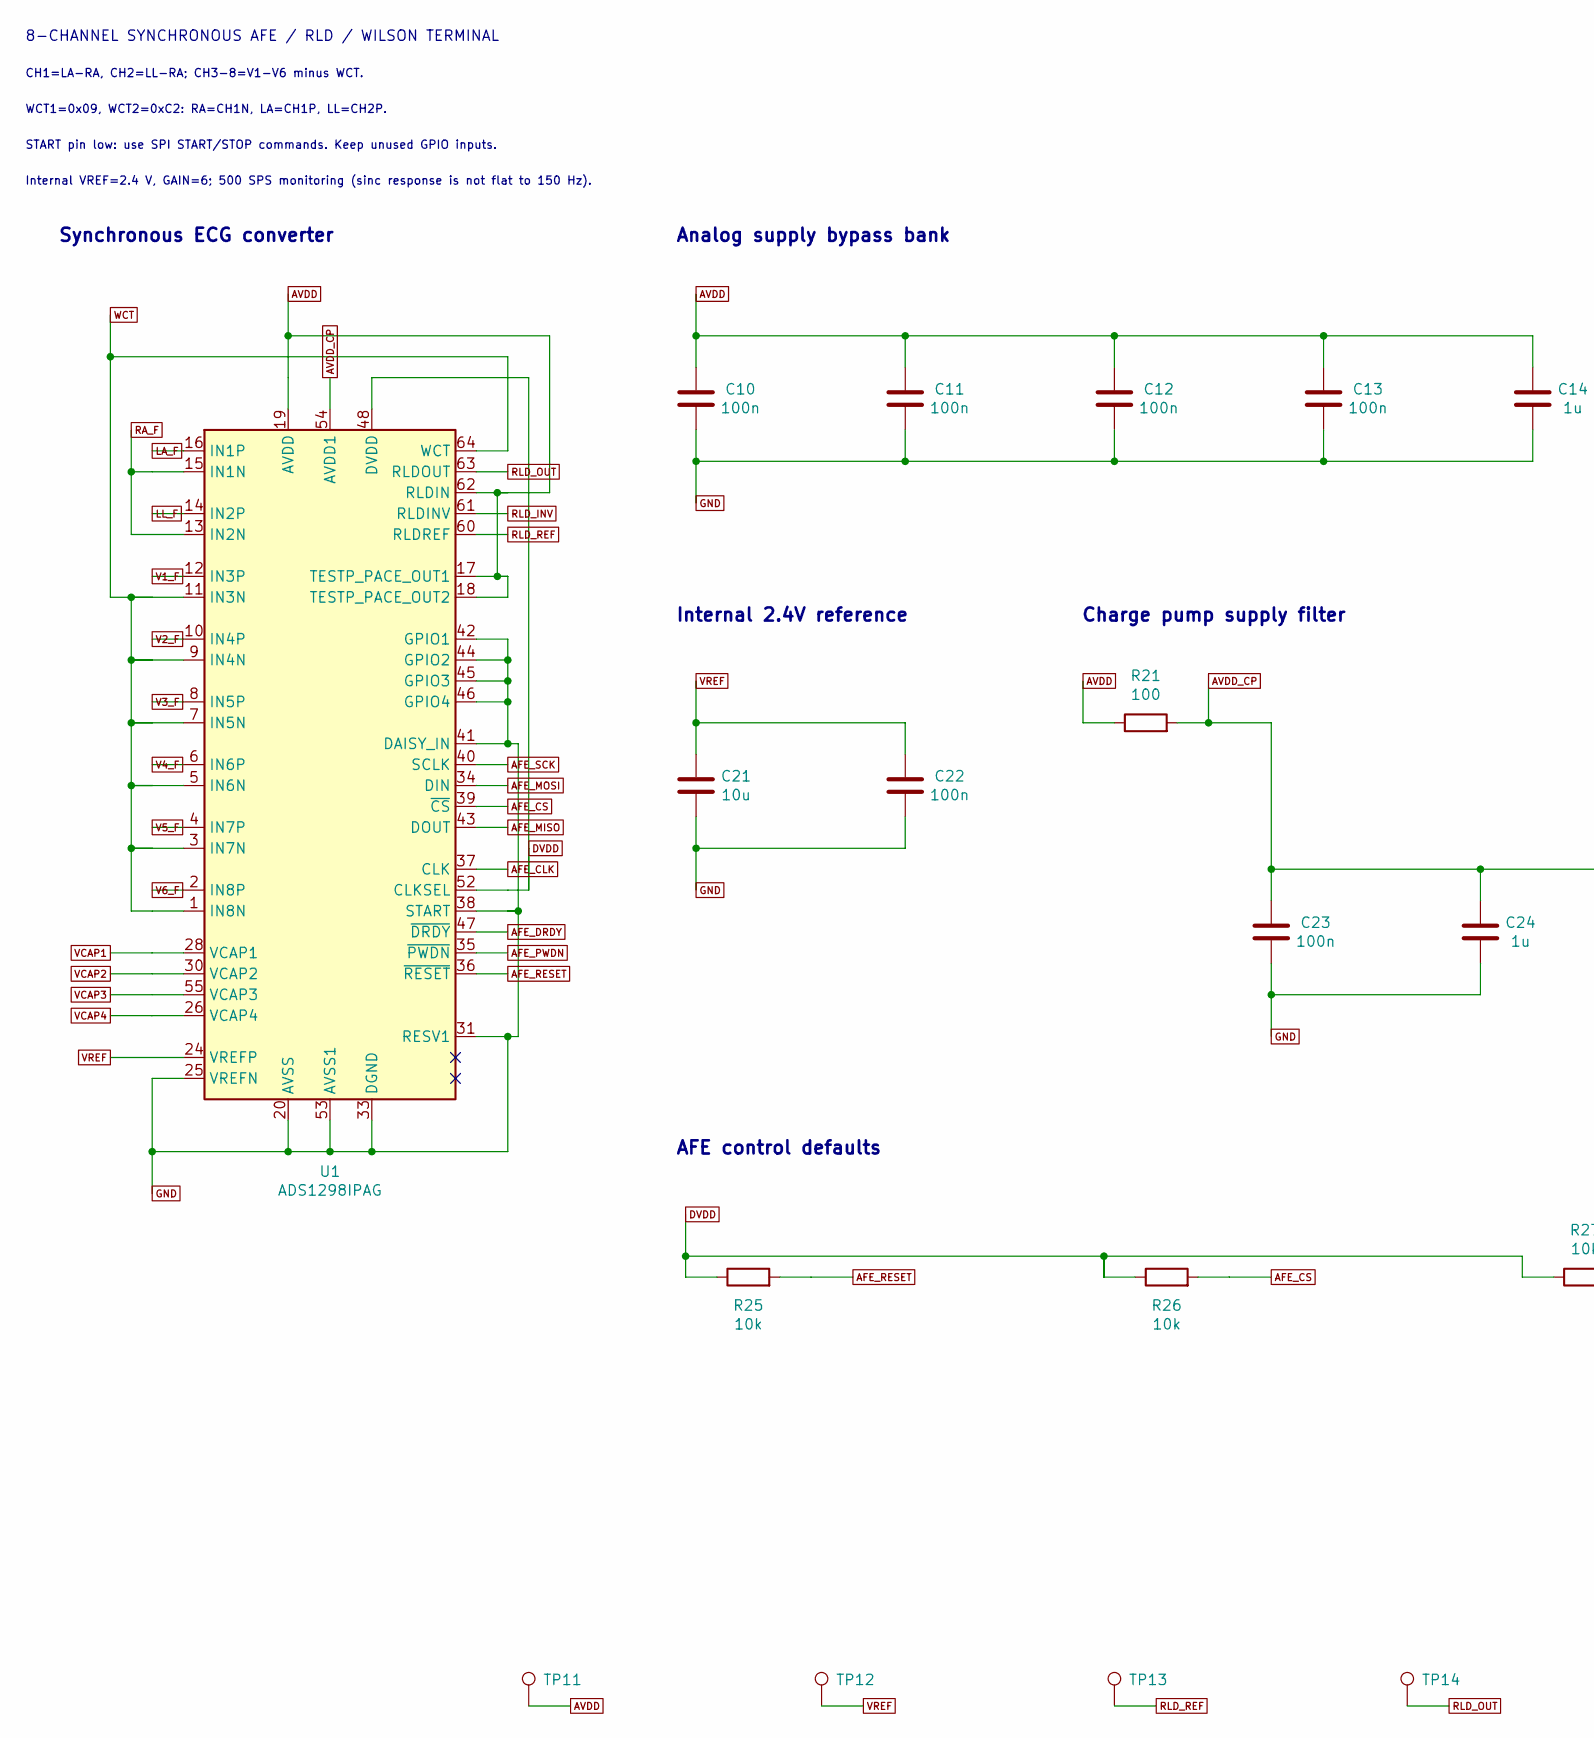
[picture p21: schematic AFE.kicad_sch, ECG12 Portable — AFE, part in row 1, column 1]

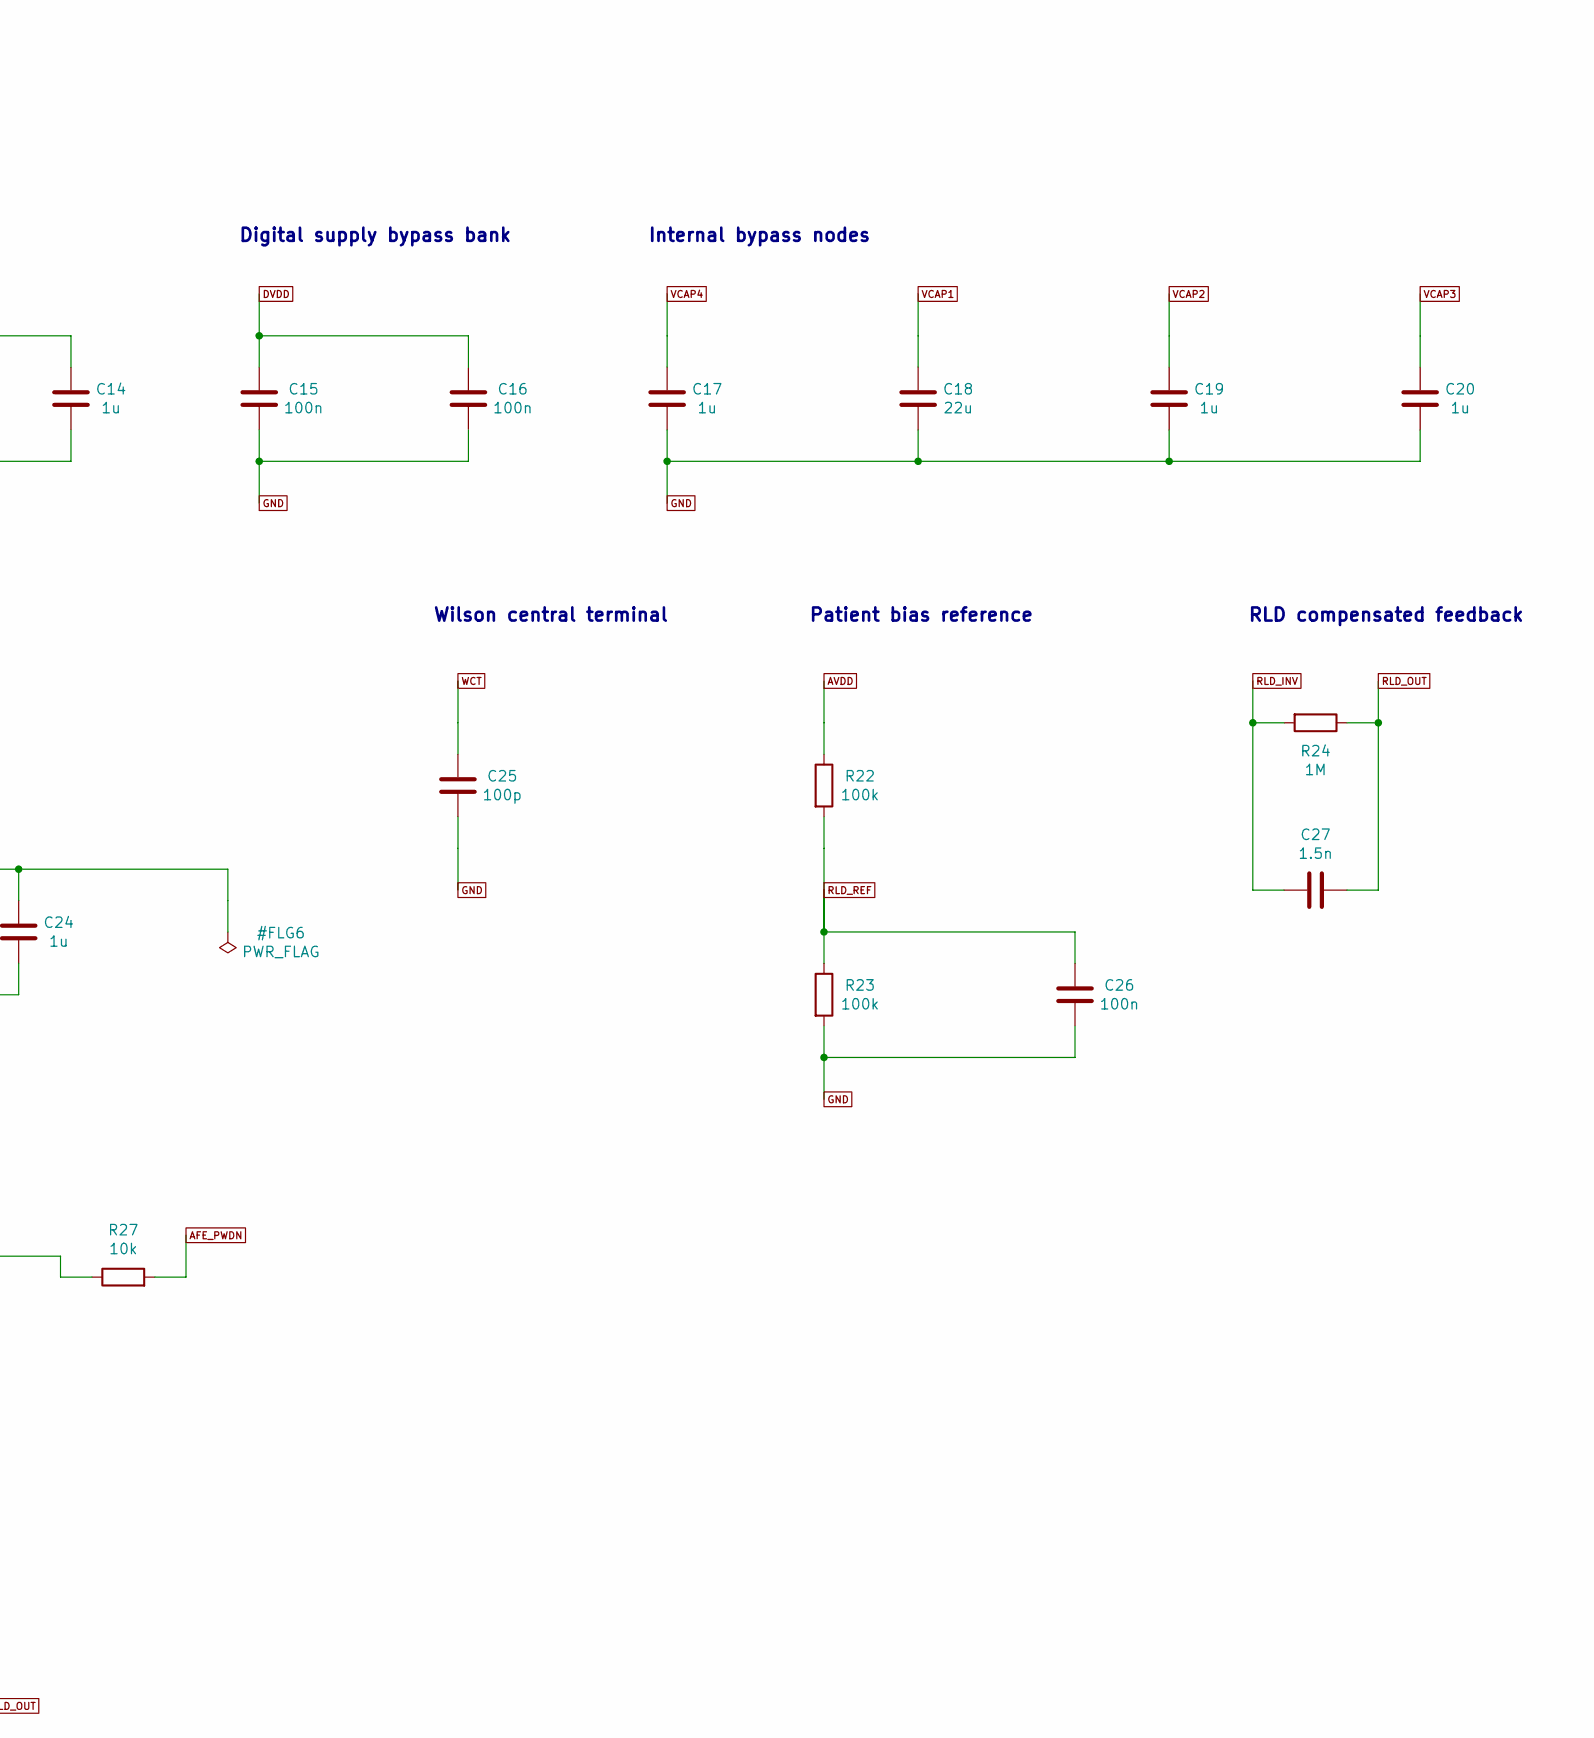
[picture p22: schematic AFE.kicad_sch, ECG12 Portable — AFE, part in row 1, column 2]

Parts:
C10, C11, C12, C13, C15, C16, C22, C23, C26: 100n; Capacitor_SMD_C_0402_1005Metric; MPN GRM155R71C104KA88D
C14, C17, C19, C20, C24: 1u; Capacitor_SMD_C_0402_1005Metric; MPN GRM155R61A105KE15D
C18: 22u; Capacitor_SMD_C_0805_2012Metric; MPN GRM21BR60J226ME39L
C21: 10u; Capacitor_SMD_C_0603_1608Metric; MPN GRM188R60J106ME47D
C25: 100p; Capacitor_SMD_C_0402_1005Metric; MPN GRM1555C1H101JA01D
C27: 1.5n; Capacitor_SMD_C_0603_1608Metric; MPN GRM1885C1H152JA01D
R21: 100; Resistor_SMD_R_0402_1005Metric; MPN RC0402FR-07100RL
R22, R23: 100k; Resistor_SMD_R_0402_1005Metric; MPN RC0402FR-07100KL
R24: 1M; Resistor_SMD_R_0402_1005Metric; MPN RC0402FR-071ML
R25, R26, R27: 10k; Resistor_SMD_R_0402_1005Metric; MPN RC0402FR-0710KL
TP11: AVDD; TestPoint_TestPoint_Pad_D1.0mm; MPN TEST_PAD_1MM
TP12: VREF; TestPoint_TestPoint_Pad_D1.0mm; MPN TEST_PAD_1MM
TP13: RLD_REF; TestPoint_TestPoint_Pad_D1.0mm; MPN TEST_PAD_1MM
TP14: RLD_OUT; TestPoint_TestPoint_Pad_D1.0mm; MPN TEST_PAD_1MM
U1: ADS1298IPAG; Package_QFP_TQFP-64_10x10mm_P0.5mm; MPN ADS1298IPAG

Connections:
AFE_CLK: U1.37 (CLK); also elsewhere on the board
AFE_CS: R26.2, U1.39 (~CS); also elsewhere on the board
AFE_DRDY: U1.47 (~DRDY); also elsewhere on the board
AFE_MISO: U1.43 (DOUT); also elsewhere on the board
AFE_MOSI: U1.34 (DIN); also elsewhere on the board
AFE_PWDN: R27.2, U1.35 (~PWDN); also elsewhere on the board
AFE_RESET: R25.2, U1.36 (~RESET); also elsewhere on the board
AFE_SCK: U1.40 (SCLK); also elsewhere on the board
AVDD: C10.1, C11.1, C12.1, C13.1, C14.1, R21.1, R22.1, TP11.1, U1.17 (TESTP_PACE_OUT1), U1.18 (TESTP_PACE_OUT2), U1.19 (AVDD), U1.21 (AVDD), U1.22 (AVDD), U1.56 (AVDD), U1.59 (AVDD), U1.62 (RLDIN); also elsewhere on the board
AVDD_CP: C23.1, C24.1, R21.2, U1.54 (AVDD1)
DVDD: C15.1, C16.1, R25.1, R26.1, R27.1, U1.48 (DVDD), U1.50 (DVDD), U1.52 (CLKSEL); also elsewhere on the board
GND: C10.2, C11.2, C12.2, C13.2, C14.2, C15.2, C16.2, C17.2, C18.2, C19.2, C20.2, C21.2, C22.2, C23.2, C24.2, C25.2, C26.2, R23.2, U1.20 (AVSS), U1.23 (AVSS), U1.25 (VREFN), U1.31 (RESV1), U1.32 (AVSS), U1.33 (DGND), U1.38 (START), U1.41 (DAISY_IN), U1.42 (GPIO1), U1.44 (GPIO2), U1.45 (GPIO3), U1.46 (GPIO4), U1.49 (DGND), U1.51 (DGND), U1.53 (AVSS1), U1.57 (AVSS), U1.58 (AVSS); also elsewhere on the board
LA_F: U1.16 (IN1P); also elsewhere on the board
LL_F: U1.14 (IN2P); also elsewhere on the board
RA_F: U1.13 (IN2N), U1.15 (IN1N); also elsewhere on the board
RLD_INV: C27.2, R24.2, U1.61 (RLDINV)
RLD_OUT: C27.1, R24.1, TP14.1, U1.63 (RLDOUT); also elsewhere on the board
RLD_REF: C26.1, R22.2, R23.1, TP13.1, U1.60 (RLDREF)
V1_F: U1.12 (IN3P); also elsewhere on the board
V2_F: U1.10 (IN4P); also elsewhere on the board
V3_F: U1.8 (IN5P); also elsewhere on the board
V4_F: U1.6 (IN6P); also elsewhere on the board
V5_F: U1.4 (IN7P); also elsewhere on the board
V6_F: U1.2 (IN8P); also elsewhere on the board
VCAP1: C18.1, U1.28 (VCAP1)
VCAP2: C19.1, U1.30 (VCAP2)
VCAP3: C20.1, U1.55 (VCAP3)
VCAP4: C17.1, U1.26 (VCAP4)
VREF: C21.1, C22.1, TP12.1, U1.24 (VREFP)
WCT: C25.1, U1.1 (IN8N), U1.3 (IN7N), U1.5 (IN6N), U1.7 (IN5N), U1.9 (IN4N), U1.11 (IN3N), U1.64 (WCT)

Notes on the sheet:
8-CHANNEL SYNCHRONOUS AFE / RLD / WILSON TERMINAL
CH1=LA-RA, CH2=LL-RA; CH3-8=V1-V6 minus WCT.
WCT1=0x09, WCT2=0xC2: RA=CH1N, LA=CH1P, LL=CH2P.
START pin low: use SPI START/STOP commands. Keep unused GPIO inputs.
Internal VREF=2.4 V, GAIN=6; 500 SPS monitoring (sinc response is not flat to 150 Hz).
Synchronous ECG converter
Analog supply bypass bank
Digital supply bypass bank
Internal bypass nodes
Internal 2.4V reference
Charge pump supply filter
Wilson central terminal
Patient bias reference
RLD compensated feedback
AFE control defaults

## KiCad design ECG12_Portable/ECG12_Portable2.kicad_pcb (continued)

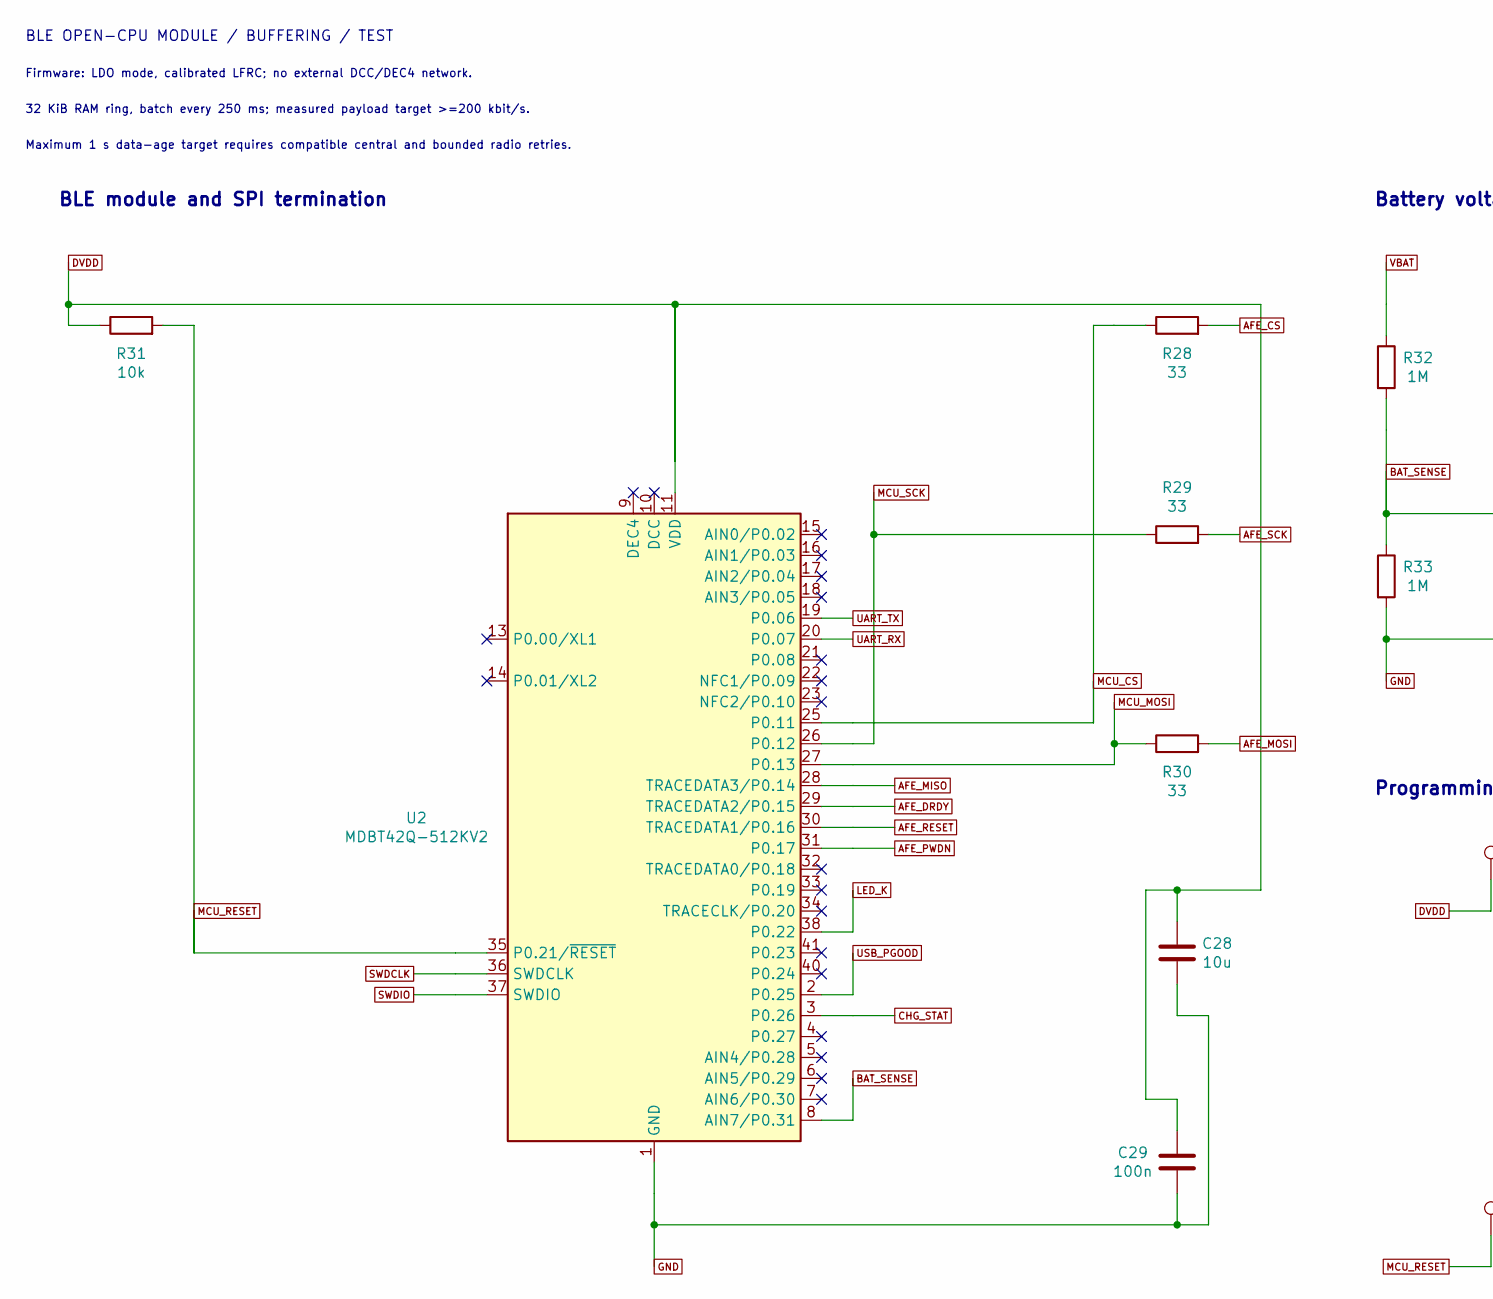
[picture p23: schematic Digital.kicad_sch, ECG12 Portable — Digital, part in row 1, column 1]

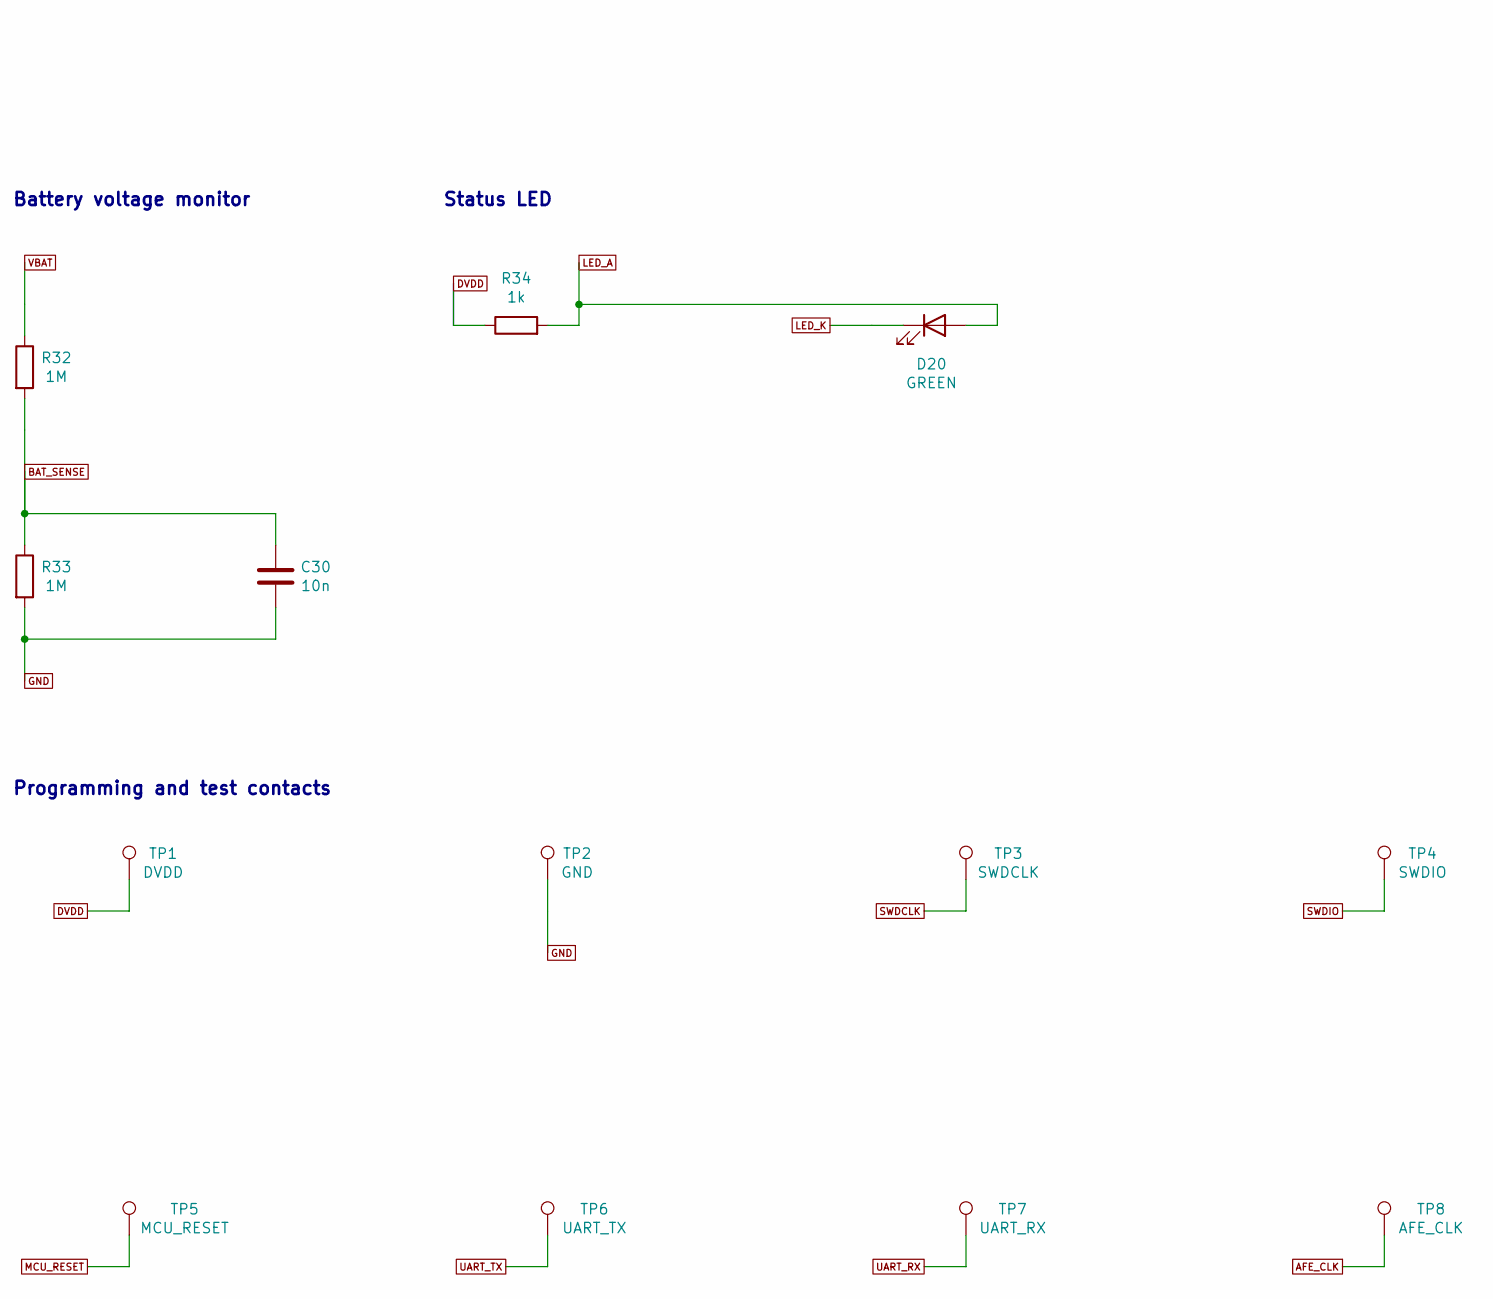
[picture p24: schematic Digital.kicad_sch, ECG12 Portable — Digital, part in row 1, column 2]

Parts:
C28: 10u; Capacitor_SMD_C_0603_1608Metric; MPN GRM188R60J106ME47D
C29: 100n; Capacitor_SMD_C_0402_1005Metric; MPN GRM155R71C104KA88D
C30: 10n; Capacitor_SMD_C_0402_1005Metric; MPN GRM155R71C103KA01D
D20: GREEN; LED_SMD_LED_0603_1608Metric; MPN LTST-C190KGKT
R28, R29, R30: 33; Resistor_SMD_R_0402_1005Metric; MPN RC0402FR-0733RL
R31: 10k; Resistor_SMD_R_0402_1005Metric; MPN RC0402FR-0710KL
R32, R33: 1M; Resistor_SMD_R_0402_1005Metric; MPN RC0402FR-071ML
R34: 1k; Resistor_SMD_R_0402_1005Metric; MPN RC0402FR-071KL
TP1: DVDD; TestPoint_TestPoint_Pad_D1.0mm; MPN TEST_PAD_1MM
TP2: GND; TestPoint_TestPoint_Pad_D1.0mm; MPN TEST_PAD_1MM
TP3: SWDCLK; TestPoint_TestPoint_Pad_D1.0mm; MPN TEST_PAD_1MM
TP4: SWDIO; TestPoint_TestPoint_Pad_D1.0mm; MPN TEST_PAD_1MM
TP5: MCU_RESET; TestPoint_TestPoint_Pad_D1.0mm; MPN TEST_PAD_1MM
TP6: UART_TX; TestPoint_TestPoint_Pad_D1.0mm; MPN TEST_PAD_1MM
TP7: UART_RX; TestPoint_TestPoint_Pad_D1.0mm; MPN TEST_PAD_1MM
TP8: AFE_CLK; TestPoint_TestPoint_Pad_D1.0mm; MPN TEST_PAD_1MM
U2: MDBT42Q-512KV2; RF_Module_Raytac_MDBT42Q; MPN MDBT42Q-512KV2

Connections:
AFE_CLK: TP8.1; also elsewhere on the board
AFE_CS: R28.2; also elsewhere on the board
AFE_DRDY: U2.29 (TRACEDATA2/P0.15); also elsewhere on the board
AFE_MISO: U2.28 (TRACEDATA3/P0.14); also elsewhere on the board
AFE_MOSI: R30.2; also elsewhere on the board
AFE_PWDN: U2.31 (P0.17); also elsewhere on the board
AFE_RESET: U2.30 (TRACEDATA1/P0.16); also elsewhere on the board
AFE_SCK: R29.2; also elsewhere on the board
BAT_SENSE: C30.1, R32.2, R33.1, U2.8 (AIN7/P0.31)
CHG_STAT: U2.3 (P0.26); also elsewhere on the board
DVDD: C28.1, C29.1, R31.1, R34.1, TP1.1, U2.11 (VDD); also elsewhere on the board
GND: C28.2, C29.2, C30.2, R33.2, TP2.1, U2.1 (GND), U2.12 (GND), U2.24 (GND), U2.39 (GND); also elsewhere on the board
LED_A: D20.2 (A), R34.2
LED_K: D20.1 (K), U2.38 (P0.22)
MCU_CS: R28.1, U2.25 (P0.11)
MCU_MOSI: R30.1, U2.27 (P0.13)
MCU_RESET: R31.2, TP5.1, U2.35 (P0.21/~RESET)
MCU_SCK: R29.1, U2.26 (P0.12)
SWDCLK: TP3.1, U2.36 (SWDCLK)
SWDIO: TP4.1, U2.37 (SWDIO)
UART_RX: TP7.1, U2.20 (P0.07)
UART_TX: TP6.1, U2.19 (P0.06)
USB_PGOOD: U2.2 (P0.25); also elsewhere on the board
VBAT: R32.1; also elsewhere on the board

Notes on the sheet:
BLE OPEN-CPU MODULE / BUFFERING / TEST
Firmware: LDO mode, calibrated LFRC; no external DCC/DEC4 network.
32 KiB RAM ring, batch every 250 ms; measured payload target >=200 kbit/s.
Maximum 1 s data-age target requires compatible central and bounded radio retries.
BLE module and SPI termination
Battery voltage monitor
Status LED
Programming and test contacts

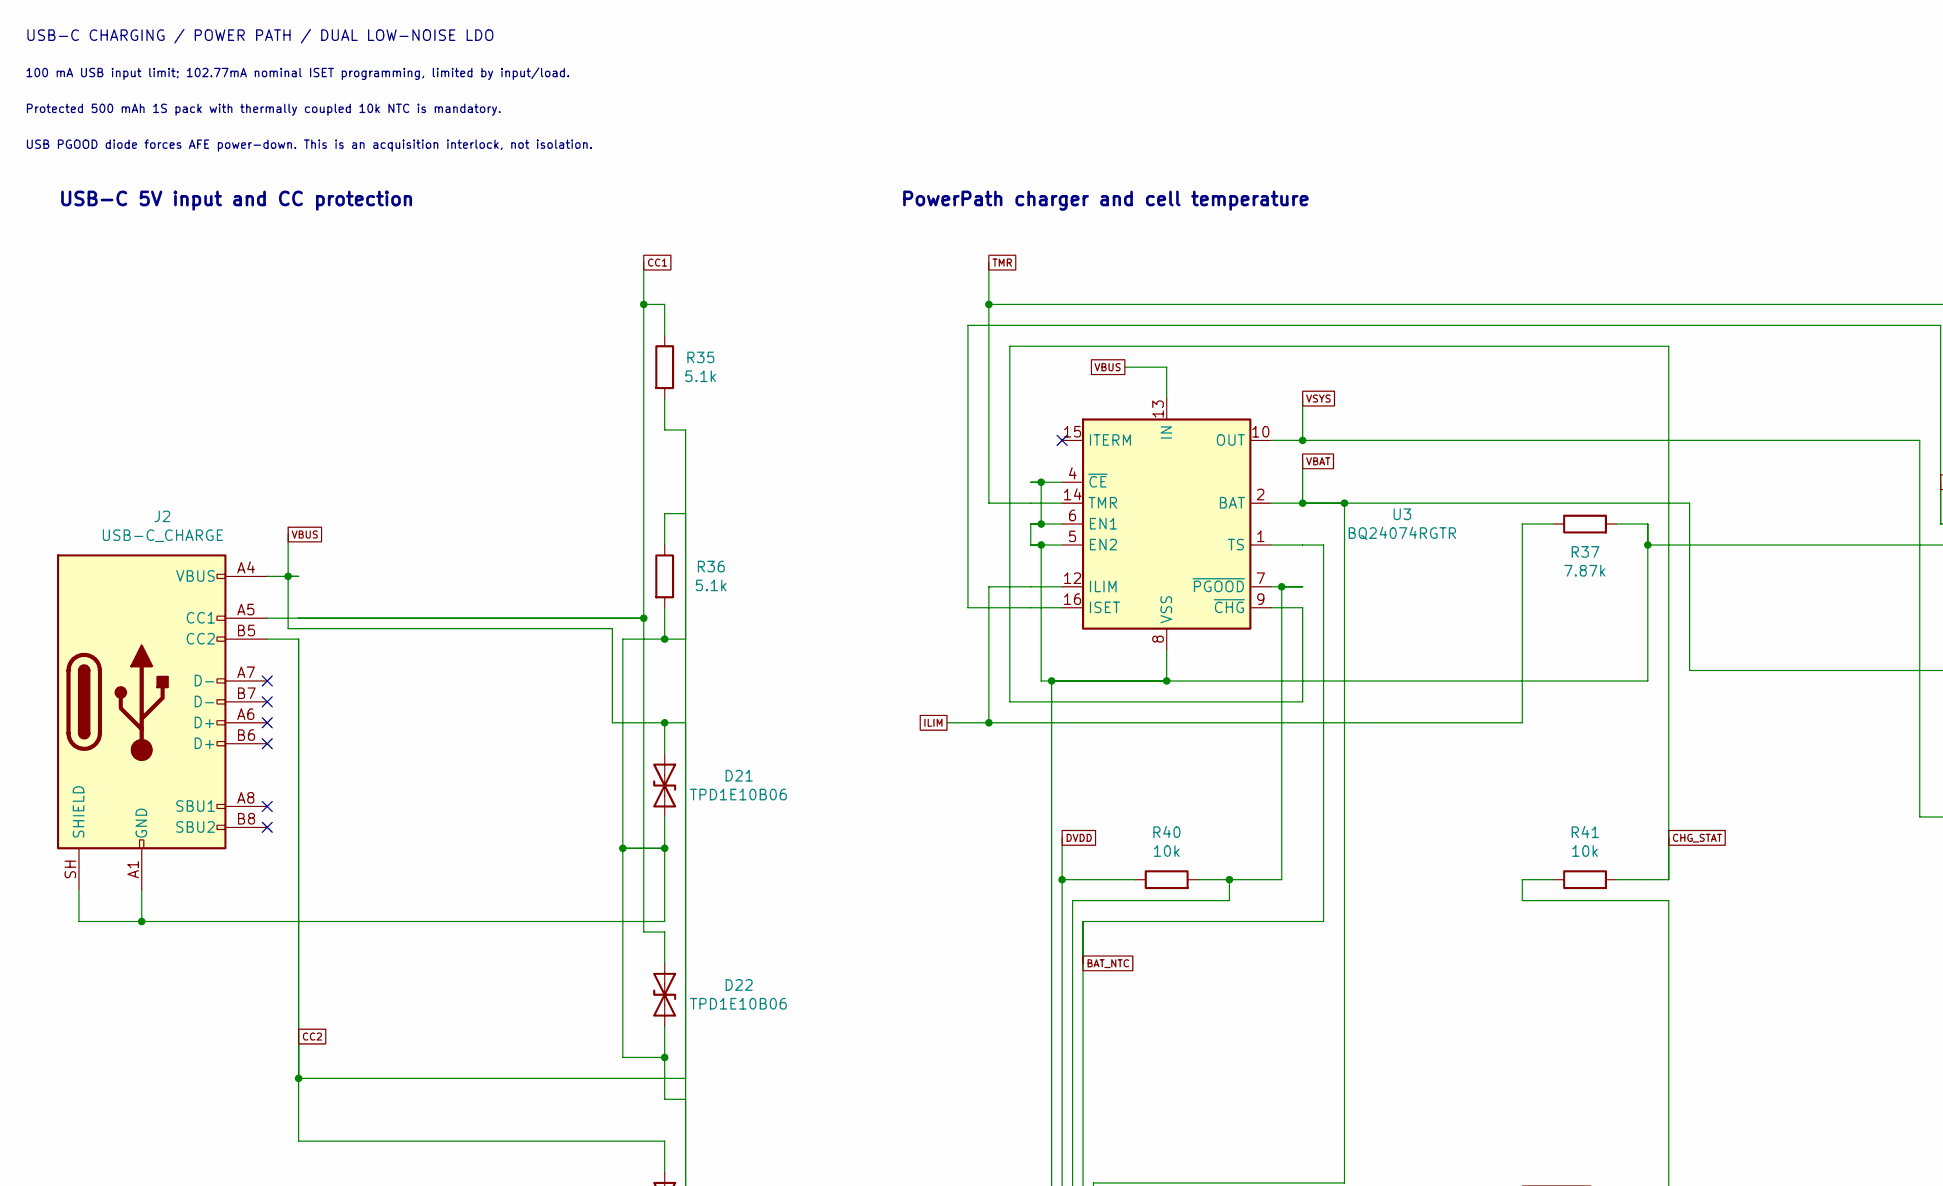
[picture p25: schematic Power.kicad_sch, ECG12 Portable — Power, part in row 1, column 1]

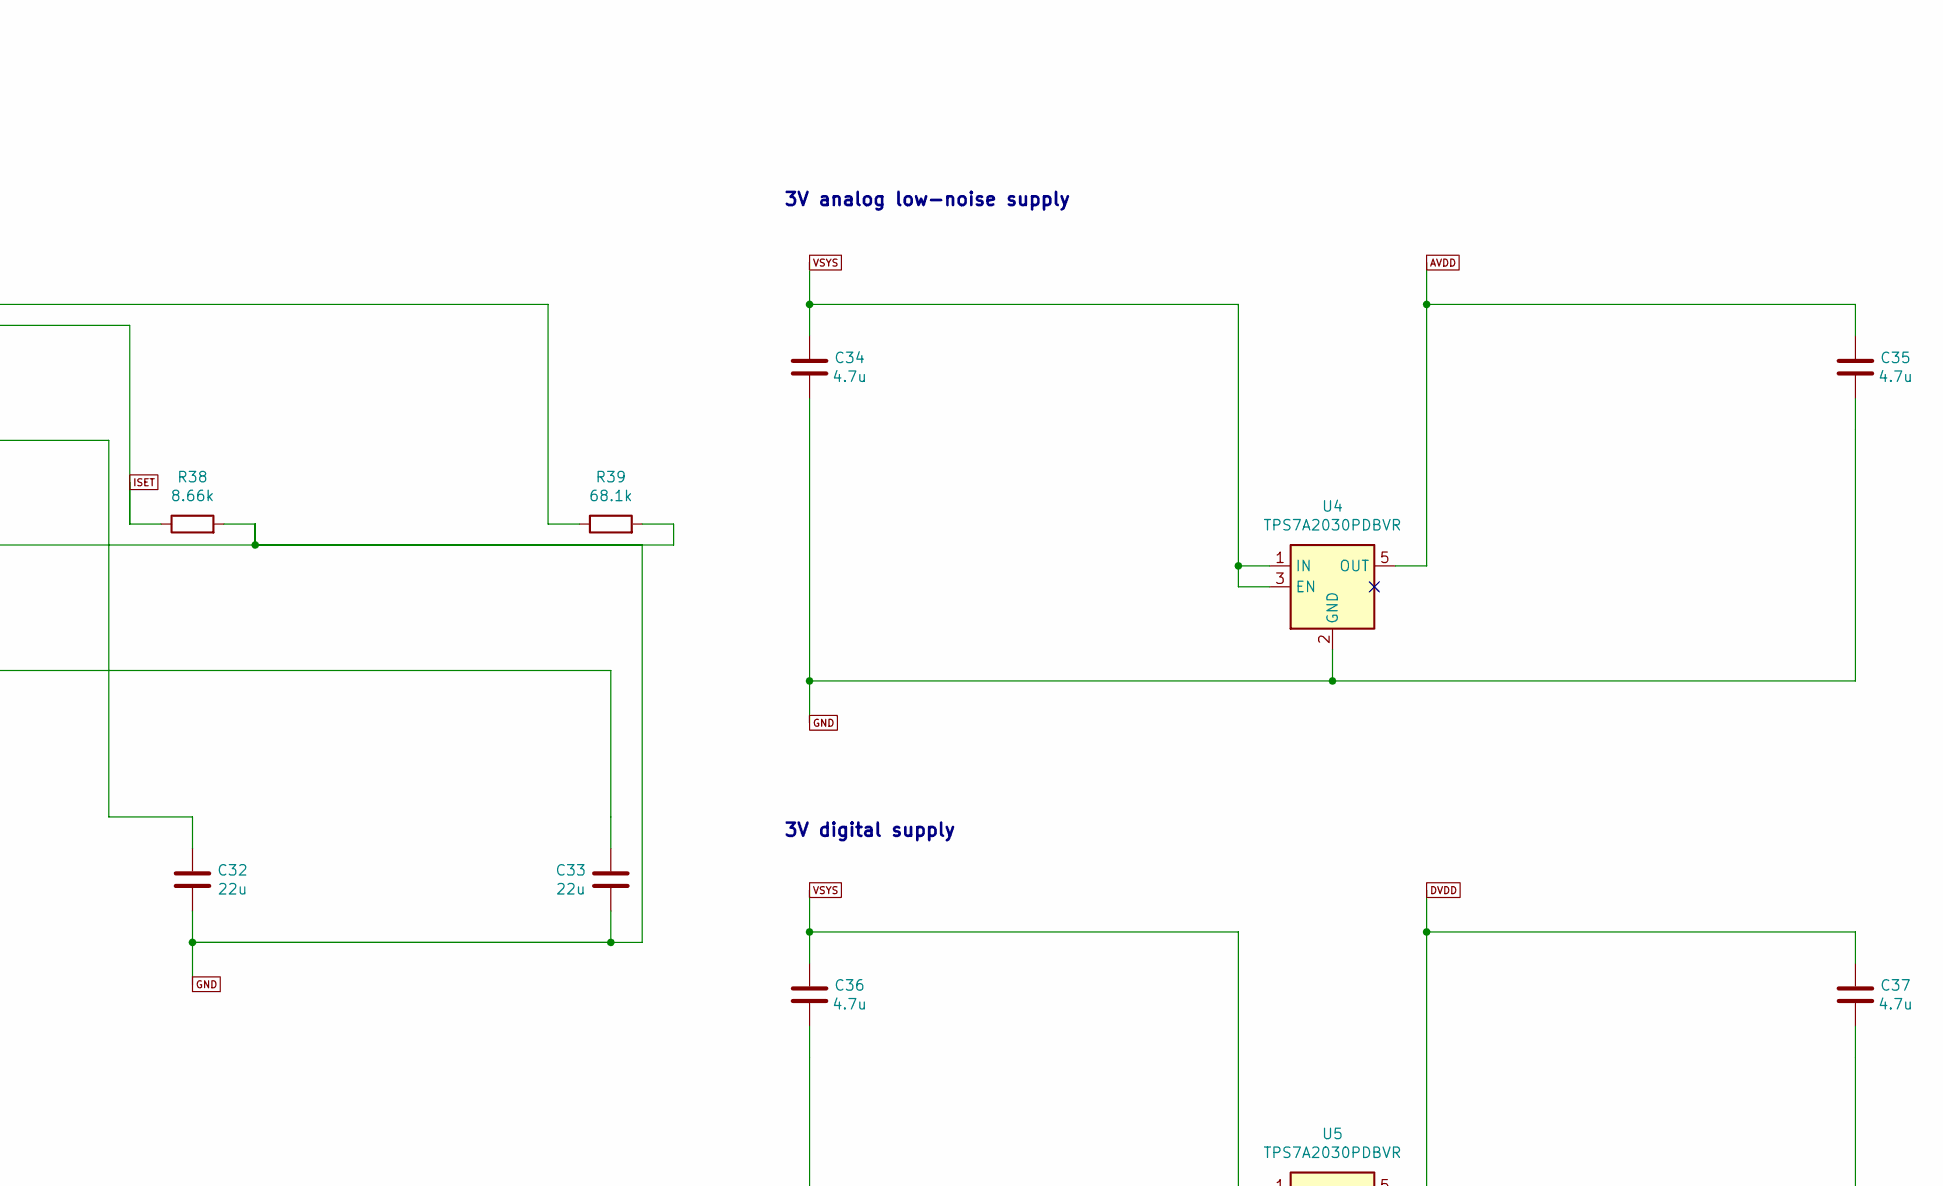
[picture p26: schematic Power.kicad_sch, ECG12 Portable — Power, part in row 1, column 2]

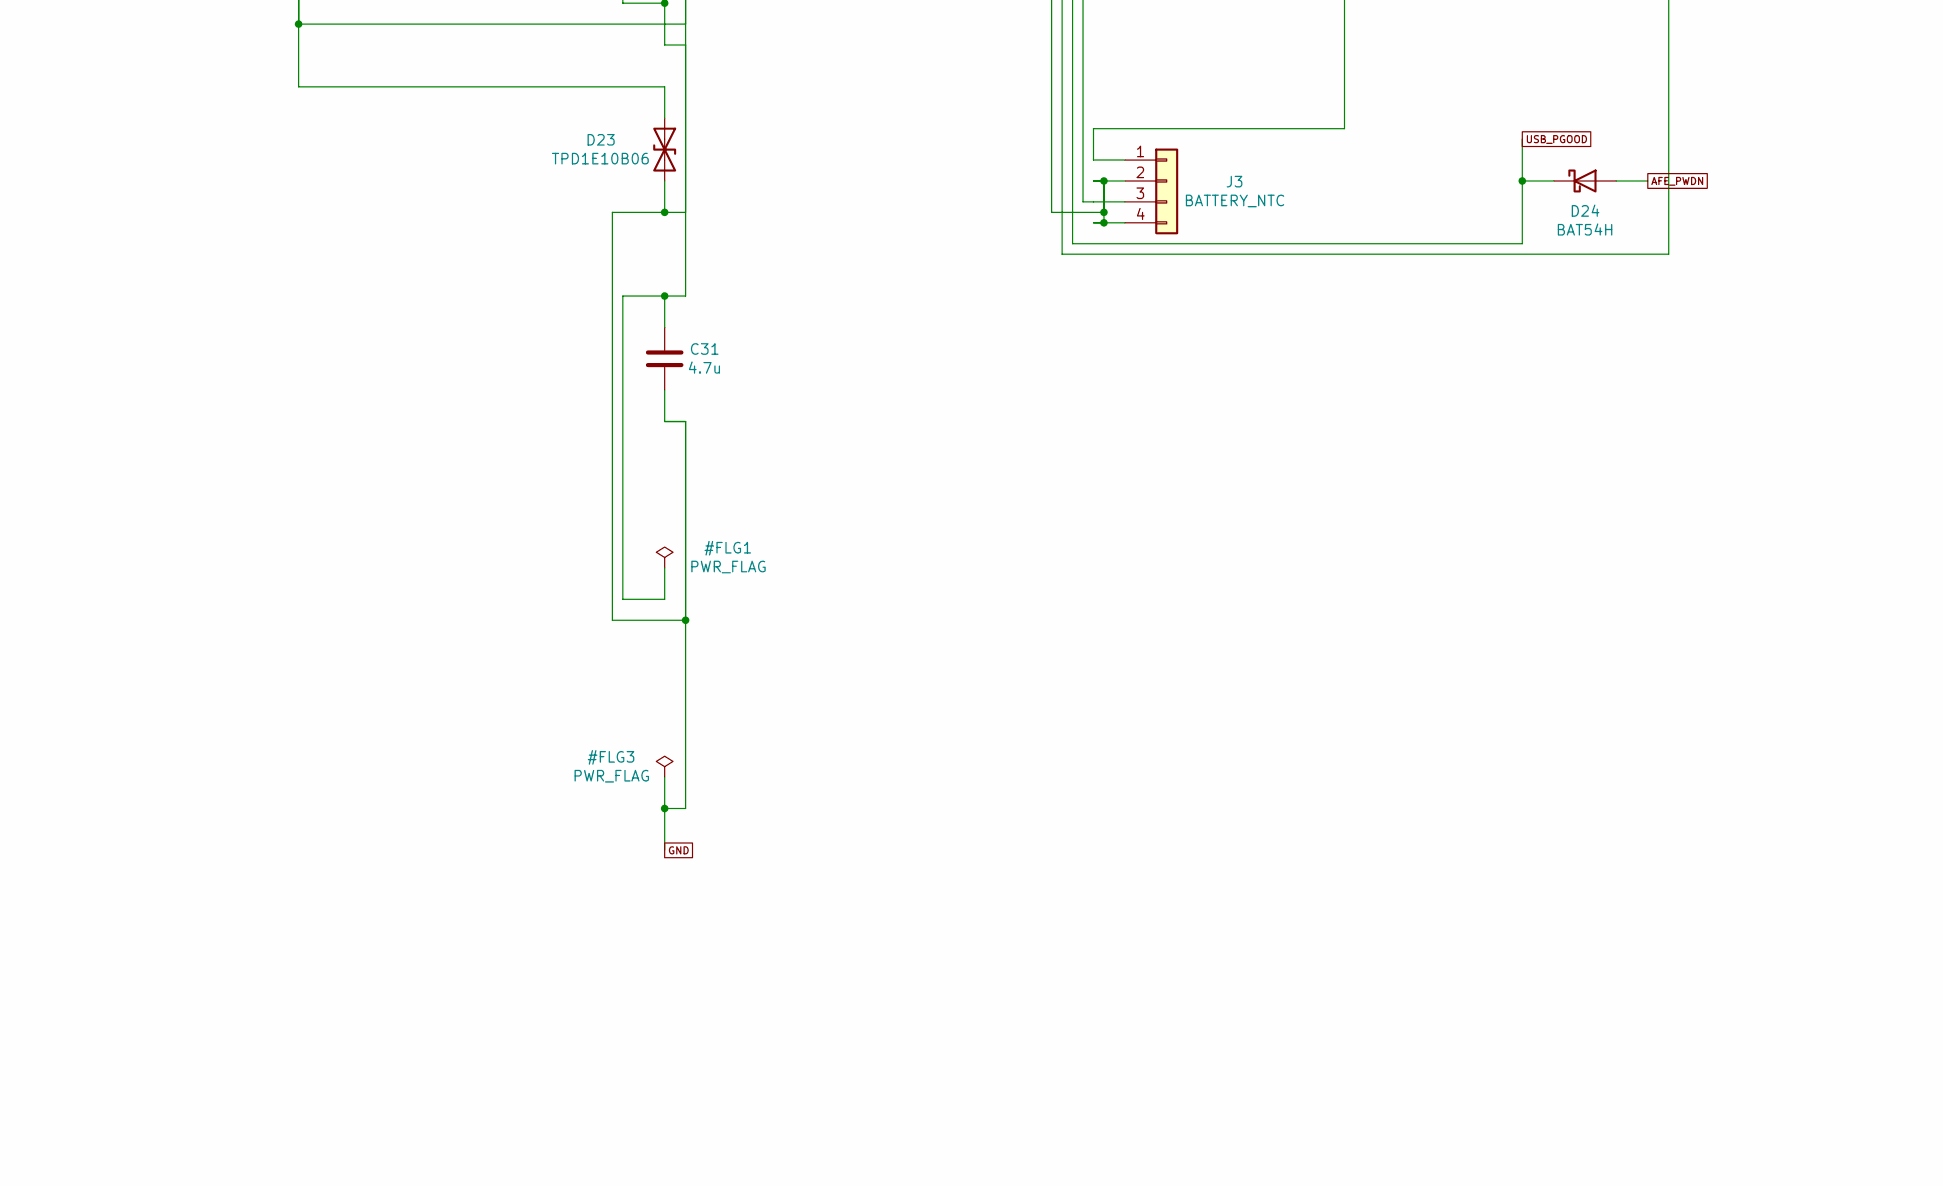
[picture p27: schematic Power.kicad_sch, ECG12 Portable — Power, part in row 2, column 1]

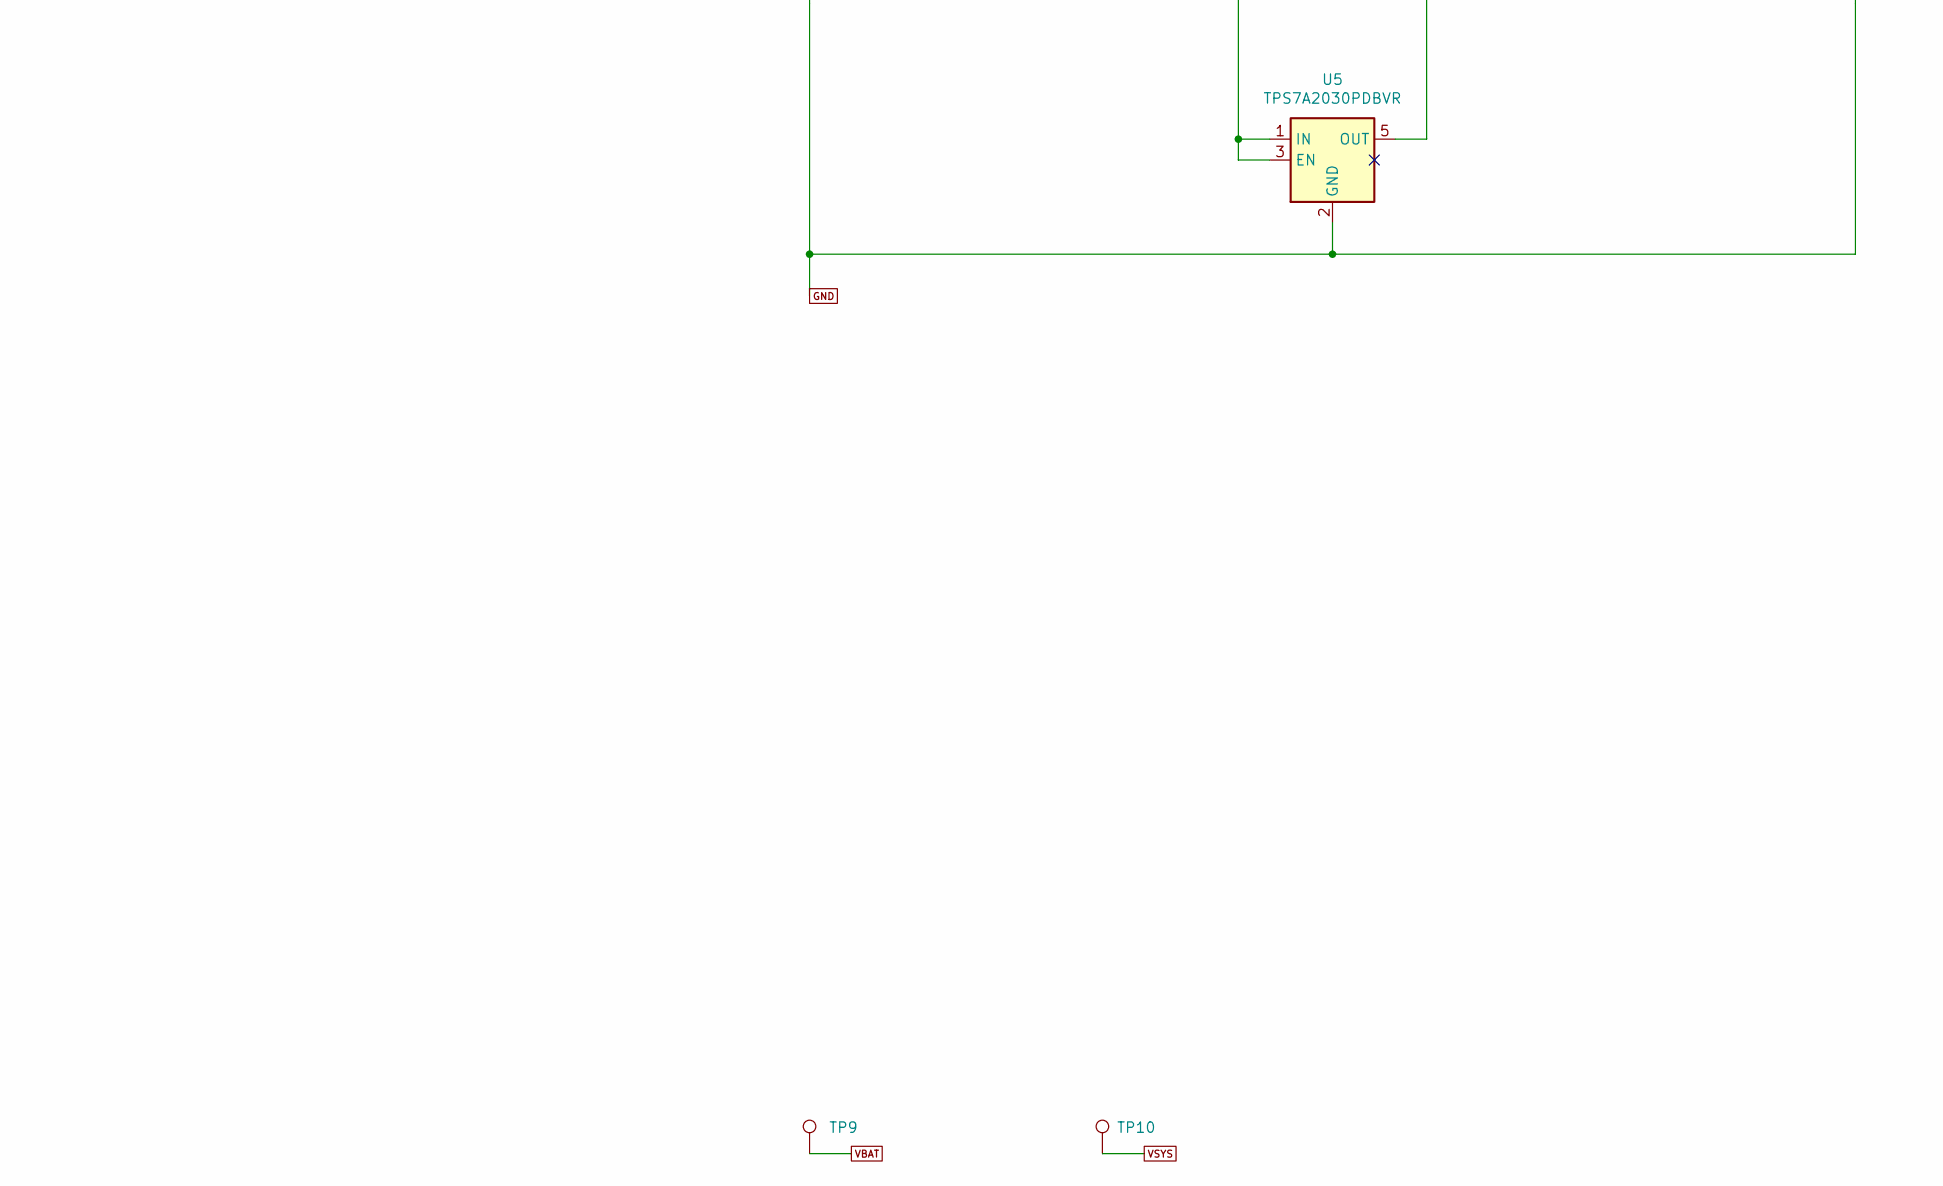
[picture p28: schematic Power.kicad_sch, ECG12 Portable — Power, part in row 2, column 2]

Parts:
C31, C34, C35, C36, C37: 4.7u; Capacitor_SMD_C_0603_1608Metric; Voltage 16V; Tolerance 10%; MPN C1608X5R1C475K080AC
C32, C33: 22u; Capacitor_SMD_C_0805_2012Metric; Voltage 25V; Tolerance 20%; MPN C2012X5R1E226M125AC
D21, D22, D23: TPD1E10B06; Diode_SMD_D_SOD-523; MPN TPD1E10B06DYAR
D24: BAT54H; Diode_SMD_D_SOD-123F; MPN BAT54H,115
J2: USB-C_CHARGE; Connector_USB_USB_C_Receptacle_HRO_TYPE-C-31-M-12; MPN TYPE-C-31-M-12
J3: BATTERY_NTC; Connector_JST_JST_SH_BM04B-SRSS-TB_1x04-1MP_P1.00mm_Vertical; MPN BM04B-SRSS-TB(LF)(SN)
R35, R36: 5.1k; Resistor_SMD_R_0402_1005Metric; MPN RC0402FR-075K1L
R37: 7.87k; Resistor_SMD_R_0402_1005Metric; MPN RC0402FR-077K87L
R38: 8.66k; Resistor_SMD_R_0402_1005Metric; MPN RC0402FR-078K66L
R39: 68.1k; Resistor_SMD_R_0402_1005Metric; MPN RC0402FR-0768K1L
R40, R41: 10k; Resistor_SMD_R_0402_1005Metric; MPN RC0402FR-0710KL
TP9: VBAT; TestPoint_TestPoint_Pad_D1.0mm; MPN TEST_PAD_1MM
TP10: VSYS; TestPoint_TestPoint_Pad_D1.0mm; MPN TEST_PAD_1MM
U3: BQ24074RGTR; Package_DFN_QFN_VQFN-16-1EP_3x3mm_P0.5mm_EP1.6x1.6mm; MPN BQ24074RGTR
U4, U5: TPS7A2030PDBVR; Package_TO_SOT_SMD_SOT-23-5; MPN TPS7A2030PDBVR

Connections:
AFE_PWDN: D24.2 (A); also elsewhere on the board
AVDD: C35.1, U4.5 (OUT); also elsewhere on the board
BAT_NTC: J3.3, U3.1 (TS)
CC1: D22.1 (A1), J2.A5 (CC1), R35.1
CC2: D23.1 (A1), J2.B5 (CC2), R36.1
CHG_STAT: R41.2, U3.9 (~CHG); also elsewhere on the board
DVDD: C37.1, R40.1, R41.1, U5.5 (OUT); also elsewhere on the board
GND: C31.2, C32.2, C33.2, C34.2, C35.2, C36.2, C37.2, D21.2 (A2), D22.2 (A2), D23.2 (A2), J2.A1 (GND), J2.A12 (GND), J2.B1 (GND), J2.B12 (GND), J2.SH (SHIELD), J3.2, J3.4, R35.2, R36.2, R37.2, R38.2, R39.2, U3.4 (~CE), U3.5 (EN2), U3.6 (EN1), U3.8 (VSS), U3.17 (VSS), U4.2 (GND), U5.2 (GND); also elsewhere on the board
ILIM: R37.1, U3.12 (ILIM)
ISET: R38.1, U3.16 (ISET)
TMR: R39.1, U3.14 (TMR)
USB_PGOOD: D24.1 (K), R40.2, U3.7 (~PGOOD); also elsewhere on the board
VBAT: C33.1, J3.1, TP9.1, U3.2 (BAT), U3.3 (BAT); also elsewhere on the board
VBUS: C31.1, D21.1 (A1), J2.A4 (VBUS), J2.A9 (VBUS), J2.B4 (VBUS), J2.B9 (VBUS), U3.13 (IN)
VSYS: C32.1, C34.1, C36.1, TP10.1, U3.10 (OUT), U3.11 (OUT), U4.1 (IN), U4.3 (EN), U5.1 (IN), U5.3 (EN)

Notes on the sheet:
USB-C CHARGING / POWER PATH / DUAL LOW-NOISE LDO
100 mA USB input limit; 102.77mA nominal ISET programming, limited by input/load.
Protected 500 mAh 1S pack with thermally coupled 10k NTC is mandatory.
USB PGOOD diode forces AFE power-down. This is an acquisition interlock, not isolation.
USB-C 5V input and CC protection
PowerPath charger and cell temperature
3V analog low-noise supply
3V digital supply



Board: 4 copper layers, 45.0 x 45.0 mm, 130 parts (19 on the bottom side), 72 nets.

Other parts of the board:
FID1, FID2, FID3, FID4, FID5, FID6: FIDUCIAL; Fiducial_Fiducial_1mm_Mask2mm
